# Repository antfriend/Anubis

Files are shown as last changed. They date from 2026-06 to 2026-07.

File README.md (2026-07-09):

# Anubis RC Controller Daughterboard

**A compact open-hardware support board for a DIY ESP32-S3 RC transmitter.**

Anubis is an open hardware and open firmware RC controller project built around accessible DIY parts, modern radio-control features, and a design that builders can understand, repair, modify, and improve.

This repository contains the custom daughterboard for the Anubis controller. It sits under a Hosyond 2.8 inch ESP32-S3 display board and turns the early wiring-heavy prototype into a cleaner, more repeatable hardware platform.

## Mission

The goal is simple: make a capable, repairable, hackable transmitter that is not locked behind a black box.

The first Anubis prototype used off-the-shelf modules wired together by hand: display board, power switches, regulators, analog input boards, GPIO expanders, gimbal connectors, and radio wiring. That is a great way to prove an idea, but it gets messy fast. This daughterboard pulls those support circuits onto a purpose-built PCB while leaving the Hosyond ESP32-S3 board as the main brain, display, touch interface, and firmware target.

Anubis is meant for experimentation as much as use. Builders should be able to change pin mappings, adapt connectors, swap radio hardware, and tune the firmware for their own transmitter layout.

## At A Glance

| Area | Current Direction |
| --- | --- |
| Main controller | Hosyond 2.8 inch ESP32-S3 display/dev board |
| Battery system | 2S LiPo or two 18650 cells as a 2S pack |
| Charging input | USB-C 5 V input, 500 mA to 1.5 A charge target |
| Switched outputs | `+5V_SW` and `+3V3_SW` accessory rails |
| Analog inputs | Two onboard ADS1115 ADCs, up to 8 analog channels |
| GPIO expansion | MCP23017 16-bit I2C GPIO expander |
| Radio paths | ELRS/CRSF over UART and optional ESP-NOW |
| Assembly goal | As much JLCPCB assembly as practical |
| Project status | Prototype hardware, ready for assembled-board validation |

## Core Design Goals

- Use common, hobby-accessible parts where possible.
- Keep the project open enough for community modification.
- Support modern RC workflows such as ELRS and ESP-NOW.
- Reduce hand wiring compared with the early prototype.
- Make the board practical for JLCPCB assembly.
- Keep external accessory power switchable from firmware.
- Leave room for manual wiring where real-world modules and harnesses vary.

## Hardware Overview

The daughterboard adds the support electronics around the Hosyond ESP32-S3 board:

- USB-C 5 V input for charging and power input.
- Standard 2S LiPo balance connector for the battery pack.
- Support for a 2S LiPo pack or two 18650 cells configured as a 2S pack.
- 2S battery gauge/protection circuitry based around `BQ28Z610DRZR-R1`.
- Dual-FET protection/power path using `CSD83325L`.
- Switched 5 V rail for UART/ELRS-side accessories.
- Switched 3.3 V rail for I2C, analog, and low-voltage peripherals.
- Two Pololu mini pushbutton power switch modules for rail control.
- Two onboard ADS1115 ADC circuits for up to eight analog inputs.
- One onboard MCP23017 GPIO expander for buttons and digital expansion.
- JST and pin-header breakouts for UART, I2C, GPIO, gimbals, and accessories.
- ESD protection for external signal connections.
- Ground plane and wider routing rules for higher-current power paths.

## Power Rails

| Rail | Intended Use | Approximate Max Current |
| --- | --- | --- |
| USB-C input | 5 V charge/input source | 500 mA to 1.5 A charge target |
| `+5V_SW` | ELRS/UART-side accessory power | about 1 A |
| `+3V3_SW` | I2C, ADCs, MCP23017, gimbals, sensors | about 500 mA |

The switched rails are controlled through the two Pololu #2808 mini pushbutton power switch modules. The ESP32-S3 can shut down attached devices without relying on the attached devices to behave nicely.

## Firmware Map

The main Anubis firmware runs on the Hosyond ESP32-S3 board. Current daughterboard-aware firmware support includes:

- Touchscreen UI for transmitter settings.
- Model storage and configuration.
- Stick calibration.
- Expo, rates, trims, endpoints, failsafe, and mixing.
- ELRS/CRSF support over UART.
- ESP-NOW transmitter support.
- Dual ADS1115 support for onboard analog inputs at `0x48` and `0x49`.
- MCP23017 GPIO expander support at `0x20`.
- Battery monitoring and deep-sleep behavior.

### Pin Assignments

| Function | ESP32-S3 Pin |
| --- | --- |
| I2C SDA | GPIO16 |
| I2C SCL | GPIO15 |
| ELRS/UART TX | GPIO44 |
| ELRS/UART RX | GPIO43 |
| Battery ADC | GPIO9 |
| 5 V rail switch control | GPIO2 |
| 3.3 V rail switch control | GPIO3 |
| Deep-sleep/wake button sense | GPIO14 |
| Deep-sleep/wake button reference | GPIO21 |

GPIO2 and GPIO3 control the two Pololu rail-switch modules. GPIO14 and GPIO21 route to the two-pin deep-sleep/wake pushbutton header. UART-to-ELRS wiring can still be crossed manually if a specific module harness expects the opposite order.

### I2C Devices

| Device | Address | Role |
| --- | --- | --- |
| ADS1115 primary | `0x48` | Four gimbal/stick analog axes |
| ADS1115 auxiliary | `0x49` | Spare analog inputs |
| MCP23017 | `0x20` | GPIO expansion and active-low button/switch inputs |
| BQ25887 charger | `0x6B` | 2S charger status and pack voltage reporting |

## Control Hardware

The controller is designed around parts that are easy for hobby builders to source or substitute:

- Hosyond 2.8 inch ESP32-S3 display board as the main controller.
- RadioMaster Pocket/Zorro X5-style gimbals.
- ELRS module support through UART/CRSF.
- Optional ESP-NOW receiver support for WiFi-equipped ESP32 receivers.
- D-pad/button input through the MCP23017 GPIO expander.
- Auxiliary analog inputs through the ADS1115 circuits.

The mechanical layout fits around the Hosyond board and controller shell constraints. The Hosyond board sits above the daughterboard on standoffs, with the daughterboard occupying the surrounding and lower internal space.

## Repository Contents

| Path | Purpose |
| --- | --- |
| `Daughterboard.kicad_pro` | KiCad project file |
| `Daughterboard.kicad_sch` | Main schematic |
| `Daughterboard.kicad_pcb` | PCB layout |
| `Daughterboard.kicad_sym` | Project symbols |
| `Daughterboard.pretty/` | Custom KiCad footprints |
| `Daughterboard.net` | Exported netlist |
| `Daughterboard_pcb_bom.csv` | Human-readable PCB BOM |
| `Daughterboard_current_jlc_part_audit.csv` | JLC part audit/reference |
| `fabrication/` | Fabrication and assembly outputs |
| `daughterboard2.dxf` | Board outline reference |
| `Daughterboardv2.step` | Mechanical board reference |
| `PROJECT_CONTEXT.md` | Detailed working context for future development |

Current fabrication package:

```text
fabrication/jlcpcb_2026-07-06_r12.zip
```

Assembly files are included under:

```text
fabrication/jlcpcb_2026-07-06_r12/assembly/
```

## Manufacturing Notes

The board is being prepared for JLCPCB assembly with as many populated parts as practical. The Pololu mini pushbutton power switch modules are treated as separately installed modules. Some through-hole headers may also be hand-installed unless through-hole assembly is explicitly ordered.

Before ordering boards, always check:

- KiCad ERC and DRC reports.
- Copper clearance and board-edge clearance.
- Unrouted nets.
- Connector orientation.
- IC pin 1 orientation.
- JLCPCB part availability.
- BOM and CPL alignment in the JLCPCB preview.

Known current status from the latest R12 fabrication pass:

- ERC reports no errors or warnings.
- DRC contains known/accepted clearance and silkscreen warnings.
- The known clearance items are around the battery-management IC package and are small differences from the configured rule.
- Silkscreen warnings should not normally prevent fabrication.
- Copper, drill, outline, missing-net, and footprint-orientation issues should be treated as critical.

## Battery And Power Safety

This board works with lithium battery packs and charging/protection circuitry. Mistakes can damage hardware or create a safety hazard.

Do not assume a PCB revision is safe just because the schematic opens or the Gerbers generate. Review the battery path, charger configuration, protection FETs, current limits, connector polarity, and pack wiring before connecting real cells.

Use protected cells or a known-good 2S pack during testing. Current-limit the first power-up and verify rails with a meter before plugging in the Hosyond board or radio hardware.

## Project Status

This hardware is still a prototype until assembled boards are tested.

Open work includes:

- Validate the physical PCB after manufacturing.
- Confirm all connector orientations in the assembled board.
- Test the updated firmware GPIO assignments against the first assembled daughterboard.
- Verify 2S battery reporting and charger/fuel-gauge behavior on hardware.
- Confirm the auxiliary ADS1115 inputs and MCP23017 pads behave as expected with real devices attached.
- Test ELRS and ESP-NOW behavior in the finished controller.
- Document assembly steps after the first successful build.

## Contributing

Anubis is meant to be community driven. Contributions are welcome in the form of firmware changes, PCB review, mechanical improvements, documentation, testing notes, alternate part suggestions, and build reports.

If you change the hardware, include enough context for another builder to understand why the change was made. If you change the firmware, document the pin assumptions and hardware revision you tested against.

## Companion Project

The firmware and receiver-side code for the broader Anubis controller project are hosted with the main project:

```text
https://github.com/BoomBoxRobotics/Anubis
```

This daughterboard is one hardware path toward that larger goal: a capable open source RC controller that builders can actually understand, repair, and make their own.

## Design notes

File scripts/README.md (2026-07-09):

# Anubis firmware build & flash scripts

PowerShell helpers for building and uploading the **Hosyond transmitter**
firmware ([../Hosyond_apr24b/](../Hosyond_apr24b/)) to a Hosyond 2.8" ESP32-S3
(N16R8) board with `arduino-cli` + `esptool`, plus PCB fabrication checks for
the **Daughterboard** KiCad project (see [PCB scripts](#pcb-fabrication-scripts)).

## One-time setup (per machine)

```powershell
scripts\setup-libraries.ps1
```

Installs the ESP32 core and the three required libraries, then copies the repo's
[../User_Setup.h](../User_Setup.h) into the TFT_eSPI library.

| Dependency | Source | Provides |
|---|---|---|
| `esp32:esp32` core | Boards Manager | ESP32-S3 toolchain |
| `TFT_eSPI` | registry | ILI9341 display driver (configured via `User_Setup.h`) |
| `RAK14014-FT6336U` | registry | FT6336U capacitive touch |
| `audio-driver` | Git ([pschatzmann](https://github.com/pschatzmann/arduino-audio-driver)) | `AudioBoard.h`, `AudioDriverES8311` |

> TFT_eSPI is configured by a header **inside the library**, not per-sketch.
> `setup-libraries.ps1` overwrites `libraries/TFT_eSPI/User_Setup.h` with the
> repo copy (backing up the original to `User_Setup.h.orig`). Re-run it if you
> ever update the library or change pin config.

## Everyday use

| Task | Command |
|---|---|
| Compile only | `scripts\build.ps1` |
| Flash prebuilt image (no recompile) | `scripts\flash.ps1` |
| Compile **and** upload (normal dev loop) | `scripts\build-and-flash.ps1` |

All flash/upload scripts auto-detect the ESP32 COM port. Override with
`-Port COM7` if detection picks the wrong device.

## Board / build settings (in `_common.ps1`)

- **FQBN:** `esp32:esp32:esp32s3:FlashSize=16M,PartitionScheme=app3M_fat9M_16MB`
- **Sketch:** `Hosyond_apr24b/`
- **Flash mode:** dio @ 80 MHz, 16 MB
- Merged image written at `0x0`; serial monitor baud `115200`.

## Download mode

If the board isn't detected: hold **BOOT**, tap **RESET**, release BOOT to force
ROM download mode, then retry. After flashing, the USB-CDC port may re-enumerate
(possibly to a new COM number) a few seconds after reset.

## PCB fabrication scripts

For the [../Daughterboard/](../Daughterboard/) KiCad project. Both need
`kicad-cli` (KiCad 10): `winget install KiCad.KiCad`. The helper in
`_common.ps1` finds it on PATH, in `%LOCALAPPDATA%\Programs\KiCad`, or in
`Program Files\KiCad`.

| Task | Command |
|---|---|
| Gate the newest `fabrication\jlcpcb_*` package | `scripts\pcb-check.ps1` |
| Gate a specific package | `scripts\pcb-check.ps1 -PackageDir <path>` |
| Static gates only (no KiCad needed) | `scripts\pcb-check.ps1 -StaticOnly` |
| Build + gate a new fab package | `scripts\pcb-release.ps1 -Rev r13` |

`pcb-check.ps1` gates: ERC, DRC + schematic parity, Gerber/drill freshness
(re-export and diff against the package, ignoring timestamp/version headers),
package integrity (all layers present, upload zip matches loose files), fab
metadata (revision and copper finish set in the board file), and BOM/CPL
consistency (every placed part has an LCSC number). Exits nonzero if any gate
fails — **run it before uploading anything to JLCPCB.**

`pcb-release.ps1 -Rev rNN` builds `Daughterboard\fabrication\jlcpcb_<date>_rNN\`
(gerbers, drill + map, ERC/DRC reports, position file, JLC CPLs, JLC BOM carried
forward from the previous package with a designator reconcile report), zips the
JLC upload archive and the whole package, then runs `pcb-check.ps1` on the
result. It refuses to bless a package that fails any gate.

Notes:

- Packages from r13 on use KiCad's native `.gbr` layer extensions (older
  packages used Protel `.gtl`/`.gbl`); JLCPCB accepts both.
- The JLC BOM is carried forward, not regenerated — new parts appear in
  `assembly\Daughterboard_bom_reconcile_report.txt` and need LCSC numbers added
  by hand. Hand-soldered parts (18650 holders, Pololu switch modules, headers)
  are expected in the "not in BOM" list.
- JLC's part rotations sometimes differ from KiCad's; always eyeball the
  component preview during JLCPCB order review.

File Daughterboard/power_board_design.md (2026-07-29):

# USB-C 2S LiPo / 2x18650 Power Board Design

## Goal

Small KiCad board that accepts 5 V from USB-C, charges a 2S Li-ion/LiPo pack, and generates switched 5 V and 3.3 V rails for external devices controlled by the Hosyond ESP32-S3 display board.

The battery source is now selectable by population/use:

- External 2S LiPo pack through `J7`, a 3-pin JST-XH style balance connector: `B-`, `CELL_MID`, `B+`.
- Two installed 18650 cells in series through `BT1` and `BT2`.

Use either the external 2S pack on `J7` or installed 18650 cells, not both at the same time.

## Architecture

```mermaid
flowchart LR
    USBC["USB-C receptacle\n5 V sink"] --> INPROT["VBUS fuse, TVS,\nCC1/CC2 Rd"]
    INPROT --> CHG["BQ25887RGE\n2S boost charger"]
    CHG <--> PROT["BQ28Z610 + 2x CSD18502Q5B\nhigh-side 2S protection"]
    PROT <--> PACK["Raw 2S pack nets\nBATT_RAW_N / CELL_MID / BATT_RAW_P"]
    CELLS["2x 18650 in series"] <--> PACK
    BAL["J7 2S balance lead"] <--> PACK
    PROT --> SYS["+BAT_SYS protected\nsystem/charger positive"]
    SYS --> BUCK5["AP63200WU\n5 V buck"]
    SYS --> BUCK3["AP63200WU\n3.3 V buck"]
    BUCK5 --> SW5["Pololu #2808\n5 V switch"]
    BUCK3 --> SW3["Pololu #2808\n3.3 V switch"]
    ESP["Hosyond ESP32-S3\nGPIO2/GPIO3"] --> SW5
    ESP --> SW3
    SW5 --> R5["+5V_SW"]
    SW3 --> R3["+3V3_SW"]
    R3 --> GPIOX["MCP23017\n16 GPIO solder pads"]
```

## Main Components

| Function | Rev-A part | Notes |
|---|---|---|
| USB-C 5 V sink | USB-C receptacle plus 5.1 kOhm CC pulldowns | Power-only Type-C input, no USB-PD. |
| 2S charger | TI `BQ25887RGE` | 5 V boost-mode charger for 2-cell Li-ion/LiPo packs with midpoint/balance connection. |
| 2S gauge/protection | TI `BQ28Z610DRZR-R1` + 2x TI `CSD18502Q5B` | 1S/2S Impedance Track gauge/protection controller with high-side N-FET charge/discharge control and current sense. Requires BQStudio/data-flash setup. |
| 5 V regulator | Diodes Inc. `AP63200WU` | 2S-to-5 V buck, target load 1 A max. |
| 3.3 V regulator | Diodes Inc. `AP63200WU` | 2S-to-3.3 V buck, target load 500 mA max. |
| Rail switches | Pololu #2808 modules | Switches are after the regulators; ESP32 GPIO2 controls 5 V, GPIO3 controls 3.3 V. |
| Analog inputs | 2x TI `ADS1115IDGS` | Powered from `+3V3_SW`, so ADCs and connected 3.3 V sensors shut down with the switched rail. |
| GPIO expander | Microchip `MCP23017-E/SO` | 16-bit I2C GPIO expander powered from `+3V3_SW`; default address `0x20`. |

## Battery Nets

- `BATT_RAW_N`: raw 2S pack negative / lower cell negative before the current-sense resistor.
- `GND`: protected board/load/charger negative after the current-sense resistor.
- `CELL_MID`: lower cell positive and upper cell negative.
- `BATT_RAW_P`: raw upper-cell positive / raw 2S pack positive.
- `FET_MID_COMMON`: common **drain** node between the high-side charge/discharge FETs (r17; replaces the r16 `FET_SRC_COMMON` common-source node).
- `FET_BATT_P`: raw-cell-side node after `F4`; the **source** of the high-side charge FET.
- `BAT_SYS`: protected 2S system/charger positive bus feeding the charger BAT/SNS pins and both buck regulators.

The two 18650 holders are now series-connected:

- `BT1`: lower cell, negative to `BATT_RAW_N`, positive through `F2` to `CELL_MID`.
- `BT2`: upper cell, negative to `CELL_MID`, positive through `F3` to `BATT_RAW_P`.
- `J7`: external 2S balance input, pin 1 `BATT_RAW_N`, pin 2 `CELL_MID`, pin 3 `BATT_RAW_P`.

## 2S Protection

The old single-cell `BQ297xy` protection IC is not valid for a 2S pack, and the ABLIC `S-8252AAH-M6T1U` was replaced because the available purchasing terms were not practical for prototypes. The active schematic now uses TI `BQ28Z610DRZR-R1`, which combines 1S/2S fuel gauging, programmable protection, I2C communication, current sensing, and external charge/discharge FET control.

R14 BQ28Z610 support parts:

- `R14`, `R15`: 470 ohm cell-sense input resistors for `VC2` and `VC1`.
- `C25`, `C26`: 100 nF cell-sense filter capacitors.
- `R16`: 100 ohm `PACK` input series resistor from `BAT_SYS` to `BQ_PACK`.
- `C30`: 2.2 uF `PBI` hold-up capacitor to `BATT_RAW_N`.
- `R46`: 2 milliohm current-sense resistor in series between `BATT_RAW_N` and protected `GND`; Kelvin route both ends.
- `R47`, `R48`, `C31`: 100 ohm / 100 nF `SRN`/`SRP` differential input filter. `SRP` now Kelvin-senses the raw-cell-negative side of `R46`; `SRN` senses the protected/system-ground side.
- `R21`, `R22`: 100 ohm gate-drive series resistors from `BQ_DSG` and `BQ_CHG`.
- `Q1`: `CSD18502Q5B` high-side charge FET, source pins 1-3 on `FET_BATT_P`, gate pin 4 on `CO_GATE`, and drain pins 5-8 plus the main drain island on `FET_MID_COMMON`.
- `Q2`: `CSD18502Q5B` high-side discharge FET, source pins 1-3 on `BAT_SYS`, gate pin 4 on `DO_GATE`, and drain pins 5-8 plus the main drain island on `FET_MID_COMMON`.
- `R49`, `R50`: 10 Mohm gate-source bleed resistors, each returning to its own FET's source: `R50` `CO_GATE` to `FET_BATT_P`, `R49` `DO_GATE` to `BAT_SYS`.
- `C32`, `C33`: 100 nF capacitors across the high-side FETs for ESD/transient handling per TI layout guidance.
- `F4`: high-side battery path fuse between `FET_BATT_P` and `BATT_RAW_P`.

R14 release note: the previous low-side dual-FET topology was removed because it was incompatible with the BQ28Z610 high-side gate driver. R14 keeps the corrected high-side topology and swaps Q1/Q2 to JLC-available `CSD18502Q5B` FETs using the project-local TI DNK/VSON-CLIP footprint. The charger `BAT/SNS` pins and the buck-regulator input bus are on `BAT_SYS`, so charge and discharge current pass through the high-side protection FETs and through `R46`.

R17 release note (corrects a fault found on the fabricated r16 board): r14 through r16 wired Q1/Q2 **common-source**, with the shared node floating between the two FETs. That is wrong for the BQ28Z610. The device's two gate outputs are referenced to two *different* nodes -- SLUSAS3D 8.3.13: when drive is disabled "an internal circuit discharges `CHG` to `VC2` and `DSG` to `PACK`" -- so the two FETs must have two different sources, which forces a **common-drain** pair with each source facing its own outer terminal. With the r16 common-source wiring the shared node was undriven (both body diodes point outward from it), so off-state Vgs was undefined and the protection FETs were never properly commanded. r17 re-orients the pair:

```
FET_BATT_P --[Q1 S..D]-- FET_MID_COMMON --[Q2 D..S]-- BAT_SYS
(raw cells, post-F4)     (common drain)              (protected system = U2 PACK sense)
```

Each gate bleed now returns to its own FET's source, so both FETs have a defined off state. Two further r16 field faults are corrected in the same spin: `D2`/`D3` had the anode on pad 1, but KiCad's `LED_0603_1608Metric` pad 1 is the **cathode**, so both status LEDs were reverse-biased; and `J7` moves from the front edge to the rear edge (rotated 180 deg), which reverses its pin order along X and corrects the reversed battery polarity. `J7`'s netlist pin assignment is deliberately unchanged -- swapping the pin 1 / pin 3 nets as well would reintroduce the fault.

The protector does not set the normal charge current. The BQ25887 charger should be configured so USB-C charging is firmware-limited from 500 mA minimum up to 1.5 A maximum, with the hardware input-current limit also held at or below 1.5 A.

## Regulator Population

The 1S boost/buck-boost regulators were replaced because a 2S pack ranges roughly from discharged to 8.4 V full charge.

- `U3`: `AP63200WU` configured for 5 V with `R8 = 523 kOhm` and `R9 = 100 kOhm`.
- `U4`: `AP63200WU` configured for 3.3 V with `R11 = 316 kOhm` and `R12 = 100 kOhm`.
- `L1` and `L2`: 4.7 uH shielded inductors.
- Input capacitors on `BAT_SYS` are rated 16 V.
- Output capacitors are rated at least 10 V.

## Switched Outputs And Signals

- `SW1` Pololu #2808: `+5V` in, `+5V_SW` out, control through `CTRL_5V_SW` from ESP32 `GPIO2`.
- `SW2` Pololu #2808: `+3V3` in, `+3V3_SW` out, control through `CTRL_3V3_SW` from ESP32 `GPIO3`.
- `J4`: 5-pin 1.25 mm JST UART header with `+5V_SW`, GND, TX, RX, GND.
- `J5`: 4-pin 2.54 mm I2C header with `+3V3_SW`, GND, SDA, SCL.
- `J6`: 2-pin deep-sleep pushbutton header between `GPIO14` and `GPIO21`.
- `J3x`: individual solder pads for the Hosyond board wires.

## MCP23017 GPIO Expander

The daughterboard now includes `U7`, a Microchip `MCP23017-E/SO` 16-bit I2C GPIO expander in SOIC-28W.

- `VDD`: `+3V3_SW`, so the expander shuts down with the switched 3.3 V rail.
- `VSS`: protected `GND`.
- `SDA` / `SCL`: shared `I2C_SDA` / `I2C_SCL` bus with the ADS1115s.
- Address pins `A0`, `A1`, and `A2`: default 0 ohm straps to GND, giving address `0x20`.
- `RESET`: 10 kOhm pullup to `+3V3_SW` and 100 nF reset capacitor to GND.
- `INTA` / `INTB`: 10 kOhm pullups to `+3V3_SW` and individual solder pads.
- GPIO outputs: `GPA0..GPA7` and `GPB0..GPB7` each pass through a 100 ohm series resistor to an individual solder pad.
- ESD placeholders: four 4-channel 3.3 V TVS/ESD arrays protect the external pad side of the 16 GPIO lines.
- `GPA7` and `GPB7`: treat as output-only unless the exact MCP23017 variant/revision is verified for input use.

Because the MCP23017 is powered from `+3V3_SW`, firmware should enable the 3.3 V switched rail before using the I2C bus for the expander. The ADS1115 pullups are also on `+3V3_SW`, so the switched 3.3 V rail is the intended I2C pullup source for the daughterboard devices.

## Generated Files

- `Daughterboard.kicad_sch`: generated pin-level schematic.
- `Daughterboard.kicad_sym`: project-local symbols.
- `Daughterboard_pinlevel_bom.csv`: generated BOM with purchase-link column.
- `Daughterboard_pcb_bom.csv`, `pcb_component_schedule.csv`, `starter_bom_and_nets.csv`, and `starter_bom_and_nets_with_links.csv`: synced BOM copies.
- `Daughterboard_pinlevel.pdf` and `Daughterboard_pinlevel_preview.png`: exported schematic preview.
- `Daughterboard_pinlevel_erc.rpt`: KiCad ERC report.

## Footprint Policy

The design is space-constrained, so rev-A uses SMD footprints for nearly all normal components:

- Fuses/PTCs: 1206 SMD fuse footprints.
- NTC: 0603 SMD thermistor footprint.
- Buck/charger inductors: compact shielded SMD inductor footprints.
- Resistors/capacitors: 0603/0805 SMD as listed in the BOM.
- Hosyond and MCP23017 wire breakouts: flat 1.5 mm SMD test pads.
- ICs, ESD arrays, FETs, charger, regulators, ADCs, and MCP23017: SMD packages.

The intentional exceptions are mechanical/interface parts: USB-C, 18650 holders, Pololu switch modules, JST connectors, and 2.54 mm pin headers. Those connector styles were left unchanged.

## Sources

- TI BQ25887 product/datasheet: https://www.ti.com/product/BQ25887
- TI BQ28Z610 product/datasheet: https://www.ti.com/product/BQ28Z610
- TI CSD18502Q5B product/datasheet: https://www.ti.com/product/CSD18502Q5B
- Diodes Inc. AP63200/AP63201/AP63203/AP63205 datasheet: https://www.diodes.com/assets/Datasheets/AP63200-AP63201-AP63203-AP63205.pdf
- Microchip MCP23017 datasheet: https://ww1.microchip.com/downloads/aemDocuments/documents/APID/ProductDocuments/DataSheets/MCP23017-Data-Sheet-DS20001952.pdf
- Pololu #2808 Mini Pushbutton Power Switch LV: https://www.pololu.com/product/2808

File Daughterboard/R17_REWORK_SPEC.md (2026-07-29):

# r17 Rework Spec — three faults found on the fabricated r16 board

Written 2026-07-29. Supersedes the r16 release for `Daughterboard/`.

Schematic, netlist, BOM CSVs, design doc and topology verifier are **already updated** in this
commit. What remains is PCB placement and routing, which is done by hand in the KiCad GUI.

Verify at any point with:

```
%LOCALAPPDATA%\Programs\KiCad\10.0\bin\python.exe verify_r17_power_topology.py
```

It currently reports `FAIL` with 28 items — that list *is* the rework checklist. When it prints
`PASS`, the board matches the corrected schematic.

---

## Fault 1 — J7 battery connector polarity (placement fix)

**Symptom:** pack plugs in reverse-polarity.

**Cause:** `J7` (`JST_XH_S3B-XH-A_1x03_P2.50mm_Horizontal`) sits on the **front** edge at
`(70.6, 16.5) rot 180`, which puts pin 1 (`BATT_RAW_N`) at X=70.6 and pin 3 (`BATT_RAW_P`) at
X=65.6 — the opposite of the pack lead's handedness.

**Fix — move it to the rear edge and rotate 180°.** Moving the connector reverses the pin order
along X, which is what corrects the polarity. Pin 2 (`CELL_MID`) is centred and unaffected.

| | r16 | r17 |
|---|---|---|
| origin | `(70.6, 16.5)` rot 180 | **`(65.6, 84.11)` rot 0** |
| pin 1 `BATT_RAW_N` | X = 70.60 | **X = 65.60** |
| pin 2 `CELL_MID` | X = 68.10 | X = 68.10 |
| pin 3 `BATT_RAW_P` | X = 65.60 | **X = 70.60** |

`(65.6, 84.11)` mirrors the r16 geometry exactly: same three pad X coordinates, and the same
3.19 mm body overhang past the board edge (courtyard Y 81.29–93.80 against the rear edge at
Y = 90.61, matching the front-edge case of 6.80–19.31 against Y = 10.00). The whole rear strip
above Y = 76 is empty, so there is nothing to displace.

> **Do not also swap the pin 1 / pin 3 nets.** The netlist assignment
> (`1 = BATT_RAW_N`, `2 = CELL_MID`, `3 = BATT_RAW_P`) is deliberately unchanged. The physical
> flip *is* the fix; doing both cancels out and reintroduces the fault.

**Routing:** `BATT_RAW_P` (J7.3 → F4.2) and `BATT_RAW_N` (J7.1 → R46/R48/U2 VSS) now run from the
rear edge instead of the front. Keep the r16 rule: **1.0 mm trace throughout with 1.0/0.5 mm power
vias** on `BATT_RAW_P`; narrow branches are allowed only for voltage-sense and test points.
`CELL_MID` (J7.2 → BT2.2 / U1.9 / R15) is a sense-level net.

---

## Fault 2 — D2 / D3 status LEDs reversed (net fix, already in the schematic)

**Symptom:** neither status LED lights.

**Cause:** the schematic drives both LEDs from a generic `Daughterboard:TWO_PIN` symbol and put
the anode net on **pad 1** — but KiCad's `LED_SMD:LED_0603_1608Metric` footprint has **pad 1 as the
CATHODE** (confirmed in the footprint: the F.SilkS polarity bar and the F.Fab cathode bar are both
on the pad-1 side, at local X = −0.7875). Both LEDs were therefore reverse-biased and could never
conduct.

**Fix (already applied to `generate_pinlevel_schematic.py` and `daughterboard.kicad_sch`):**

| ref | r16 pad 1 | r16 pad 2 | **r17 pad 1 (K)** | **r17 pad 2 (A)** |
|---|---|---|---|---|
| D2 (green, CHG) | `LED_CHG_A` | `CHG_STAT` | **`CHG_STAT`** | **`LED_CHG_A`** |
| D3 (blue, PGOOD) | `LED_PGOOD_A` | `PG_STAT` | **`PG_STAT`** | **`LED_PGOOD_A`** |

Current path is now correct: `REGN` → R6/R7 → anode (pad 2) → cathode (pad 1) → U1 `STAT` / `PG`
open-drain pin, which pulls low to light the LED.

**Routing:** D2 `(19.81, 75.30)` and D3 `(24.11, 75.40)` do not move — only the two short local
traces at each part swap ends. Signal-level, no width requirement.

---

## Fault 3 — Q1 / Q2 driven incorrectly by U2 (the blocker)

**Symptom:** the BQ28Z610 cannot command the protection FETs.

**Cause: r14–r16 wired the pair common-SOURCE. The BQ28Z610 requires common-DRAIN.**

The device's two gate drivers are referenced to two *different* nodes. TI SLUSAS3D §8.3.13: when
drive is disabled, "an internal circuit discharges **CHG to VC2** and **DSG to PACK**". Two
different off-state gate references means the two FETs must have two different sources — which
forces a common-drain pair with each source facing its own outer terminal. §7.25 then specifies
on-state `V(FETON)` as 8.75–10.25 V **above VC2**, which only yields a sane Vgs if each source sits
at ≈VC2.

On the r16 board both sources were tied together at `FET_SRC_COMMON`, and that node is **undriven** —
both body diodes point outward from it, so nothing defines its potential. Consequences:

- **Off never happens.** "Off" parks `CHG` at VC2 (≈8.4 V) while the source floats near 0 V, so
  Vgs stays far above threshold.
- **On is not reliable either.** The only DC paths to the shared node are the two 10 MΩ bleeds,
  which drag it toward whatever the gates are doing, so Vgs collapses toward 0.

Either way the protection is non-functional. This is the same class of error flagged as F1 in
`q1_power_path_review.md`; the r14 FET swap fixed the *part* but re-introduced the orientation
error, and `R16_REVIEW_NOTES.txt` then codified "common-source high-side topology" as if intended.

### Corrected topology

```
FET_BATT_P ──[ Q1  S..D ]── FET_MID_COMMON ──[ Q2  D..S ]── BAT_SYS
(raw cells, post-F4)         (common drain)                 (protected system,
                                                             = U2 PACK sense via R16)

Q1 = CHG FET   source FET_BATT_P (≈VC2)   gate CO_GATE ← R22 ← U2.9 CHG
Q2 = DSG FET   source BAT_SYS   (≈PACK)   gate DO_GATE ← R21 ← U2.7 DSG
```

Body-diode check: Q1's diode conducts `FET_BATT_P → MID`, Q2's conducts `BAT_SYS → MID`. Both point
inward, so discharge (battery → system) requires Q2 on and charge (system → battery) requires Q1 on —
each FET gates exactly the direction its name implies.

### Pad-level net changes

| ref | pads | r16 net | **r17 net** |
|---|---|---|---|
| Q1 | 1, 2, 3 (S) | `FET_SRC_COMMON` | **`FET_BATT_P`** |
| Q1 | 5, 6, 7, 8 (D) | `BAT_SYS` | **`FET_MID_COMMON`** |
| Q1 | 4 (G) | `CO_GATE` | `CO_GATE` (unchanged) |
| Q2 | 1, 2, 3 (S) | `FET_SRC_COMMON` | **`BAT_SYS`** |
| Q2 | 5, 6, 7, 8 (D) | `FET_BATT_P` | **`FET_MID_COMMON`** |
| Q2 | 4 (G) | `DO_GATE` | `DO_GATE` (unchanged) |
| R50 | 2 | `FET_SRC_COMMON` | **`FET_BATT_P`** (Q1's own source) |
| R49 | 2 | `FET_SRC_COMMON` | **`BAT_SYS`** (Q2's own source) |
| C32 | 1 / 2 | `BAT_SYS` / `FET_SRC_COMMON` | **`FET_BATT_P` / `FET_MID_COMMON`** |
| C33 | 1 / 2 | `FET_BATT_P` / `FET_SRC_COMMON` | **`BAT_SYS` / `FET_MID_COMMON`** |

The 10 MΩ bleeds splitting to two different nodes is not cosmetic — it is what gives each FET a
defined off state, and it is the load condition under which TI specifies the §7.25 drive levels.

`R16` (`BAT_SYS` → `BQ_PACK`) is unchanged and is now correct by construction: U2's `PACK` pin
senses `BAT_SYS`, which is exactly the DSG FET's source, so the DSG-off gate discharge references
the right potential.

### Placement — nothing needs to move

This is the convenient part. The existing placement already suits the corrected topology, because
each part stays adjacent to the FET it belongs to:

| ref | position | role after fix |
|---|---|---|
| F4 | `(20.80, 47.80)` | feeds `FET_BATT_P` |
| Q1 | `(32.70, 48.51)` rot 0 | ~12 mm from F4 — battery-side source ✔ |
| R50 | `(28.10, 48.62)` rot 90 | beside Q1, gate bleed to `FET_BATT_P` ✔ |
| C32 | `(38.50, 48.58)` rot 90 | across Q1 ✔ |
| Q2 | `(17.30, 29.50)` rot 180 | beside U1 `(30, 34)` — system-side source ✔ |
| R49 | `(12.40, 29.43)` rot 90 | beside Q2, gate bleed to `BAT_SYS` ✔ |
| C33 | `(22.80, 29.88)` rot 90 | across Q2 ✔ |

Power flow is actually cleaner than r16: battery → F4 → Q1 → mid → Q2 → `BAT_SYS` → U1/U3/U4,
instead of r16's 18 mm out-and-back on `FET_BATT_P`.

### Routing

Rip up and re-route `FET_BATT_P`, `BAT_SYS`, and the new `FET_MID_COMMON` around Q1/Q2. All three
are full pack-current nets — apply the r16 standard: **1.0 mm throughout, 1.0/0.5 mm power vias**.

`FET_MID_COMMON` is new and carries full current across roughly 24 mm between the two drain
islands `(32.70, 48.51)` → `(17.30, 29.50)`; give it the same treatment as `FET_BATT_P`, and use the
drain clip islands as copper pours rather than a single trace where you can.

---

## Verification before releasing r17

1. `verify_r17_power_topology.py` prints **PASS**.
2. Schematic ERC clean. (Headless `kicad-cli` reports ~157 `footprint_link_issues` warnings because
   the global footprint library table isn't visible to it — those are environment noise, not design
   violations. Run ERC in the GUI for a clean read.)
3. PCB DRC: 0 errors, 0 unconnected. Note the long-standing 6 U1/BQ25887 clearance items
   (~0.20–0.225 mm against the 0.25 mm project rule, within JLC capability) — still non-blocking.
4. `scripts\pcb-release.ps1 -Rev r17`, then confirm all 6 gates pass.
5. Bench-validate the protection trips via BQStudio data-flash configuration before trusting a
   live pack — this gate was never closed on r14/r15/r16 and would have caught Fault 3.

---

## Can the existing r16 boards be salvaged?

- **J7 polarity — yes, no board change.** Re-pin the pack lead (swap the crimps in positions 1 and
  3) or make a reversing pigtail. Label it clearly; it will not be interchangeable with r17 boards.
- **D2 / D3 — yes, trivial.** Install the 0603 LEDs rotated 180° from the silkscreen.
- **Q1 / Q2 — not practically.** The fix needs the shared source node cut and both FETs re-oriented
  under VSON-CLIP packages. For bench bringup of the *rest* of the board you can bypass the
  protection stage entirely by strapping `FET_BATT_P` to `BAT_SYS` (jumper F4.1 to the Q1 drain
  island) and leaving Q1/Q2 unpopulated.

> Bypassing the FETs removes all pack overcurrent, overvoltage and undervoltage protection. Do that
> only on the bench, and only with a current-limited supply or a pack that has its own protection
> board. Do not leave a bypassed board connected to a bare lithium pack unattended.

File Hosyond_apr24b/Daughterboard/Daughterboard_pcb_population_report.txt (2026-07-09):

Daughterboard PCB population report
====================================
DXF outline vertices: 10
DXF edge-cut holes: 2
Placed footprints: 148
Missing/unplaced footprints: 3

Missing/unplaced footprints
---------------------------
BT1: 18650 Cell 1 lower -> no loadable footprint (blank)
BT2: 18650 Cell 2 upper -> no loadable footprint (blank)
J2: Switched power outputs -> no loadable footprint (blank)

Placed footprints
-----------------
J8: Connector_PinHeader_2.54mm:PinHeader_1x10_P2.54mm_Vertical @ 137.80,15.40 mm (Analog inputs) [fixed interface placement]
U5: Package_SO:TSSOP-10_3x3mm_P0.5mm @ 124.50,49.00 mm (Analog inputs) [fixed interface placement]
U6: Package_SO:TSSOP-10_3x3mm_P0.5mm @ 132.00,49.00 mm (Analog inputs) [fixed interface placement]
J31: TestPoint:TestPoint_Pad_1.5x1.5mm @ 58.50,20.00 mm (Control) [fixed interface placement]
J32: TestPoint:TestPoint_Pad_1.5x1.5mm @ 58.50,25.00 mm (Control) [fixed interface placement]
J33: TestPoint:TestPoint_Pad_1.5x1.5mm @ 117.00,18.00 mm (Control) [fixed interface placement]
J34: TestPoint:TestPoint_Pad_1.5x1.5mm @ 117.00,23.00 mm (Control) [fixed interface placement]
J35: TestPoint:TestPoint_Pad_1.5x1.5mm @ 117.00,28.00 mm (Control) [fixed interface placement]
J36: TestPoint:TestPoint_Pad_1.5x1.5mm @ 117.00,33.00 mm (Control) [fixed interface placement]
J37: TestPoint:TestPoint_Pad_1.5x1.5mm @ 117.00,38.00 mm (Control) [fixed interface placement]
J38: TestPoint:TestPoint_Pad_1.5x1.5mm @ 117.00,43.00 mm (Control) [fixed interface placement]
J39: TestPoint:TestPoint_Pad_1.5x1.5mm @ 58.50,30.00 mm (Control) [fixed interface placement]
U7: Package_SO:SOIC-28W_7.5x17.9mm_P1.27mm @ 156.00,66.00 mm (GPIO expander) [fixed interface placement]
SW1: Daughterboard:Pololu_2808_Raised_Header @ 46.00,20.00 mm (Output switching) [fixed interface placement]
SW2: Daughterboard:Pololu_2808_Raised_Header @ 88.00,40.00 mm (Output switching) [fixed interface placement]
J4: Connector_JST:JST_GH_SM05B-GHS-TB_1x05-1MP_P1.25mm_Horizontal @ 99.00,52.00 mm (Signals) [fixed interface placement]
J5: Connector_PinHeader_2.54mm:PinHeader_1x04_P2.54mm_Vertical @ 129.00,23.00 mm (Signals) [fixed interface placement]
J6: Connector_PinHeader_2.54mm:PinHeader_1x02_P2.54mm_Vertical @ 129.00,40.00 mm (Signals) [fixed interface placement]
TP1: TestPoint:TestPoint_Pad_D1.0mm @ 15.00,75.00 mm (Test pads) [fixed interface placement]
TP2: TestPoint:TestPoint_Pad_D1.0mm @ 20.00,75.00 mm (Test pads) [fixed interface placement]
TP3: TestPoint:TestPoint_Pad_D1.0mm @ 25.00,75.00 mm (Test pads) [fixed interface placement]
TP4: TestPoint:TestPoint_Pad_D1.0mm @ 15.00,80.00 mm (Test pads) [fixed interface placement]
TP5: TestPoint:TestPoint_Pad_D1.0mm @ 20.00,80.00 mm (Test pads) [fixed interface placement]
TP6: TestPoint:TestPoint_Pad_D1.0mm @ 15.00,85.00 mm (Test pads) [fixed interface placement]
TP7: TestPoint:TestPoint_Pad_D1.0mm @ 75.00,17.00 mm (Test pads) [fixed interface placement]
TP8: TestPoint:TestPoint_Pad_D1.0mm @ 35.00,66.00 mm (Test pads) [fixed interface placement]
TP9: TestPoint:TestPoint_Pad_D1.0mm @ 75.00,29.00 mm (Test pads) [fixed interface placement]
TP10: TestPoint:TestPoint_Pad_D1.0mm @ 60.00,34.00 mm (Test pads) [fixed interface placement]
TP11: TestPoint:TestPoint_Pad_D1.0mm @ 60.00,39.00 mm (Test pads) [fixed interface placement]
TP12: TestPoint:TestPoint_Pad_D1.0mm @ 60.00,44.00 mm (Test pads) [fixed interface placement]
TP13: TestPoint:TestPoint_Pad_D1.0mm @ 60.00,49.00 mm (Test pads) [fixed interface placement]
TP14: TestPoint:TestPoint_Pad_D1.0mm @ 35.00,70.00 mm (Test pads) [fixed interface placement]
J1: Connector_USB:USB_C_Receptacle_GCT_USB4125-xx-x_6P_TopMnt_Horizontal @ 73.00,52.00 mm (USB-C input) [fixed interface placement]
U1: Package_DFN_QFN:Texas_RGE0024H_VQFN-24-1EP_4x4mm_P0.5mm_EP2.7x2.7mm @ 30.00,34.00 mm (2S charger) [manual preferred placement]
L3: Inductor_SMD:L_APV_ANR5040 @ 18.00,34.00 mm (2S charger) [manual preferred placement]
C3: Capacitor_SMD:C_0805_2012Metric @ 37.00,30.00 mm (2S charger) [manual preferred placement]
C5: Capacitor_SMD:C_0805_2012Metric @ 37.00,35.00 mm (2S charger) [manual preferred placement]
C4: Capacitor_SMD:C_0603_1608Metric @ 43.00,30.00 mm (2S charger) [manual preferred placement]
C6: Capacitor_SMD:C_0603_1608Metric @ 43.00,35.00 mm (2S charger) [manual preferred placement]
C7: Capacitor_SMD:C_0603_1608Metric @ 24.00,42.00 mm (2S charger) [manual preferred placement]
C8: Capacitor_SMD:C_0603_1608Metric @ 30.00,42.00 mm (2S charger) [manual preferred placement]
C9: Capacitor_SMD:C_0603_1608Metric @ 37.00,42.00 mm (2S charger) [manual preferred placement]
C10: Capacitor_SMD:C_0603_1608Metric @ 43.00,42.00 mm (2S charger) [manual preferred placement]
D2: LED_SMD:LED_0603_1608Metric @ 54.00,31.00 mm (2S charger) [manual preferred placement]
D3: LED_SMD:LED_0603_1608Metric @ 54.00,37.00 mm (2S charger) [manual preferred placement]
R3: Resistor_SMD:R_0603_1608Metric @ 18.00,25.00 mm (2S charger) [manual preferred placement]
R4: Resistor_SMD:R_0603_1608Metric @ 24.00,25.00 mm (2S charger) [manual preferred placement]
R5: Resistor_SMD:R_0603_1608Metric @ 30.00,25.00 mm (2S charger) [manual preferred placement]
R6: Resistor_SMD:R_0603_1608Metric @ 48.00,31.00 mm (2S charger) [manual preferred placement]
R7: Resistor_SMD:R_0603_1608Metric @ 48.00,37.00 mm (2S charger) [manual preferred placement]
TH1: Resistor_SMD:R_0603_1608Metric @ 54.00,43.00 mm (2S charger) [manual preferred placement]
U2: Package_TO_SOT_SMD:SOT-23-6 @ 50.00,28.00 mm (2S protection) [manual preferred placement]
C25: Capacitor_SMD:C_0603_1608Metric @ 80.00,15.00 mm (2S protection) [manual preferred placement]
C26: Capacitor_SMD:C_0603_1608Metric @ 85.00,15.00 mm (2S protection) [manual preferred placement]
R14: Resistor_SMD:R_0603_1608Metric @ 90.00,15.00 mm (2S protection) [manual preferred placement]
R15: Resistor_SMD:R_0603_1608Metric @ 55.00,35.00 mm (2S protection) [manual preferred placement]
R16: Resistor_SMD:R_0603_1608Metric @ 45.00,40.00 mm (2S protection) [manual preferred placement]
R21: Resistor_SMD:R_0603_1608Metric @ 50.00,40.00 mm (2S protection) [manual preferred placement]
R22: Resistor_SMD:R_0603_1608Metric @ 55.00,40.00 mm (2S protection) [manual preferred placement]
Q1: Daughterboard:CSD83325L_YJE0006A @ 50.00,35.00 mm (2S protection) [manual preferred placement]
L2: Inductor_SMD:L_APV_ANR4020 @ 101.00,22.00 mm (3V3 buck) [manual preferred placement]
U4: Package_TO_SOT_SMD:TSOT-23-6 @ 86.00,22.00 mm (3V3 buck) [manual preferred placement]
C16: Capacitor_SMD:C_0805_2012Metric @ 80.00,17.00 mm (3V3 buck) [manual preferred placement]
C22: Capacitor_SMD:C_0805_2012Metric @ 90.00,17.00 mm (3V3 buck) [manual preferred placement]
C23: Capacitor_SMD:C_0805_2012Metric @ 95.00,17.00 mm (3V3 buck) [manual preferred placement]
C21: Capacitor_SMD:C_0603_1608Metric @ 85.00,17.00 mm (3V3 buck) [manual preferred placement]
C24: Capacitor_SMD:C_0603_1608Metric @ 100.00,17.00 mm (3V3 buck) [manual preferred placement]
R11: Resistor_SMD:R_0603_1608Metric @ 80.00,29.00 mm (3V3 buck) [manual preferred placement]
R12: Resistor_SMD:R_0603_1608Metric @ 85.00,29.00 mm (3V3 buck) [manual preferred placement]
R13: Resistor_SMD:R_0603_1608Metric @ 90.00,29.00 mm (3V3 buck) [manual preferred placement]
L1: Inductor_SMD:L_APV_ANR4020 @ 16.00,58.00 mm (5V buck) [manual preferred placement]
U3: Package_TO_SOT_SMD:TSOT-23-6 @ 25.00,58.00 mm (5V buck) [manual preferred placement]
C11: Capacitor_SMD:C_0805_2012Metric @ 16.00,64.00 mm (5V buck) [manual preferred placement]
C13: Capacitor_SMD:C_0805_2012Metric @ 28.00,64.00 mm (5V buck) [manual preferred placement]
C14: Capacitor_SMD:C_0805_2012Metric @ 34.00,64.00 mm (5V buck) [manual preferred placement]
C12: Capacitor_SMD:C_0603_1608Metric @ 22.00,64.00 mm (5V buck) [manual preferred placement]
C15: Capacitor_SMD:C_0603_1608Metric @ 36.00,62.00 mm (5V buck) [manual preferred placement]
R8: Resistor_SMD:R_0603_1608Metric @ 16.00,70.00 mm (5V buck) [manual preferred placement]
R9: Resistor_SMD:R_0603_1608Metric @ 22.00,70.00 mm (5V buck) [manual preferred placement]
R10: Resistor_SMD:R_0603_1608Metric @ 28.00,70.00 mm (5V buck) [manual preferred placement]
C17: Capacitor_SMD:C_0603_1608Metric @ 139.50,49.00 mm (Analog inputs) [manual preferred placement]
C18: Capacitor_SMD:C_0603_1608Metric @ 144.50,49.00 mm (Analog inputs) [manual preferred placement]
C19: Capacitor_SMD:C_0603_1608Metric @ 149.50,49.00 mm (Analog inputs) [manual preferred placement]
C20: Capacitor_SMD:C_0603_1608Metric @ 154.50,49.00 mm (Analog inputs) [manual preferred placement]
R19: Resistor_SMD:R_0603_1608Metric @ 150.00,54.00 mm (Analog inputs) [manual preferred placement]
R20: Resistor_SMD:R_0603_1608Metric @ 155.00,54.00 mm (Analog inputs) [manual preferred placement]
J7: Connector_JST:JST_XH_B3B-XH-A_1x03_P2.50mm_Vertical @ 39.00,51.00 mm (Battery) [manual preferred placement]
F2: Fuse:Fuse_1206_3216Metric @ 15.00,45.00 mm (Battery) [manual preferred placement]
F3: Fuse:Fuse_1206_3216Metric @ 22.00,45.00 mm (Battery) [manual preferred placement]
F4: Fuse:Fuse_1206_3216Metric @ 29.00,45.00 mm (Battery) [manual preferred placement]
D4: Package_TO_SOT_SMD:SOT-23-6 @ 129.47,54.61 mm (GPIO expander) [manual preferred placement]
D5: Package_TO_SOT_SMD:SOT-23-6 @ 125.00,35.00 mm (GPIO expander) [manual preferred placement]
D6: Package_TO_SOT_SMD:SOT-23-6 @ 130.00,35.00 mm (GPIO expander) [manual preferred placement]
D7: Package_TO_SOT_SMD:SOT-23-6 @ 134.47,54.61 mm (GPIO expander) [manual preferred placement]
C27: Capacitor_SMD:C_0603_1608Metric @ 106.97,54.61 mm (GPIO expander) [manual preferred placement]
C28: Capacitor_SMD:C_0603_1608Metric @ 143.00,54.00 mm (GPIO expander) [manual preferred placement]
C29: Capacitor_SMD:C_0603_1608Metric @ 138.00,59.00 mm (GPIO expander) [manual preferred placement]
R23: Resistor_SMD:R_0603_1608Metric @ 135.00,30.00 mm (GPIO expander) [manual preferred placement]
R24: Resistor_SMD:R_0603_1608Metric @ 140.00,30.00 mm (GPIO expander) [manual preferred placement]
R25: Resistor_SMD:R_0603_1608Metric @ 145.00,30.00 mm (GPIO expander) [manual preferred placement]
R26: Resistor_SMD:R_0603_1608Metric @ 150.00,30.00 mm (GPIO expander) [manual preferred placement]
R27: Resistor_SMD:R_0603_1608Metric @ 155.00,30.00 mm (GPIO expander) [manual preferred placement]
R28: Resistor_SMD:R_0603_1608Metric @ 135.00,35.00 mm (GPIO expander) [manual preferred placement]
R29: Resistor_SMD:R_0603_1608Metric @ 140.00,35.00 mm (GPIO expander) [manual preferred placement]
R30: Resistor_SMD:R_0603_1608Metric @ 145.00,35.00 mm (GPIO expander) [manual preferred placement]
R31: Resistor_SMD:R_0603_1608Metric @ 150.00,35.00 mm (GPIO expander) [manual preferred placement]
R32: Resistor_SMD:R_0603_1608Metric @ 155.00,35.00 mm (GPIO expander) [manual preferred placement]
R33: Resistor_SMD:R_0603_1608Metric @ 135.00,40.00 mm (GPIO expander) [manual preferred placement]
R34: Resistor_SMD:R_0603_1608Metric @ 140.00,40.00 mm (GPIO expander) [manual preferred placement]
R35: Resistor_SMD:R_0603_1608Metric @ 145.00,40.00 mm (GPIO expander) [manual preferred placement]
R36: Resistor_SMD:R_0603_1608Metric @ 150.00,40.00 mm (GPIO expander) [manual preferred placement]
R37: Resistor_SMD:R_0603_1608Metric @ 155.00,40.00 mm (GPIO expander) [manual preferred placement]
R38: Resistor_SMD:R_0603_1608Metric @ 160.00,40.00 mm (GPIO expander) [manual preferred placement]
R39: Resistor_SMD:R_0603_1608Metric @ 143.00,59.00 mm (GPIO expander) [manual preferred placement]
R40: Resistor_SMD:R_0603_1608Metric @ 138.00,64.00 mm (GPIO expander) [manual preferred placement]
R41: Resistor_SMD:R_0603_1608Metric @ 143.00,64.00 mm (GPIO expander) [manual preferred placement]
R42: Resistor_SMD:R_0603_1608Metric @ 143.00,69.00 mm (GPIO expander) [manual preferred placement]
R43: Resistor_SMD:R_0603_1608Metric @ 111.97,54.61 mm (GPIO expander) [manual preferred placement]
R44: Resistor_SMD:R_0603_1608Metric @ 116.97,54.61 mm (GPIO expander) [manual preferred placement]
J91: TestPoint:TestPoint_Pad_1.5x1.5mm @ 120.00,45.00 mm (GPIO expander) [manual preferred placement]
J92: TestPoint:TestPoint_Pad_1.5x1.5mm @ 125.00,45.00 mm (GPIO expander) [manual preferred placement]
J93: TestPoint:TestPoint_Pad_1.5x1.5mm @ 122.50,42.50 mm (GPIO expander) [manual preferred placement]
J94: TestPoint:TestPoint_Pad_1.5x1.5mm @ 135.00,45.00 mm (GPIO expander) [manual preferred placement]
J95: TestPoint:TestPoint_Pad_1.5x1.5mm @ 140.00,45.00 mm (GPIO expander) [manual preferred placement]
J96: TestPoint:TestPoint_Pad_1.5x1.5mm @ 145.00,45.00 mm (GPIO expander) [manual preferred placement]
J97: TestPoint:TestPoint_Pad_1.5x1.5mm @ 150.00,45.00 mm (GPIO expander) [manual preferred placement]
J98: TestPoint:TestPoint_Pad_1.5x1.5mm @ 155.00,45.00 mm (GPIO expander) [manual preferred placement]
J99: TestPoint:TestPoint_Pad_1.5x1.5mm @ 120.00,50.00 mm (GPIO expander) [manual preferred placement]
J910: TestPoint:TestPoint_Pad_1.5x1.5mm @ 121.97,54.61 mm (GPIO expander) [manual preferred placement]
J911: TestPoint:TestPoint_Pad_1.5x1.5mm @ 124.47,54.61 mm (GPIO expander) [manual preferred placement]
J912: TestPoint:TestPoint_Pad_1.5x1.5mm @ 139.47,54.61 mm (GPIO expander) [manual preferred placement]
J913: TestPoint:TestPoint_Pad_1.5x1.5mm @ 146.97,54.61 mm (GPIO expander) [manual preferred placement]
J914: TestPoint:TestPoint_Pad_1.5x1.5mm @ 145.72,57.11 mm (GPIO expander) [manual preferred placement]
J915: TestPoint:TestPoint_Pad_1.5x1.5mm @ 148.22,57.11 mm (GPIO expander) [manual preferred placement]
J916: TestPoint:TestPoint_Pad_1.5x1.5mm @ 131.97,59.61 mm (GPIO expander) [manual preferred placement]
J925: TestPoint:TestPoint_Pad_1.5x1.5mm @ 134.47,59.61 mm (GPIO expander) [manual preferred placement]
J926: TestPoint:TestPoint_Pad_1.5x1.5mm @ 146.97,59.61 mm (GPIO expander) [manual preferred placement]
J927: TestPoint:TestPoint_Pad_1.5x1.5mm @ 145.72,62.11 mm (GPIO expander) [manual preferred placement]
J928: TestPoint:TestPoint_Pad_1.5x1.5mm @ 148.22,62.11 mm (GPIO expander) [manual preferred placement]
J929: TestPoint:TestPoint_Pad_1.5x1.5mm @ 146.97,64.61 mm (GPIO expander) [manual preferred placement]
R17: Resistor_SMD:R_0603_1608Metric @ 50.00,52.00 mm (Output switching) [manual preferred placement]
R18: Resistor_SMD:R_0603_1608Metric @ 55.00,52.00 mm (Output switching) [manual preferred placement]
F1: Fuse:Fuse_1206_3216Metric @ 26.00,18.00 mm (USB-C input) [manual preferred placement]
C1: Capacitor_SMD:C_0805_2012Metric @ 37.00,18.00 mm (USB-C input) [manual preferred placement]
D1: Diode_SMD:D_SOD-323 @ 31.00,18.00 mm (USB-C input) [manual preferred placement]
C2: Capacitor_SMD:C_0603_1608Metric @ 42.00,18.00 mm (USB-C input) [manual preferred placement]
R1: Resistor_SMD:R_0603_1608Metric @ 26.00,13.00 mm (USB-C input) [manual preferred placement]
R2: Resistor_SMD:R_0603_1608Metric @ 31.00,13.00 mm (USB-C input) [manual preferred placement]

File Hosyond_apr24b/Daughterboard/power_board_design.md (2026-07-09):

# USB-C 2S LiPo / 2x18650 Power Board Design

## Goal

Small KiCad board that accepts 5 V from USB-C, charges a 2S Li-ion/LiPo pack, and generates switched 5 V and 3.3 V rails for external devices controlled by the Hosyond ESP32-S3 display board.

The battery source is now selectable by population/use:

- External 2S LiPo pack through `J7`, a 3-pin JST-XH style balance connector: `B-`, `CELL_MID`, `B+`.
- Two installed 18650 cells in series through `BT1` and `BT2`.

Use either the external 2S pack on `J7` or installed 18650 cells, not both at the same time.

## Architecture

```mermaid
flowchart LR
    USBC["USB-C receptacle\n5 V sink"] --> INPROT["VBUS fuse, TVS,\nCC1/CC2 Rd"]
    INPROT --> CHG["BQ25887RGE\n2S boost charger"]
    CHG <--> PROT["S-8252AAH + CSD83325L\n2S protection"]
    PROT <--> PACK["2S pack nets\nBATT_RAW_N / CELL_MID / PACK_P"]
    CELLS["2x 18650 in series"] <--> PACK
    BAL["J7 2S balance lead"] <--> PACK
    PROT --> FUSE["F4 system fuse\nBAT_SYS"]
    FUSE --> BUCK5["AP63200WU\n5 V buck"]
    FUSE --> BUCK3["AP63200WU\n3.3 V buck"]
    BUCK5 --> SW5["Pololu #2808\n5 V switch"]
    BUCK3 --> SW3["Pololu #2808\n3.3 V switch"]
    ESP["Hosyond ESP32-S3\nGPIO2/GPIO3"] --> SW5
    ESP --> SW3
    SW5 --> R5["+5V_SW"]
    SW3 --> R3["+3V3_SW"]
    R3 --> GPIOX["MCP23017\n16 GPIO solder pads"]
```

## Main Components

| Function | Rev-A part | Notes |
|---|---|---|
| USB-C 5 V sink | USB-C receptacle plus 5.1 kOhm CC pulldowns | Power-only Type-C input, no USB-PD. |
| 2S charger | TI `BQ25887RGE` | 5 V boost-mode charger for 2-cell Li-ion/LiPo packs with midpoint/balance connection. |
| 2S protection | ABLIC `S-8252AAH-M6T1U` + TI `CSD83325L` | Standalone 2S OV/UV/overcurrent/short protection using back-to-back low-side FETs. |
| 5 V regulator | Diodes Inc. `AP63200WU` | 2S-to-5 V buck, target load 1 A max. |
| 3.3 V regulator | Diodes Inc. `AP63200WU` | 2S-to-3.3 V buck, target load 500 mA max. |
| Rail switches | Pololu #2808 modules | Switches are after the regulators; ESP32 GPIO2 controls 5 V, GPIO3 controls 3.3 V. |
| Analog inputs | 2x TI `ADS1115IDGS` | Powered from `+3V3_SW`, so ADCs and connected 3.3 V sensors shut down with the switched rail. |
| GPIO expander | Microchip `MCP23017-E/SO` | 16-bit I2C GPIO expander powered from `+3V3_SW`; default address `0x20`. |

## Battery Nets

- `BATT_RAW_N`: raw 2S pack negative / lower cell negative.
- `GND`: protected board/load/charger negative after the low-side protection FETs.
- `CELL_MID`: lower cell positive and upper cell negative.
- `PACK_P`: upper cell positive / 2S pack positive.
- `BAT_SYS`: fused 2S system bus feeding both buck regulators.

The two 18650 holders are now series-connected:

- `BT1`: lower cell, negative to `BATT_RAW_N`, positive through `F2` to `CELL_MID`.
- `BT2`: upper cell, negative to `CELL_MID`, positive through `F3` to `PACK_P`.
- `J7`: external 2S balance input, pin 1 `BATT_RAW_N`, pin 2 `CELL_MID`, pin 3 `PACK_P`.

## 2S Protection

The old single-cell `BQ297xy` protection IC is not valid for a 2S pack. The active schematic now uses an ABLIC `S-8252AAH-M6T1U` 2S protection IC and the existing TI `CSD83325L` dual common-drain N-FET as the low-side back-to-back protection switch.

The selected `S-8252AAH-M6T1U` variant has these rev-A thresholds from the ABLIC datasheet selection table:

- Overcharge detection: 4.250 V per cell.
- Overcharge release: 4.100 V per cell.
- Overdischarge detection/release: 3.000 V per cell.
- Discharge overcurrent detection: 0.200 V at `VM`.
- Load short-circuit detection: 0.500 V at `VM`.
- Charge overcurrent detection: -0.200 V at `VM`.
- 0 V battery charge: enabled.

Rev-A support parts follow the datasheet connection example:

- `R14`, `R15`: 470 ohm sense/filter resistors on `VDD` and `VC`.
- `C25`, `C26`: 100 nF cell sense capacitors.
- `R16`: 2.0 kOhm from `VM_SENSE` to protected `GND`.
- `Q1`: CSD83325L back-to-back low-side FET pair between `BATT_RAW_N` and protected `GND`.

The CSD83325L is retained from the previous design, but its 12 V rating should be reviewed during PCB release because a full 2S pack is 8.4 V and real products see transients. A 20 V or 30 V FET pair would give more margin if board area allows.

The protector does not set the normal charge current. The BQ25887 charger should be configured so USB-C charging is firmware-limited from 500 mA minimum up to 1.5 A maximum, with the hardware input-current limit also held at or below 1.5 A.

## Regulator Population

The 1S boost/buck-boost regulators were replaced because a 2S pack ranges roughly from discharged to 8.4 V full charge.

- `U3`: `AP63200WU` configured for 5 V with `R8 = 523 kOhm` and `R9 = 100 kOhm`.
- `U4`: `AP63200WU` configured for 3.3 V with `R11 = 316 kOhm` and `R12 = 100 kOhm`.
- `L1` and `L2`: 4.7 uH shielded inductors.
- Input capacitors on `BAT_SYS` are rated 16 V.
- Output capacitors are rated at least 10 V.

## Switched Outputs And Signals

- `SW1` Pololu #2808: `+5V` in, `+5V_SW` out, control through `CTRL_5V_SW` from ESP32 `GPIO2`.
- `SW2` Pololu #2808: `+3V3` in, `+3V3_SW` out, control through `CTRL_3V3_SW` from ESP32 `GPIO3`.
- `J4`: 5-pin 1.25 mm JST UART header with `+5V_SW`, GND, TX, RX, GND.
- `J5`: 4-pin 2.54 mm I2C header with `+3V3_SW`, GND, SDA, SCL.
- `J6`: 2-pin deep-sleep pushbutton header between `GPIO14` and `GPIO21`.
- `J3x`: individual solder pads for the Hosyond board wires.

## MCP23017 GPIO Expander

The daughterboard now includes `U7`, a Microchip `MCP23017-E/SO` 16-bit I2C GPIO expander in SOIC-28W.

- `VDD`: `+3V3_SW`, so the expander shuts down with the switched 3.3 V rail.
- `VSS`: protected `GND`.
- `SDA` / `SCL`: shared `I2C_SDA` / `I2C_SCL` bus with the ADS1115s.
- Address pins `A0`, `A1`, and `A2`: default 0 ohm straps to GND, giving address `0x20`.
- `RESET`: 10 kOhm pullup to `+3V3_SW` and 100 nF reset capacitor to GND.
- `INTA` / `INTB`: 10 kOhm pullups to `+3V3_SW` and individual solder pads.
- GPIO outputs: `GPA0..GPA7` and `GPB0..GPB7` each pass through a 100 ohm series resistor to an individual solder pad.
- ESD placeholders: four 4-channel 3.3 V TVS/ESD arrays protect the external pad side of the 16 GPIO lines.
- `GPA7` and `GPB7`: treat as output-only unless the exact MCP23017 variant/revision is verified for input use.

Because the MCP23017 is powered from `+3V3_SW`, firmware should enable the 3.3 V switched rail before using the I2C bus for the expander. The ADS1115 pullups are also on `+3V3_SW`, so the switched 3.3 V rail is the intended I2C pullup source for the daughterboard devices.

## Generated Files

- `Daughterboard.kicad_sch`: generated pin-level schematic.
- `Daughterboard.kicad_sym`: project-local symbols.
- `Daughterboard_pinlevel_bom.csv`: generated BOM with purchase-link column.
- `Daughterboard_pcb_bom.csv`, `pcb_component_schedule.csv`, `starter_bom_and_nets.csv`, and `starter_bom_and_nets_with_links.csv`: synced BOM copies.
- `Daughterboard_pinlevel.pdf` and `Daughterboard_pinlevel_preview.png`: exported schematic preview.
- `Daughterboard_pinlevel_erc.rpt`: KiCad ERC report.

## Footprint Policy

The design is space-constrained, so rev-A uses SMD footprints for nearly all normal components:

- Fuses/PTCs: 1206 SMD fuse footprints.
- NTC: 0603 SMD thermistor footprint.
- Buck/charger inductors: compact shielded SMD inductor footprints.
- Resistors/capacitors: 0603/0805 SMD as listed in the BOM.
- Hosyond and MCP23017 wire breakouts: flat 1.5 mm SMD test pads.
- ICs, ESD arrays, FETs, charger, regulators, ADCs, and MCP23017: SMD packages.

The intentional exceptions are mechanical/interface parts: USB-C, 18650 holders, Pololu switch modules, JST connectors, and 2.54 mm pin headers. Those connector styles were left unchanged.

## Sources

- TI BQ25887 product/datasheet: https://www.ti.com/product/BQ25887
- ABLIC S-8252 Series datasheet: https://www.ablic.com/en/doc/datasheet/battery_protection/S8252_E.pdf
- TI CSD83325L product/datasheet: https://www.ti.com/product/CSD83325L
- Diodes Inc. AP63200/AP63201/AP63203/AP63205 datasheet: https://www.diodes.com/assets/Datasheets/AP63200-AP63201-AP63203-AP63205.pdf
- Microchip MCP23017 datasheet: https://ww1.microchip.com/downloads/aemDocuments/documents/APID/ProductDocuments/DataSheets/MCP23017-Data-Sheet-DS20001952.pdf
- Pololu #2808 Mini Pushbutton Power Switch LV: https://www.pololu.com/product/2808

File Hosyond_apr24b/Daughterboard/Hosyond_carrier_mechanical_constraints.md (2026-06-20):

# Hosyond Carrier Board Mechanical Constraints

## Board Shape

User-provided available space:

- Top left horizontal: `56 mm`
- Center notch/drop: `22 mm` down
- Center horizontal: `51 mm`
- Center rise: `22 mm` up
- Top right horizontal: `56 mm`
- Side height: `42 mm`
- Bottom width: `163 mm`

Interpreted as a wide shallow `U` / top-notched board:

```text
Total width:  163 mm
Total height: 42 mm
Top notch:    51 mm wide x 22 mm deep
```

## STEP Reference

Reference file:

```text
C:\Users\Avala\Downloads\daughteroard.step
```

Quick geometry scan from the STEP file:

```text
X min/max: -81.500 mm to 81.500 mm
Width:     163.000 mm

Y min/max: -51.738 mm to 0.000 mm
Height:    51.738 mm

Z min/max: -13.650 mm to 0.000 mm
Depth:     13.650 mm
```

Important: the STEP-derived width matches the hand measurement exactly, but
the STEP-derived height is about `51.74 mm`, not `42 mm`. Before ordering a PCB,
use the STEP model or a printed 1:1 outline to confirm whether the real usable
board height should be `42 mm` or `51.74 mm`.

## DXF Board Outline

Reference file:

```text
C:\Users\Avala\Downloads\daughterboard.dxf
```

The DXF declares `$INSUNITS = 4`, which means millimeters. Its 2D extents are:

```text
Width:  163.000 mm
Height: 42.000 mm
Layer:  0
```

The DXF contains one closed `LWPOLYLINE`, which is the likely KiCad
`Edge.Cuts` board outline. Original DXF coordinates:

```text
(-81.500, 12.738)
(-78.500,  9.738)
(-28.500,  9.738)
(-25.500, 12.738)
(-25.500, 28.738)
(-22.500, 31.738)
( 22.500, 31.738)
( 25.500, 28.738)
( 25.500, 12.738)
( 28.500,  9.738)
( 78.500,  9.738)
( 81.500, 12.738)
( 81.500, 48.738)
( 78.500, 51.738)
(-78.500, 51.738)
(-81.500, 48.738)
closed
```

Normalized to a top-left-ish `(0,0)` coordinate system by adding `81.5` to X
and subtracting `9.73761672784435` from Y:

```text
(  0.000,  3.000)
(  3.000,  0.000)
( 53.000,  0.000)
( 56.000,  3.000)
( 56.000, 19.000)
( 59.000, 22.000)
(104.000, 22.000)
(107.000, 19.000)
(107.000,  3.000)
(110.000,  0.000)
(160.000,  0.000)
(163.000,  3.000)
(163.000, 39.000)
(160.000, 42.000)
(  3.000, 42.000)
(  0.000, 39.000)
closed
```

This outline includes `3 mm` chamfers/reliefs at the outer corners and notch
corners, so it is more accurate than the earlier simplified rectangle/notch.

## Coordinate System

Origin is the top-left outer corner of the PCB.

```text
X increases left -> right
Y increases top -> bottom
```

## Edge.Cuts Polygon

Use this simplified point list only for rough planning:

```text
P1  (0,   0)
P2  (56,  0)
P3  (56,  22)
P4  (107, 22)
P5  (107, 0)
P6  (163, 0)
P7  (163, 42)
P8  (0,   42)
P9  (0,   0)
```

Visual sketch:

```text
(0,0)          (56,0)         (107,0)          (163,0)
  +--------------+               +---------------+
  |              |               |               |
  |              +---------------+               |
  |              (56,22)   (107,22)              |
  |                                              |
  |                                              |
  +----------------------------------------------+
(0,42)                                      (163,42)
```

## Placement Priorities

Fixed / case-facing items should be placed first:

- USB-C breakout aligned with the case opening.
- Power button connector near the physical power button.
- Gimbal connectors near left and right gimbal wire exits.
- Hosyond UART/I2C/GPIO connectors near the Hosyond board.
- ELRS header and 5V switch near the ELRS module bay.
- D-pad connector near the front controls.
- Battery connector near the battery pocket.

## Routing Priorities

- Route power first: `GND`, `5V`, `3V3`, `5V_SW`, `3V3_SW`.
- Keep all grounds common.
- Use wider traces for `5V`, `3V3`, switched rails, and battery-related nets.
- Keep analog gimbal traces away from ELRS/UART if practical.
- Keep `D+` and `D-` close together if USB data is routed on this carrier.
- Add test pads for `5V`, `3V3`, `GND`, `SDA`, `SCL`, `UART_TX`, and `UART_RX`.

## Open Mechanical Questions

- Exact USB-C port location.
- Mounting hole count and positions.
- Which side/components face up.
- Maximum component height.
- Whether modules mount directly to the carrier or connect by short jumpers.

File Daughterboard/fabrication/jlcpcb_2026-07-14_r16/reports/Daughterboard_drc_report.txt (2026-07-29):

** Drc report for Daughterboard.kicad_pcb **
** Created on 2026-07-14T20:39:43 **
** Report includes: Errors, Warnings **

** Found 38 DRC violations **
[text_height]: Text height out of range (board setup constraints silk text height min height 0.8000 mm; actual 0.7000 mm)
    Rule: board setup constraints silk text height; warning
    @(17.3000 mm, 32.9550 mm): Reference field of Q2
[text_height]: Text height out of range (board setup constraints silk text height min height 0.8000 mm; actual 0.7000 mm)
    Rule: board setup constraints silk text height; warning
    @(41.3000 mm, 13.6500 mm): Footprint text of SW1 (VIN)
[text_height]: Text height out of range (board setup constraints silk text height min height 0.8000 mm; actual 0.6500 mm)
    Rule: board setup constraints silk text height; warning
    @(41.6000 mm, 18.7300 mm): Footprint text of SW1 (GND)
[text_height]: Text height out of range (board setup constraints silk text height min height 0.8000 mm; actual 0.6500 mm)
    Rule: board setup constraints silk text height; warning
    @(42.0000 mm, 27.6200 mm): Footprint text of SW1 (CTRL)
[text_height]: Text height out of range (board setup constraints silk text height min height 0.8000 mm; actual 0.6500 mm)
    Rule: board setup constraints silk text height; warning
    @(49.8000 mm, 13.6500 mm): Footprint text of SW1 (VOUT)
[text_height]: Text height out of range (board setup constraints silk text height min height 0.8000 mm; actual 0.6500 mm)
    Rule: board setup constraints silk text height; warning
    @(50.4000 mm, 18.7300 mm): Footprint text of SW1 (GND)
[text_height]: Text height out of range (board setup constraints silk text height min height 0.8000 mm; actual 0.7000 mm)
    Rule: board setup constraints silk text height; warning
    @(84.5500 mm, 33.0700 mm): Footprint text of SW2 (VIN)
[text_height]: Text height out of range (board setup constraints silk text height min height 0.8000 mm; actual 0.6500 mm)
    Rule: board setup constraints silk text height; warning
    @(84.8500 mm, 38.1500 mm): Footprint text of SW2 (GND)
[text_height]: Text height out of range (board setup constraints silk text height min height 0.8000 mm; actual 0.6500 mm)
    Rule: board setup constraints silk text height; warning
    @(85.2500 mm, 47.0400 mm): Footprint text of SW2 (CTRL)
[text_height]: Text height out of range (board setup constraints silk text height min height 0.8000 mm; actual 0.6500 mm)
    Rule: board setup constraints silk text height; warning
    @(93.0500 mm, 33.0700 mm): Footprint text of SW2 (VOUT)
[text_height]: Text height out of range (board setup constraints silk text height min height 0.8000 mm; actual 0.6500 mm)
    Rule: board setup constraints silk text height; warning
    @(93.6500 mm, 38.1500 mm): Footprint text of SW2 (GND)
[text_height]: Text height out of range (board setup constraints silk text height min height 0.8000 mm; actual 0.7000 mm)
    Rule: board setup constraints silk text height; warning
    @(66.7125 mm, 31.1500 mm): Reference field of U2
[text_height]: Text height out of range (board setup constraints silk text height min height 0.8000 mm; actual 0.7000 mm)
    Rule: board setup constraints silk text height; warning
    @(32.7000 mm, 45.0550 mm): Reference field of Q1
[silk_overlap]: Silkscreen clearance
    Rule: board setup constraints silk; warning
    @(132.8000 mm, 12.7520 mm): Reference field of J910
    @(129.4000 mm, 12.7520 mm): Reference field of J911
[silk_overlap]: Silkscreen clearance
    Rule: board setup constraints silk; warning
    @(26.6700 mm, 48.6250 mm): Reference field of R50
    @(26.0250 mm, 50.4700 mm): Reference field of C15
[silk_overlap]: Silkscreen clearance
    Rule: board setup constraints silk; warning
    @(145.6775 mm, 26.1877 mm): Segment of R34 on F.Silkscreen
    @(145.2000 mm, 26.4250 mm): Reference field of R34
[silk_overlap]: Silkscreen clearance
    Rule: board setup constraints silk; warning
    @(142.8000 mm, 26.4250 mm): Reference field of R36
    @(143.2775 mm, 26.1877 mm): Segment of R36 on F.Silkscreen
[silk_overlap]: Silkscreen clearance
    Rule: board setup constraints silk; warning
    @(148.0775 mm, 26.1877 mm): Segment of R33 on F.Silkscreen
    @(147.6000 mm, 26.4250 mm): Reference field of R33
[silk_overlap]: Silkscreen clearance
    Rule: board setup constraints silk; warning
    @(140.6775 mm, 26.1877 mm): Segment of R38 on F.Silkscreen
    @(140.2000 mm, 26.4250 mm): Reference field of R38
[silk_overlap]: Silkscreen clearance
    Rule: board setup constraints silk; warning
    @(135.8775 mm, 26.1877 mm): Segment of R35 on F.Silkscreen
    @(135.4000 mm, 26.4250 mm): Reference field of R35
[silk_overlap]: Silkscreen clearance
    Rule: board setup constraints silk; warning
    @(138.2775 mm, 26.1377 mm): Segment of R37 on F.Silkscreen
    @(137.8000 mm, 26.3750 mm): Reference field of R37
[silk_over_copper]: Silkscreen clipped by solder mask
    Local override; warning
    @(84.5500 mm, 33.0700 mm): Footprint text of SW2 (VIN)
    @(82.9000 mm, 31.8000 mm): PTH pad 1 [+3V3] of SW2
[silk_over_copper]: Silkscreen clipped by solder mask
    Local override; warning
    @(41.3000 mm, 13.6500 mm): Footprint text of SW1 (VIN)
    @(39.6500 mm, 12.3800 mm): PTH pad 1 [+5V] of SW1
[silk_over_copper]: Silkscreen clipped by solder mask
    Local override; warning
    @(145.2000 mm, 26.4250 mm): Reference field of R34
    @(146.2000 mm, 27.2500 mm): Pad 2 [EXP_GPB3] of R34 on F.Cu
[silk_over_copper]: Silkscreen clipped by solder mask
    Local override; warning
    @(142.8000 mm, 26.4250 mm): Reference field of R36
    @(143.8000 mm, 25.6000 mm): Pad 1 [MCP_GPB5] of R36 on F.Cu
[silk_over_copper]: Silkscreen clipped by solder mask
    Local override; warning
    @(142.8000 mm, 26.4250 mm): Reference field of R36
    @(143.8000 mm, 27.2500 mm): Pad 2 [EXP_GPB5] of R36 on F.Cu
[silk_over_copper]: Silkscreen clipped by solder mask
    Local override; warning
    @(147.6000 mm, 26.4250 mm): Reference field of R33
    @(148.6000 mm, 27.2500 mm): Pad 2 [EXP_GPB2] of R33 on F.Cu
[silk_over_copper]: Silkscreen clipped by solder mask
    Local override; warning
    @(147.6000 mm, 26.4250 mm): Reference field of R33
    @(148.6000 mm, 25.6000 mm): Pad 1 [MCP_GPB2] of R33 on F.Cu
[silk_over_copper]: Silkscreen clipped by solder mask
    Local override; warning
    @(140.2000 mm, 26.4250 mm): Reference field of R38
    @(141.2000 mm, 27.2500 mm): Pad 2 [EXP_GPB7] of R38 on F.Cu
[silk_over_copper]: Silkscreen clipped by solder mask
    Local override; warning
    @(140.2000 mm, 26.4250 mm): Reference field of R38
    @(141.2000 mm, 25.6000 mm): Pad 1 [MCP_GPB7] of R38 on F.Cu
[silk_over_copper]: Silkscreen clipped by solder mask
    Local override; warning
    @(135.4000 mm, 26.4250 mm): Reference field of R35
    @(136.4000 mm, 25.6000 mm): Pad 1 [MCP_GPB4] of R35 on F.Cu
[silk_over_copper]: Silkscreen clipped by solder mask
    Local override; warning
    @(135.4000 mm, 26.4250 mm): Reference field of R35
    @(136.4000 mm, 27.2500 mm): Pad 2 [EXP_GPB4] of R35 on F.Cu
[silk_over_copper]: Silkscreen clipped by solder mask
    Local override; warning
    @(137.8000 mm, 26.3750 mm): Reference field of R37
    @(138.8000 mm, 27.2000 mm): Pad 2 [EXP_GPB6] of R37 on F.Cu
[silk_over_copper]: Silkscreen clipped by solder mask
    Local override; warning
    @(137.8000 mm, 26.3750 mm): Reference field of R37
    @(138.8000 mm, 25.5500 mm): Pad 1 [MCP_GPB6] of R37 on F.Cu
[silk_over_copper]: Silkscreen clipped by solder mask
    Local override; warning
    @(66.0425 mm, 29.0500 mm): Segment of U2 on F.Silkscreen
    @(65.7500 mm, 32.2500 mm): Pad 13 [BATT_RAW_N] of U2 on F.Cu
[silk_over_copper]: Silkscreen clipped by solder mask
    Local override; warning
    @(66.0425 mm, 29.0500 mm): Segment of U2 on F.Silkscreen
    @(65.7500 mm, 30.0500 mm): Pad 13 [BATT_RAW_N] of U2 on F.Cu
[silk_over_copper]: Silkscreen clipped by solder mask
    Local override; warning
    @(63.2825 mm, 33.2500 mm): Segment of U2 on F.Silkscreen
    @(63.5750 mm, 32.2500 mm): Pad 13 [BATT_RAW_N] of U2 on F.Cu
[silk_over_copper]: Silkscreen clipped by solder mask
    Local override; warning
    @(63.2825 mm, 33.2500 mm): Segment of U2 on F.Silkscreen
    @(63.5750 mm, 30.0500 mm): Pad 13 [BATT_RAW_N] of U2 on F.Cu

** Found 0 unconnected pads **

** Found 0 Footprint errors **

** Ignored checks **
    - Footprint has no courtyard defined
    - Track endpoint not centered on via
    - Tuning profile track geometries
    - Footprint doesn't match symbol's footprint filters
    - Footprint component type doesn't match footprint pads

** End of Report **

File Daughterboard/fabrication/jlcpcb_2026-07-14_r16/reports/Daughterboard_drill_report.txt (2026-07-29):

Drill report for Daughterboard.kicad_pcb
Created on 2026-07-14T20:39:37

Copper Layer Stackup:
    =============================================================
    L1 :  F.Cu                      front
    L2 :  In1.Cu                    in1
    L3 :  In2.Cu                    in2
    L4 :  B.Cu                      back

Drill file 'Daughterboard-PTH.drl' contains
    plated through holes:
    =============================================================
    T1  0.300mm  0.0118"  (174 holes))
    T2  0.350mm  0.0138"  (3 holes))
    T3  0.400mm  0.0157"  (6 holes))
    T4  0.500mm  0.0197"  (17 holes))
    T5  0.600mm  0.0236"  (4 holes)  (with 4 slots)
    T6  0.950mm  0.0374"  (3 holes))
    T7  1.000mm  0.0394"  (6 holes))
    T8  1.020mm  0.0402"  (18 holes))

    Total plated holes count 231

Drill file 'Daughterboard-NPTH.drl' contains
    unplated through holes:
    =============================================================

    Total unplated holes count 0

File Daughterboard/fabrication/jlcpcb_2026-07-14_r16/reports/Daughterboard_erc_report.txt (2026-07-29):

ERC report (2026-07-14T20:39:49, Encoding UTF8)
Report includes: Errors, Warnings

***** Sheet /

 ** ERC messages: 0  Errors 0  Warnings 0

 ** Ignored checks:
    - Global label only appears once in the schematic
    - Four connection points are joined together
    - SPICE model issue
    - Assigned footprint doesn't match footprint filters

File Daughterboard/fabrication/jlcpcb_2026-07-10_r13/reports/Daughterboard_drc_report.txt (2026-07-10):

** Drc report for Daughterboard.kicad_pcb **
** Created on 2026-07-09T23:27:31 **
** Report includes: Errors, Warnings **

** Found 38 DRC violations **
[clearance]: Clearance violation ( clearance 0.2500 mm; actual 0.2000 mm)
    Local override; error
    @(31.9625 mm, 35.2500 mm): Pad 13 [BAT_SYS] of U1 on F.Cu
    @(30.0000 mm, 34.0000 mm): Pad 25 [GND] of U1 on F.Cu
[clearance]: Clearance violation ( clearance 0.2500 mm; actual 0.2000 mm)
    Local override; error
    @(31.9625 mm, 34.7500 mm): Pad 14 [BAT_SYS] of U1 on F.Cu
    @(30.0000 mm, 34.0000 mm): Pad 25 [GND] of U1 on F.Cu
[clearance]: Clearance violation ( clearance 0.2500 mm; actual 0.2000 mm)
    Local override; error
    @(31.9625 mm, 34.2500 mm): Pad 15 [BAT_SYS] of U1 on F.Cu
    @(30.0000 mm, 34.0000 mm): Pad 25 [GND] of U1 on F.Cu
[clearance]: Clearance violation ( clearance 0.2500 mm; actual 0.2000 mm)
    Local override; error
    @(31.9625 mm, 33.7500 mm): Pad 16 [BAT_SYS] of U1 on F.Cu
    @(30.0000 mm, 34.0000 mm): Pad 25 [GND] of U1 on F.Cu
[clearance]: Clearance violation ( clearance 0.2500 mm; actual 0.2000 mm)
    Local override; error
    @(29.2500 mm, 32.0375 mm): Pad 23 [CHG_IN] of U1 on F.Cu
    @(30.0000 mm, 34.0000 mm): Pad 25 [GND] of U1 on F.Cu
[clearance]: Clearance violation ( clearance 0.2500 mm; actual 0.2250 mm)
    Local override; error
    @(29.7500 mm, 32.0375 mm): Pad 22 [PMID] of U1 on F.Cu
    @(29.3000 mm, 31.7000 mm): Segment [CHG_IN] on F.Cu
[text_height]: Text height out of range (board setup constraints silk text height min height 0.8000 mm; actual 0.7000 mm)
    Rule: board setup constraints silk text height; warning
    @(41.3000 mm, 13.6500 mm): Footprint text of SW1 (VIN)
[text_height]: Text height out of range (board setup constraints silk text height min height 0.8000 mm; actual 0.6500 mm)
    Rule: board setup constraints silk text height; warning
    @(41.6000 mm, 18.7300 mm): Footprint text of SW1 (GND)
[text_height]: Text height out of range (board setup constraints silk text height min height 0.8000 mm; actual 0.6500 mm)
    Rule: board setup constraints silk text height; warning
    @(42.0000 mm, 27.6200 mm): Footprint text of SW1 (CTRL)
[text_height]: Text height out of range (board setup constraints silk text height min height 0.8000 mm; actual 0.6500 mm)
    Rule: board setup constraints silk text height; warning
    @(49.8000 mm, 13.6500 mm): Footprint text of SW1 (VOUT)
[text_height]: Text height out of range (board setup constraints silk text height min height 0.8000 mm; actual 0.6500 mm)
    Rule: board setup constraints silk text height; warning
    @(50.4000 mm, 18.7300 mm): Footprint text of SW1 (GND)
[text_height]: Text height out of range (board setup constraints silk text height min height 0.8000 mm; actual 0.7000 mm)
    Rule: board setup constraints silk text height; warning
    @(84.5500 mm, 33.0700 mm): Footprint text of SW2 (VIN)
[text_height]: Text height out of range (board setup constraints silk text height min height 0.8000 mm; actual 0.6500 mm)
    Rule: board setup constraints silk text height; warning
    @(84.8500 mm, 38.1500 mm): Footprint text of SW2 (GND)
[text_height]: Text height out of range (board setup constraints silk text height min height 0.8000 mm; actual 0.6500 mm)
    Rule: board setup constraints silk text height; warning
    @(85.2500 mm, 47.0400 mm): Footprint text of SW2 (CTRL)
[text_height]: Text height out of range (board setup constraints silk text height min height 0.8000 mm; actual 0.6500 mm)
    Rule: board setup constraints silk text height; warning
    @(93.0500 mm, 33.0700 mm): Footprint text of SW2 (VOUT)
[text_height]: Text height out of range (board setup constraints silk text height min height 0.8000 mm; actual 0.6500 mm)
    Rule: board setup constraints silk text height; warning
    @(93.6500 mm, 38.1500 mm): Footprint text of SW2 (GND)
[text_height]: Text height out of range (board setup constraints silk text height min height 0.8000 mm; actual 0.7000 mm)
    Rule: board setup constraints silk text height; warning
    @(64.6625 mm, 34.0500 mm): Reference field of U2
[silk_overlap]: Silkscreen clearance
    Rule: board setup constraints silk; warning
    @(132.8000 mm, 12.7520 mm): Reference field of J910
    @(129.4000 mm, 12.7520 mm): Reference field of J911
[silk_overlap]: Silkscreen clearance
    Rule: board setup constraints silk; warning
    @(26.6700 mm, 48.6250 mm): Reference field of R50
    @(26.0250 mm, 50.4700 mm): Reference field of C15
[silk_overlap]: Silkscreen clearance
    Rule: board setup constraints silk; warning
    @(145.6775 mm, 26.1877 mm): Segment of R34 on F.Silkscreen
    @(145.2000 mm, 26.4250 mm): Reference field of R34
[silk_overlap]: Silkscreen clearance
    Rule: board setup constraints silk; warning
    @(142.8000 mm, 26.4250 mm): Reference field of R36
    @(143.2775 mm, 26.1877 mm): Segment of R36 on F.Silkscreen
[silk_overlap]: Silkscreen clearance
    Rule: board setup constraints silk; warning
    @(148.0775 mm, 26.1877 mm): Segment of R33 on F.Silkscreen
    @(147.6000 mm, 26.4250 mm): Reference field of R33
[silk_overlap]: Silkscreen clearance
    Rule: board setup constraints silk; warning
    @(140.6775 mm, 26.1877 mm): Segment of R38 on F.Silkscreen
    @(140.2000 mm, 26.4250 mm): Reference field of R38
[silk_overlap]: Silkscreen clearance
    Rule: board setup constraints silk; warning
    @(135.8775 mm, 26.1877 mm): Segment of R35 on F.Silkscreen
    @(135.4000 mm, 26.4250 mm): Reference field of R35
[silk_overlap]: Silkscreen clearance
    Rule: board setup constraints silk; warning
    @(138.2775 mm, 26.1377 mm): Segment of R37 on F.Silkscreen
    @(137.8000 mm, 26.3750 mm): Reference field of R37
[silk_over_copper]: Silkscreen clipped by solder mask
    Local override; warning
    @(84.5500 mm, 33.0700 mm): Footprint text of SW2 (VIN)
    @(82.9000 mm, 31.8000 mm): PTH pad 1 [+3V3] of SW2
[silk_over_copper]: Silkscreen clipped by solder mask
    Local override; warning
    @(41.3000 mm, 13.6500 mm): Footprint text of SW1 (VIN)
    @(39.6500 mm, 12.3800 mm): PTH pad 1 [+5V] of SW1
[silk_over_copper]: Silkscreen clipped by solder mask
    Local override; warning
    @(145.2000 mm, 26.4250 mm): Reference field of R34
    @(146.2000 mm, 27.2500 mm): Pad 2 [EXP_GPB3] of R34 on F.Cu
[silk_over_copper]: Silkscreen clipped by solder mask
    Local override; warning
    @(142.8000 mm, 26.4250 mm): Reference field of R36
    @(143.8000 mm, 25.6000 mm): Pad 1 [MCP_GPB5] of R36 on F.Cu
[silk_over_copper]: Silkscreen clipped by solder mask
    Local override; warning
    @(142.8000 mm, 26.4250 mm): Reference field of R36
    @(143.8000 mm, 27.2500 mm): Pad 2 [EXP_GPB5] of R36 on F.Cu
[silk_over_copper]: Silkscreen clipped by solder mask
    Local override; warning
    @(147.6000 mm, 26.4250 mm): Reference field of R33
    @(148.6000 mm, 27.2500 mm): Pad 2 [EXP_GPB2] of R33 on F.Cu
[silk_over_copper]: Silkscreen clipped by solder mask
    Local override; warning
    @(147.6000 mm, 26.4250 mm): Reference field of R33
    @(148.6000 mm, 25.6000 mm): Pad 1 [MCP_GPB2] of R33 on F.Cu
[silk_over_copper]: Silkscreen clipped by solder mask
    Local override; warning
    @(140.2000 mm, 26.4250 mm): Reference field of R38
    @(141.2000 mm, 27.2500 mm): Pad 2 [EXP_GPB7] of R38 on F.Cu
[silk_over_copper]: Silkscreen clipped by solder mask
    Local override; warning
    @(140.2000 mm, 26.4250 mm): Reference field of R38
    @(141.2000 mm, 25.6000 mm): Pad 1 [MCP_GPB7] of R38 on F.Cu
[silk_over_copper]: Silkscreen clipped by solder mask
    Local override; warning
    @(135.4000 mm, 26.4250 mm): Reference field of R35
    @(136.4000 mm, 25.6000 mm): Pad 1 [MCP_GPB4] of R35 on F.Cu
[silk_over_copper]: Silkscreen clipped by solder mask
    Local override; warning
    @(135.4000 mm, 26.4250 mm): Reference field of R35
    @(136.4000 mm, 27.2500 mm): Pad 2 [EXP_GPB4] of R35 on F.Cu
[silk_over_copper]: Silkscreen clipped by solder mask
    Local override; warning
    @(137.8000 mm, 26.3750 mm): Reference field of R37
    @(138.8000 mm, 27.2000 mm): Pad 2 [EXP_GPB6] of R37 on F.Cu
[silk_over_copper]: Silkscreen clipped by solder mask
    Local override; warning
    @(137.8000 mm, 26.3750 mm): Reference field of R37
    @(138.8000 mm, 25.5500 mm): Pad 1 [MCP_GPB6] of R37 on F.Cu

** Found 0 unconnected pads **

** Found 0 Footprint errors **

** Ignored checks **
    - Footprint has no courtyard defined
    - Track endpoint not centered on via
    - Tuning profile track geometries
    - Footprint doesn't match symbol's footprint filters
    - Footprint component type doesn't match footprint pads

** End of Report **

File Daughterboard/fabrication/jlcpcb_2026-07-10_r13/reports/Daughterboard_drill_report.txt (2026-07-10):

Drill report for Daughterboard.kicad_pcb
Created on 2026-07-09T23:27:49

Copper Layer Stackup:
    =============================================================
    L1 :  F.Cu                      front
    L2 :  In1.Cu                    in1
    L3 :  In2.Cu                    in2
    L4 :  B.Cu                      back

Drill file 'Daughterboard.drl' contains
    plated through holes:
    =============================================================
    T1  0.300mm  0.0118"  (183 holes))
    T2  0.350mm  0.0138"  (3 holes))
    T3  0.400mm  0.0157"  (7 holes))
    T4  0.500mm  0.0197"  (5 holes))
    T5  0.600mm  0.0236"  (4 holes)  (with 4 slots)
    T6  0.950mm  0.0374"  (3 holes))
    T7  1.000mm  0.0394"  (6 holes))
    T8  1.020mm  0.0402"  (18 holes))

    Total plated holes count 229

Not plated through holes are merged with plated holes
    unplated through holes:
    =============================================================

    Total unplated holes count 0

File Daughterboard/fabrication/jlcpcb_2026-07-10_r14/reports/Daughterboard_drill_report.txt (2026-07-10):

Drill report for Daughterboard.kicad_pcb
Created on 2026-07-10T00:45:05

Copper Layer Stackup:
    =============================================================
    L1 :  F.Cu                      front
    L2 :  In1.Cu                    in1
    L3 :  In2.Cu                    in2
    L4 :  B.Cu                      back

Drill file 'Daughterboard.drl' contains
    plated through holes:
    =============================================================
    T1  0.300mm  0.0118"  (179 holes))
    T2  0.350mm  0.0138"  (2 holes))
    T3  0.400mm  0.0157"  (8 holes))
    T4  0.500mm  0.0197"  (6 holes))
    T5  0.600mm  0.0236"  (4 holes)  (with 4 slots)
    T6  0.950mm  0.0374"  (3 holes))
    T7  1.000mm  0.0394"  (6 holes))
    T8  1.020mm  0.0402"  (18 holes))

    Total plated holes count 226

Not plated through holes are merged with plated holes
    unplated through holes:
    =============================================================

    Total unplated holes count 0

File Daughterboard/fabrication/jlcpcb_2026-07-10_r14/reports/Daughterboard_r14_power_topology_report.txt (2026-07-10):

R14 topology audit
Board: Daughterboard.kicad_pcb
PASS
- USB-C A12/B12/shield are GND.
- Charger BAT/SNS pins are protected BAT_SYS.
- Q1/Q2 use CSD18502Q5B 1-8 pad numbering with common-source high-side topology.
- R46 is in series between BATT_RAW_N and GND.
- SRP/SRN filter polarity matches charge-positive/discharge-negative current convention.
- Legacy PACK_P/Q1_DRAIN_COMMON nets are absent.

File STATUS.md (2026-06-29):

# Anubis RC Controller — Implementation Status

_Status snapshot generated 2026-06-27 from a read of the firmware source. "Verified"
here means **implemented and wired end-to-end in the code** (init → input → processing →
output), not that every item has been re-confirmed on the bench. The **Bench-tested?**
column tracks physical hardware confirmation — flip ☐ → ✅ as you validate each item on
real hardware (— = not applicable). Update this file as features land or are tested._

Primary sources reviewed:
- Transmitter: [Hosyond_apr24b/Hosyond_apr24b.ino](Hosyond_apr24b/Hosyond_apr24b.ino) (~18k lines)
- Receiver: [ESPNow_S3_Receiver/ESPNow_S3_Receiver.ino](ESPNow_S3_Receiver/ESPNow_S3_Receiver.ino)
- Hardware/pinout: [README.txt](README.txt), [User_Setup.h](User_Setup.h)
- Changelog: [Hosyond_apr24b/ChangeLog.txt](Hosyond_apr24b/ChangeLog.txt)

---

## ✅ Fully implemented & wired end-to-end

These have a complete path in code and are exercised by the main loop.

| Feature | Notes / location | Bench-tested? |
|---|---|---|
| **Display (ILI9341 240×320 SPI)** | TFT_eSPI, configured via repo [User_Setup.h](User_Setup.h); init in `setup()` ([Hosyond_apr24b.ino:7354](Hosyond_apr24b/Hosyond_apr24b.ino#L7354)). Backlight PWM dimming wired on IO45. | ☐ |
| **Capacitive touch (FT6336)** | `touchPanel.begin()` + polled each loop; full touch UI navigation. | ☐ |
| **Gimbal sticks via ADS1115 (external I²C ADC)** | `initAds1115()`; 4 axes read and normalized in `updateStickInputs()`. | ☐ |
| **ESP-NOW transmit link** | Binding, control packets, ping/latency, telemetry, unbind — `sendEspNowControlPacket()` ([Hosyond_apr24b.ino:5433](Hosyond_apr24b/Hosyond_apr24b.ino#L5433)). Paired with the receiver sketch below. | ☐ |
| **ELRS / CRSF transmit** | UART CRSF channel frames, TX power, device ping, half/full-duplex + auto module-profile detection. `sendElrsChannelFrame()` ([Hosyond_apr24b.ino:5911](Hosyond_apr24b/Hosyond_apr24b.ino#L5911)). | ☐ |
| **Channel processing pipeline** | `updateChannelOutputs()` ([Hosyond_apr24b.ino:10252](Hosyond_apr24b/Hosyond_apr24b.ino#L10252)) applies trim → expo → endpoints → **mixes** → reverse. (NOTE: mixer now *does* drive output math — the changelog's "UI only" note is stale.) | ☐ |
| **Drive types** | Tank (1-stick & 2-stick), Car, X-drone — output shaping in `buildProtocolOutputChannels()` ([Hosyond_apr24b.ino:10291](Hosyond_apr24b/Hosyond_apr24b.ino#L10291)). Saved per model. | ☐ |
| **Per-model storage (EEPROM)** | Name, reverse, trim, failsafe flags, mixes, drive type, tank mode, protocol, rates, expo, endpoints, ESC channel map, ESP-NOW output mode. Versioned schemas w/ first-boot migration in `setup()`. | ☐ |
| **Mixer editor UI** | 4 user mix slots, source/dest cycle, rate/offset (+/- and numpad), per-mix reverse-link. | ☐ |
| **Reverse / Trim / Failsafe / Endpoints / Rates / Expo screens** | All present with touch + D-pad paths. | ☐ |
| **Battery monitor** | Real ADC on IO9 w/ 200k/200k divider, `analogReadMilliVolts()` ([Hosyond_apr24b.ino:10369](Hosyond_apr24b/Hosyond_apr24b.ino#L10361)); "No Batt" / X-icon when absent. | ☐ |
| **Audio (ES8311 codec, I²S)** | `initAudio()` detects codec; UI click sounds + volume popup/mute. Falls back gracefully if codec not detected. | ☐ |
| **D-pad input** | 5-way nav via **PCF8575** I²C expander (`readPcf8575()`), wired into all major screens. *(See discrepancy note re: MCP23017.)* | ☐ |
| **OTA update service** | SoftAP + STA HTTP upload server, `updateOtaService()` ([Hosyond_apr24b.ino:4398](Hosyond_apr24b/Hosyond_apr24b.ino#L4398)). | ☐ |
| **Power button / soft power / deep sleep** | Boot hold, auto deep-sleep on inactivity, display wake on stick/touch. | ☐ |
| **Status RGB LED** | IO42 single-wire LED encodes fault/status codes (no-ADS, no-codec, etc.). | ☐ |
| **Startup throttle safety** | Blocks until throttle is safe, with tap-bypass. | ☐ |
| **Misc UI** | Model name keyboard (shift), main-screen swipe-to-timer, "Space Game" easter egg. | ☐ |

### Receiver ([ESPNow_S3_Receiver](ESPNow_S3_Receiver/ESPNow_S3_Receiver.ino))
| Feature | Notes | Bench-tested? |
|---|---|---|
| **ESP-NOW receive + bind** | Matches TX packet protocol; peer add, telemetry reply. | ☐ |
| **PWM servo output** | Up to `RC_OUTPUT_COUNT` channels, 50 Hz, 1000–2000 µs. | ☐ |
| **iBus serial output** | 14-channel iBus frames on D5, selectable via `ESPNOW_FLAG_OUTPUT_IBUS`. | ☐ |
| **Drive-type/tank-mode awareness** | Receives and labels drive/tank mode from packet. | ☐ |

---

## 🟡 Partly wired / needs confirmation

| Feature | Status | Bench-tested? |
|---|---|---|
| **Charging detection** | Voltage reading is real; "charging" is **inferred from rising voltage**, not a charger status pin (board doesn't route one). Best-effort only — see [ChangeLog.txt:163](Hosyond_apr24b/ChangeLog.txt#L163). | ☐ |
| **ELRS RX configuration screen** | `SCREEN_ELRS_RX_CONFIG` + parameter read/write code exists (model ID, failsafe, PWM ch, TX power). Depends on live module param protocol — **bench-verify against real ELRS RX**. | ☐ |
| **ELRS bind** | `sendElrsBindCommand()` implemented; relies on module field index that varies by profile (auto-detect fallback constants present). Confirm on hardware. | ☐ |
| **ELRS module auto-profile detect** | `ELRS_MODULE_PROFILE_AUTO` default; switches half/full duplex & pins at runtime. Logic present, hardware-dependent. | ☐ |

---

## ⛔ Stubbed / disabled / dead code

| Item | Status |
|---|---|
| **Stick calibration screen** | Screen `SCREEN_STICK_CALIBRATION` and capture/sweep logic exist but are **disabled**: `STICK_CAL_SCREEN_ENABLED = false` ([Hosyond_apr24b.ino:210](Hosyond_apr24b/Hosyond_apr24b.ino#L210)). |
| **Stick calibration values** | Uses **hardcoded** min/center/max — `STICK_CAL_USE_HARDCODED_DEFAULTS = true` ([Hosyond_apr24b.ino:801](Hosyond_apr24b/Hosyond_apr24b.ino#L801)), values at [Hosyond_apr24b.ino:940](Hosyond_apr24b/Hosyond_apr24b.ino#L940). Live calibration not in use. |
| **MCP23017 driver** | `initMcp23017()` fully written but **never called** ([Hosyond_apr24b.ino:9823](Hosyond_apr24b/Hosyond_apr24b.ino#L9823)) — D-pad actually runs on PCF8575. Legacy/unused. |
| **`drawControllerPlaceholderScreen()`** | Placeholder controller-settings screen helper ([Hosyond_apr24b.ino:11916](Hosyond_apr24b/Hosyond_apr24b.ino#L11916)); some controller settings noted as hardcoded pending a user-facing menu ([Hosyond_apr24b.ino:209](Hosyond_apr24b/Hosyond_apr24b.ino#L209)). |
| **ELRS passive sniff mode** | `ELRS_PASSIVE_SNIFF_MODE = false` ([Hosyond_apr24b.ino:302](Hosyond_apr24b/Hosyond_apr24b.ino#L302)); diagnostic-only path, off by default (disables ESP-NOW when on). |

---

## ⚠️ Discrepancies worth resolving

1. **D-pad expander: README vs firmware.** Hardware list in [README.txt:23](README.txt#L23) specifies an **MCP23017**, but the active firmware reads a **PCF8575** (same 0x20–0x27 address range). The MCP23017 init exists but is never called. Confirm which chip is actually on the board and either re-enable the MCP path or correct the BOM.
2. **Stale changelog.** [ChangeLog.txt:16](Hosyond_apr24b/ChangeLog.txt#L16) says the mixer "does not yet drive any actual output math." It now does (see `updateChannelOutputs()`).

---

## Build & flash

- Toolchain/process documented in [scripts/README.md](scripts/README.md).
- FQBN: `esp32:esp32:esp32s3:FlashSize=16M,PartitionScheme=app3M_fat9M_16MB`.
- `scripts\setup-libraries.ps1` (one-time) → `scripts\build-and-flash.ps1` (dev loop).
- TFT_eSPI is configured by copying repo [User_Setup.h](User_Setup.h) **into the library**.

## Hardware peripherals — wiring status

| Peripheral | Bus / pin | Firmware status | Bench-tested? |
|---|---|---|---|
| ILI9341 display | SPI 10/11/12/13/46, BL 45 | ✅ active | ☐ |
| FT6336 touch | I²C 15/16 (rst 18, int 17) | ✅ active | ☐ |
| ADS1115 (gimbals) | I²C | ✅ active | ☐ |
| PCF8575 (D-pad) | I²C 0x20–0x27 | ✅ active | ☐ |
| MCP23017 (D-pad, per BOM) | I²C | ⛔ code present, unused | — |
| ES8311 codec + I²S audio | I²S 4/5/6/7/8, EN IO1 | ✅ active (graceful fallback) | ☐ |
| Battery ADC | IO9 (200k/200k divider) | ✅ active | ☐ |
| RGB status LED | IO42 | ✅ active | ☐ |
| ELRS module UART | Serial1 (pins 43/44, profile-dependent) | ✅ TX; RX-config 🟡 | ☐ |
| SD card | SDIO 38/39/40/41/47/48 | ⛔ not used — no SD/FS code in firmware | — |
</content>
</invoke>

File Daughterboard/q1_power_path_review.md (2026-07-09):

# Q1 / BQ28Z610 Power-Path Review — First Pass

Reviewed: 2026-07-09 · Sources: TI BQ28Z610 datasheet SLUSAS3D (rev. June 2021), CSD83325L datasheet (in repo), board netlist (`daughterboard.net`), `power_board_design.md`

**Verdict: the power-path release gate was justified — as wired, the battery protection is non-functional and the protection FETs would be gate-overstressed. Do not build or connect a pack until the rework below is done.** The BQ28Z610 is a *high-side* FET-drive device (confirmed in the datasheet block diagram, §8.3.13, and §7.25), but the board implements Q1 as a *low-side* switch pair with the sense resistor wired in parallel with it.

## What checks out

- **U2 (BQ28Z610, SON-12 DRZ) pin mapping is correct** — all 12 pins plus the PWPD pad (→ VSS) match datasheet Table 6-1 exactly.
- **SRP/SRN input filter** (R47/R48 100 Ω + C31 0.1 µF) matches the datasheet recommendation.
- **PBI capacitor** C30 = 2.2 µF to VSS matches the CPBI spec.
- **Cell-sense series resistors** R14/R15 = 470 Ω are within the recommended 100 Ω–1 kΩ balancing range; VC2←PACK_P (top cell), VC1←CELL_MID, VSS←BATT_RAW_N are correct.
- **A common-drain dual NFET is the right device structure** for the back-to-back pair (both the original CSD83325L and the PT8810 substitute are common-drain).

## Findings

**F1 — FETs are on the wrong side of the pack (blocker).**
The BQ28Z610 drives *high-side* N-channel FETs: §7.25 specifies the on-state gate voltage V(FETON) as **8.75–10.25 V above VC2** (the top of the battery stack), and §8.3.13 says that when drive is disabled, "an internal circuit discharges CHG to VC2 and DSG to PACK" — i.e., gate pulled to the *source of a high-side FET*. The board instead places Q1 low-side: S1 → BATT_RAW_N, S2 → GND, gates from DSG/CHG via R21/R22. Consequences with this wiring:
- **Off never happens:** "off" leaves the gates at VC2/PACK potential (≈6–8.4 V for 2S), which is far above the FETs' ~1 V threshold when their sources sit at pack-negative. The protection FETs can never be turned off.
- **On destroys the gates:** "on" drives the gates to VC2 + ~9.5 V ≈ up to ~18 V relative to a low-side source — beyond any 8205-class or CSD83325L (±10 V) gate rating.

**F2 — Sense resistor is in parallel with the FETs, not in series (blocker).**
R46 (2 mΩ) connects BATT_RAW_N ↔ GND, and Q1 (S1…S2) *also* connects BATT_RAW_N ↔ GND. In the TI topology the sense resistor is in series in the PACK− line. As wired: even if the FETs could open, current continues through R46 (protection cannot interrupt anything), and when the FETs conduct they shunt the sense resistor, corrupting coulomb counting.

**F3 — Charger bypasses the protection FETs (blocker).**
BQ25887 BAT1/BAT2/SNS1/SNS2 (U1 pins 13–16) tie directly to PACK_P (cell positive). In the TI application, the charger sits on the *system side* of the FET pair so the CHG FET can interrupt charging on a fault (SOV, overcurrent-in-charge). As wired, charge current never passes through Q1 regardless of which side Q1 is on.

**F4 — USB-C ground pin A12 is tied to the FET midpoint (blocker, likely a net-label slip).**
J1.A12 (a GND pin of the GCT USB4125) is on net Q1_DRAIN_COMMON; J1.B12 and the shield are on GND. All ground pins are commoned inside any attached plug/cable, so plugging in USB-C shorts the FET common-drain node to GND. A12 must be on GND.

**F5 — C10 references the FET midpoint.**
The lower-cell filter cap C10 (100 nF) connects CELL_MID ↔ Q1_DRAIN_COMMON; it should reference BATT_RAW_N.

**F6 — SRP/SRN orientation is probably swapped (verify).**
Datasheet pin table: "SRP is the top of the sense resistor" (battery side in Figure 9-1). The board has SRN←BATT_RAW_N and SRP←GND. A swap inverts the charge/discharge sign convention and misdirects the directional protections (SCC vs. SCD1/SCD2). Check against Figure 9-1 during rework.

**F7 — Reference gate network is missing.**
Figure 9-1 includes 10 MΩ gate-bleed resistors (PACK↔DSG and VC2↔CHG — also the load condition under which the §7.25 drive specs are defined) and zener clamps. The board has only the 100 Ω series resistors R21/R22.

**F8 — FET part selection needs closing (open item).**
- **PT8810** (PUOLOP, LCSC C3019811): confirmed 20 V dual N-channel *common-drain*, 22 mΩ @ 4.5 V — electrically the right class, but the **pinout could not be retrieved online** in this pass. The schematic symbol assumes 1=S1, 2=G1, 3=S2, 4=G2, 5/6=D1, 7/8=D2, while the common 8205A TSSOP-8 convention is 1=G1, 2=S1 — a gate/source swap risk. Pull the PDF from the LCSC product page (C3019811) and verify before fab.
- **Gate rating margin:** V(FETON) can reach 10.25 V. The original CSD83325L is only ±10 V VGS absolute max — marginal even before the substitution. Whichever part is used should have **VGS(max) ≥ 12 V** (and VDS ≥ 12 V is ample for 2S). Verify PT8810's actual VGS rating; if it is ±8–10 V like most 8205-class parts, choose a different FET.

## Proposed rework (net level)

1. **Move Q1 high-side:** PACK_P → [CHG FET: source at PACK_P, gate ← R22 ← CHG] → common drain → [DSG FET: gate ← R21 ← DSG, source at new SYS+ net] → SYS+ → F4 → BAT_SYS. (CHG FET source faces the battery because CHG-off discharges to VC2; DSG FET source faces the system because DSG-off discharges to PACK.)
2. **Move the charger to the system side:** U1 BAT1/BAT2/SNS1/SNS2 → SYS+.
3. **PACK pin sense:** R16 (100 Ω to U2.8) taps SYS+ directly (pre-fuse), so PACK sensing reflects the system node and the DSG-off gate discharge references the right potential.
4. **Negative path:** BATT_RAW_N —R46— GND becomes the *only* negative link (falls out of step 1). C10 → CELL_MID↔BATT_RAW_N. J1.A12 → GND.
5. **SRP/SRN:** orient per Figure 9-1 (SRP to the battery side, pending figure check).
6. **Gate network:** add 10 MΩ bleeds (SYS+↔DSG gate, PACK_P↔CHG gate) and consider the Figure 9-1 zener clamps.
7. **Close F8:** verify PT8810 pinout + VGS(max) from the LCSC datasheet, or select a ≥±12 V VGS common-drain dual.
8. **After rework:** update `power_board_design.md`, re-run `scripts\pcb-check.ps1`, and bench-validate protection trips (BQStudio data-flash configuration, which the design doc already notes is required) before trusting a live pack.

A side benefit of the correct high-side topology: BATT_RAW_N and GND stay within millivolts of each other (joined by the 2 mΩ sense resistor), so the gauge's I2C — referenced to its VSS — remains valid to the MCU even during a protection fault, which is exactly why TI uses high-side drive here.

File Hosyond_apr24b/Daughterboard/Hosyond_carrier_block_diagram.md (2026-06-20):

# Hosyond Carrier Board Block Diagram

This carrier board is intended to replace loose wiring with a clean plug-in harness.
It should mostly route signals between prebuilt modules instead of recreating tiny
IC circuits on the PCB.

## System Diagram

```mermaid
flowchart TD
  H["Hosyond ESP32-S3 Display"]

  B["Protected 1S LiPo Battery"]
  USB["External USB-C Breakout"]
  SW5["5V Power Switch"]
  SW3["3.3V Power Switch"]

  ELRS["ELRS Module"]
  ADSA["ADS1115 A\nPrimary sticks"]
  ADSB["ADS1115 B\nFuture analog aux"]
  AUXA["J13 Aux Analog\nA0/A1"]
  AUXB["J23 Aux Analog\nA2/A3"]
  PCF["PCF8575\nDigital expansion"]
  PCFI2C["J22 PCF8575\nI2C + power"]
  PCFA["U3 PCF8575\nSide A"]
  PCFB["U4 PCF8575\nSide B"]

  LG["Left Gimbal"]
  RG["Right Gimbal"]
  DPAD["5-way D-pad"]
  LED["Power LED Ring"]
  EXPA["J19 PCF Expansion A\nP06-P09"]
  EXPB["J20 PCF Expansion B\nP10-P13"]
  EXPC["J21 PCF Expansion C\nP14-P17"]
  PWR["Power Button"]

  B -->|"BAT+ / BAT-"| H
  USB -->|"VBUS, GND, D+, D-"| H

  H -->|"5V rail"| SW5
  H -->|"GPIO14 / ELRS_POWER_CTRL"| SW5
  SW5 -->|"switched 5V"| ELRS
  H <-->|"UART TX/RX"| ELRS

  H -->|"3.3V rail"| SW3
  H -->|"GPIO21 / I2C_POWER_CTRL"| SW3
  SW3 -->|"switched 3.3V"| ADSA
  SW3 -->|"switched 3.3V"| ADSB
  SW3 -->|"switched 3.3V"| PCFI2C

  H <-->|"I2C SDA/SCL"| ADSA
  H <-->|"I2C SDA/SCL"| ADSB
  H <-->|"I2C SDA/SCL"| PCFI2C
  PCFI2C -->|"3.3V, GND"| PCFA
  PCFI2C -->|"3.3V, GND"| PCFB
  PCFA -.->|"same PCF8575 module"| PCF
  PCFB -.->|"same PCF8575 module"| PCF

  LG -->|"X/Y analog"| ADSA
  RG -->|"X/Y analog"| ADSA
  AUXA -->|"A0/A1 analog"| ADSB
  AUXB -->|"A2/A3 analog"| ADSB

  DPAD -->|"P00-P04"| PCFA
  PCFA -->|"P05 / POWER_LED_CTRL"| LED
  PCFA -->|"P06-P08"| EXPA
  PCFB -->|"P09"| EXPA
  PCFB -->|"P10-P13"| EXPB
  PCFB -->|"P14-P17"| EXPC

  PWR -->|"GPIO2 / GPIO3"| H
```

## Main Design Rules

- Keep the power button on direct Hosyond GPIO pins `GPIO2` and `GPIO3` so it can wake the ESP32 from deep sleep.
- Use `GPIO14` to control the switched `5V` rail for the ELRS module.
- Use `GPIO21` to control the switched `3.3V` rail for I2C modules and the D-pad.
- Keep all grounds common.
- Switch the positive power rails, not ground.
- Do not connect USB `VBUS` directly to the LiPo battery.
- Do not connect the LiPo battery directly to the `5V` rail.
- Add test pads for `5V`, `3.3V`, `GND`, `SDA`, `SCL`, `UART_TX`, and `UART_RX`.

## I2C Power Caution

If the `3.3V` rail to the I2C modules is switched off while `SDA` and `SCL` remain
connected, some modules can be partially powered through the I2C lines. The best
fix is to use an I2C power switch/bus-isolation board or add proper bus isolation
in the final PCB design.

## Files

- Detailed net table: `Hosyond_carrier_net_table.csv`

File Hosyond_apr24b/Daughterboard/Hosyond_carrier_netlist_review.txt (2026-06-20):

Netlist: C:\Users\Avala\OneDrive\Desktop\sketch_may7a\Hosyond_apr24b\Daughterboard\daughterboard\daughterboard.net
Components: 36
J1, J10, J11, J12, J13, J14, J15, J16, J17, J18, J19, J2, J20, J21, J22, J23, J24, J25, J3, J4, J5, J6, J7, J8, J9, TP1, TP2, TP3, TP4, TP5, TP6, TP7, U1, U2, U3, U4
Nets: 51

Checklist comparison:
  Missing pins from netlist/check symbols: 0
  Label mismatches: 11
    U3.3: expected DPAD_SELECT, actual P00 (PCF8575 P00)
    U3.4: expected DPAD_LEFT, actual P01 (PCF8575 P01)
    U3.5: expected DPAD_UP, actual P02 (PCF8575 P02)
    U3.6: expected DPAD_DOWN, actual P03 (PCF8575 P03)
    U3.7: expected DPAD_RIGHT, actual P04 (PCF8575 P04)
    U3.8: expected POWER_LED_CTRL, actual P05 (PCF8575 P05)
    J14.1: expected DPAD_SELECT, actual P00 (D-pad select)
    J14.2: expected DPAD_LEFT, actual P01 (D-pad left)
    J14.3: expected DPAD_UP, actual P02 (D-pad up)
    J14.4: expected DPAD_DOWN, actual P03 (D-pad down)
    J14.5: expected DPAD_RIGHT, actual P04 (D-pad right)

Critical nets:
  GND: 30 nodes -> J1.2, J10.3, J10.4, J12.2, J13.1, J13.4, J14.7, J15.2, J18.2, J2.2, J22.2, J23.1, J23.4, J24.3, J24.4, J25.3, J25.4, J4.1, J4.4, J5.1, J5.4, J6.2, J7.2, J9.3, J9.4, TP3.1, U1.2, U2.2, U3.1, U4.1
  5v: 4 nodes -> J1.1, J25.1, J25.2, TP1.1
  5V: 4 nodes -> J1.1, J25.1, J25.2, TP1.1
  3v3: 4 nodes -> J2.1, J24.1, J24.2, TP2.1
  3V3: 4 nodes -> J2.1, J24.1, J24.2, TP2.1
  3v3_SW: 15 nodes -> J13.3, J13.6, J22.1, J23.3, J23.6, J4.3, J4.6, J5.3, J5.6, J9.1, J9.2, U1.1, U2.1, U3.2, U4.2
  3V3_SW: 15 nodes -> J13.3, J13.6, J22.1, J23.3, J23.6, J4.3, J4.6, J5.3, J5.6, J9.1, J9.2, U1.1, U2.1, U3.2, U4.2
  5v_SW: 4 nodes -> J10.1, J10.2, J14.6, J6.1
  5V_SW: 4 nodes -> J10.1, J10.2, J14.6, J6.1
  I2C_SCL: 5 nodes -> J2.3, J22.3, TP5.1, U1.3, U2.3
  I2C_SDA: 5 nodes -> J2.4, J22.4, TP4.1, U1.4, U2.4
  UART_TX: 3 nodes -> J1.3, J6.4, TP6.1
  UART_RX: 3 nodes -> J1.4, J6.3, TP7.1
  A0_A: 2 nodes -> J4.2, U1.7
  A1_A: 2 nodes -> J4.5, U1.8
  A2_A: 2 nodes -> J5.2, U1.9
  A3_A: 2 nodes -> J5.5, U1.10
  A0_B: 2 nodes -> J13.2, U2.7
  A1_B: 2 nodes -> J13.5, U2.8
  A2_B: 2 nodes -> J23.2, U2.9
  A3_B: 2 nodes -> J23.5, U2.10
  P00: 2 nodes -> J14.1, U3.3
  P01: 2 nodes -> J14.2, U3.4
  P02: 2 nodes -> J14.3, U3.5
  P03: 2 nodes -> J14.4, U3.6
  P04: 2 nodes -> J14.5, U3.7
  P05: 3 nodes -> J12.1, J18.1, U3.8
  P06: 2 nodes -> J19.1, U3.9
  P07: 2 nodes -> J19.2, U3.10
  P08: 2 nodes -> J19.3, U3.11
  P09: 2 nodes -> J19.4, U4.11
  P10: 2 nodes -> J20.1, U4.10
  P11: 2 nodes -> J20.2, U4.9
  P12: 2 nodes -> J20.3, U4.8
  P13: 2 nodes -> J20.4, U4.7
  P14: 2 nodes -> J21.1, U4.6
  P15: 2 nodes -> J21.2, U4.5
  P16: 2 nodes -> J21.3, U4.4
  P17: 2 nodes -> J21.4, U4.3
  GPIO14: 2 nodes -> J25.7, J3.3
  GPIO21: 2 nodes -> J24.7, J3.4
  ON: 2 nodes -> J24.5, J25.5
  OFF: 2 nodes -> J24.6, J25.6
  NC: 9 nodes -> J10.5, J10.6, J10.7, J17.1, J17.2, J22.5, J9.5, J9.6, J9.7

One-node nets:
  CC1: J7.3
  CC2: J7.6

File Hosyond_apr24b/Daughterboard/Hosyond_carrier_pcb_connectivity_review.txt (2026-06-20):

PCB: C:\Users\Avala\OneDrive\Desktop\sketch_may7a\Hosyond_apr24b\Daughterboard\daughterboard\daughterboard.kicad_pcb
Nets seen: 51  Footprints: 36  Tracks: 400  Vias: 31  Zones: 1

Zones:
  GND@B.Cu

Special nets expected to be intentionally unrouted/disconnected:
  NC: OK nodes=9 tracks=0 vias=0
    nodes: J10.5, J10.6, J10.7, J17.1, J17.2, J22.5, J9.5, J9.6, J9.7
  CC1: OK nodes=1 tracks=0 vias=0
    nodes: J7.3
  CC2: OK nodes=1 tracks=0 vias=0
    nodes: J7.6
  ADDR: OK nodes=2 tracks=0 vias=0
    nodes: U1.5, U2.5
  ALRT: OK nodes=2 tracks=0 vias=0
    nodes: U1.6, U2.6
  ON: OK nodes=2 tracks=0 vias=0
    nodes: J24.5, J25.5
  OFF: OK nodes=2 tracks=0 vias=0
    nodes: J24.6, J25.6

Key routed nets:
  GND: nodes=30 tracks=3 vias=3
    GND vias: 109 116, 229.2643 128.1549, 112 116
  3v3: nodes=4 tracks=13 vias=2
  3v3_SW: nodes=15 tracks=66 vias=2
  5v: nodes=4 tracks=15 vias=1
  5v_SW: nodes=4 tracks=15 vias=2
  I2C_SCL: nodes=5 tracks=29 vias=1
  I2C_SDA: nodes=5 tracks=22 vias=3
  UART_TX: nodes=3 tracks=20 vias=2
  UART_RX: nodes=3 tracks=17 vias=1

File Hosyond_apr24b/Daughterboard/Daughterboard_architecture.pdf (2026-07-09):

1 | 2 | 3 | 4 | 5 | 6 | 7 | 8
1 | 2 | 3 | 4 | 5 | 6 | 7 | 8

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
Size: A3 | Rev: A-first-pass | F Date: 2026-06-30
KiCad E.D.A. 10.0.3 | Id: 1/1

## Title: USB-C 1S2P 18650 Power Board

### File: Daughterboard.kicad_sch

### Sheet: /

## Daughterboard

Architecture schematic: USB-C, 1S2P charge, 5V/1A, 3V3/500mA.

First pass; finalize passives and footprints before PCB.

switched load power +3V3_SW @ 500mA +5V_SW @ 1A OUTPUTS

# J2Power outputs

GPIO pulse on CTRL pushbutton power switch POLOLU | #2808
SW1 Pololu #2808 | 5V switch

1 A max output 5 V boost TPS61023 U3

TPS61023 5V | >=3 A continuous margin OV/UV/OCP/short BQ2970 + back-to-back FETs PACK PROTECTION
A2BQ2970 + dual NFET | matched cells only per-cell fuse/PTC 1S2P pack

2x 18650

BT1

2x 18650 1S2P

### CC1/CC2: 5.1k Rd 5 V sink only USB-C RECEPTACLE

J1USB-C 5V Sink

1.5A adapter mode Fuse + TVS + CIN

### INPUT PROTECTION

A1

Fuse + VBUS TVS + CIN

TS: 10k NTC

I_CHG <= 1.5 A 1S charger + power path

BQ24074

# U1BQ24074RGT

500 mA max output 3.3 V buck-boost TPS63031 U4

TPS63031 3V3

GPIO pulse on CTRL pushbutton power switch POLOLU | #2808
SW2 Pololu #2808 | 3V3 switch

GPIO3 -> CTRL_3V3_SW

GPIO2 -> CTRL_5V_SW

### ESP32-S3 GPIO

J3Hosyond ESP32-S3 GPIO

USB_VBUS | +5V CTRL_5V_SW
CTRL_3V3_SW | +3V3 BAT_SYS Design limits: - Charge current: 1.5 A max - 5 V rail: 1 A max - 3.3 V rail: 500 mA max - Full-load battery current estimate at 3.3 V pack: about 2.24 A plus transients - Use matched, voltage-balanced 18650 cells only USB-C note: plain 5.1k CC pulldowns make this a 5 V sink. For fixed 1.5 A input current, use a capable USB-C adapter, add a 500 mA / 1.5 A selector, or add Type-C current-detect/PD circuitry before drawing adapter-level current. Output power switching: Pololu #2808 modules sit after the regulators. ESP32 GPIOs pulse CTRL high to turn on, pulse CTRL low to turn off, then return to input/high-Z. Suggested pins: GPIO2 for 5 V, GPIO3 for 3.3 V.
PACK_P / PACK_N | BATT_RAW_P / BATT_RAW_N | +5V_SW
CHG_IN | +3V3_SW

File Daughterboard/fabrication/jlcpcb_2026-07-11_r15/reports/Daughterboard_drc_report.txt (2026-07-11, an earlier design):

** Drc report for daughterboard.kicad_pcb **
** Created on 2026-07-11T15:29:57 **
** Report includes: Errors, Warnings **

** Found 34 DRC violations **
[text_height]: Text height out of range (board setup constraints silk text height min height 0.8000 mm; actual 0.7000 mm)
    Rule: board setup constraints silk text height; warning
    @(17.3000 mm, 32.9550 mm): Reference field of Q2
[text_height]: Text height out of range (board setup constraints silk text height min height 0.8000 mm; actual 0.7000 mm)
    Rule: board setup constraints silk text height; warning
    @(41.3000 mm, 13.6500 mm): Footprint text of SW1 (VIN)
[text_height]: Text height out of range (board setup constraints silk text height min height 0.8000 mm; actual 0.6500 mm)
    Rule: board setup constraints silk text height; warning
    @(41.6000 mm, 18.7300 mm): Footprint text of SW1 (GND)
[text_height]: Text height out of range (board setup constraints silk text height min height 0.8000 mm; actual 0.6500 mm)
    Rule: board setup constraints silk text height; warning
    @(42.0000 mm, 27.6200 mm): Footprint text of SW1 (CTRL)
[text_height]: Text height out of range (board setup constraints silk text height min height 0.8000 mm; actual 0.6500 mm)
    Rule: board setup constraints silk text height; warning
    @(49.8000 mm, 13.6500 mm): Footprint text of SW1 (VOUT)
[text_height]: Text height out of range (board setup constraints silk text height min height 0.8000 mm; actual 0.6500 mm)
    Rule: board setup constraints silk text height; warning
    @(50.4000 mm, 18.7300 mm): Footprint text of SW1 (GND)
[text_height]: Text height out of range (board setup constraints silk text height min height 0.8000 mm; actual 0.7000 mm)
    Rule: board setup constraints silk text height; warning
    @(84.5500 mm, 33.0700 mm): Footprint text of SW2 (VIN)
[text_height]: Text height out of range (board setup constraints silk text height min height 0.8000 mm; actual 0.6500 mm)
    Rule: board setup constraints silk text height; warning
    @(84.8500 mm, 38.1500 mm): Footprint text of SW2 (GND)
[text_height]: Text height out of range (board setup constraints silk text height min height 0.8000 mm; actual 0.6500 mm)
    Rule: board setup constraints silk text height; warning
    @(85.2500 mm, 47.0400 mm): Footprint text of SW2 (CTRL)
[text_height]: Text height out of range (board setup constraints silk text height min height 0.8000 mm; actual 0.6500 mm)
    Rule: board setup constraints silk text height; warning
    @(93.0500 mm, 33.0700 mm): Footprint text of SW2 (VOUT)
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

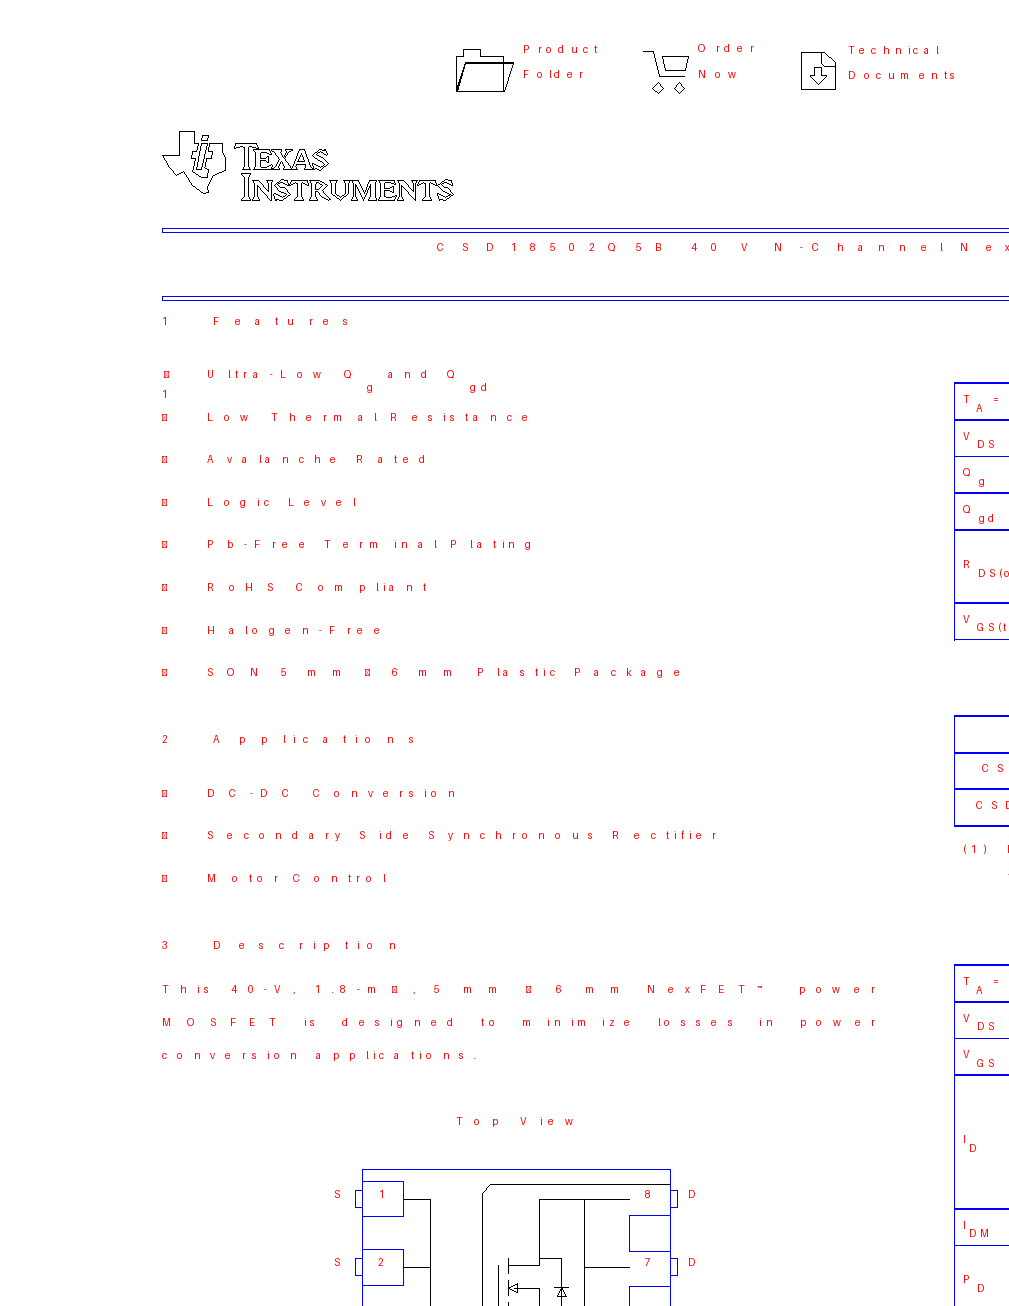
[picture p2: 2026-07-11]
Daughterboard/tmp_csd18502_page1_pinout.png

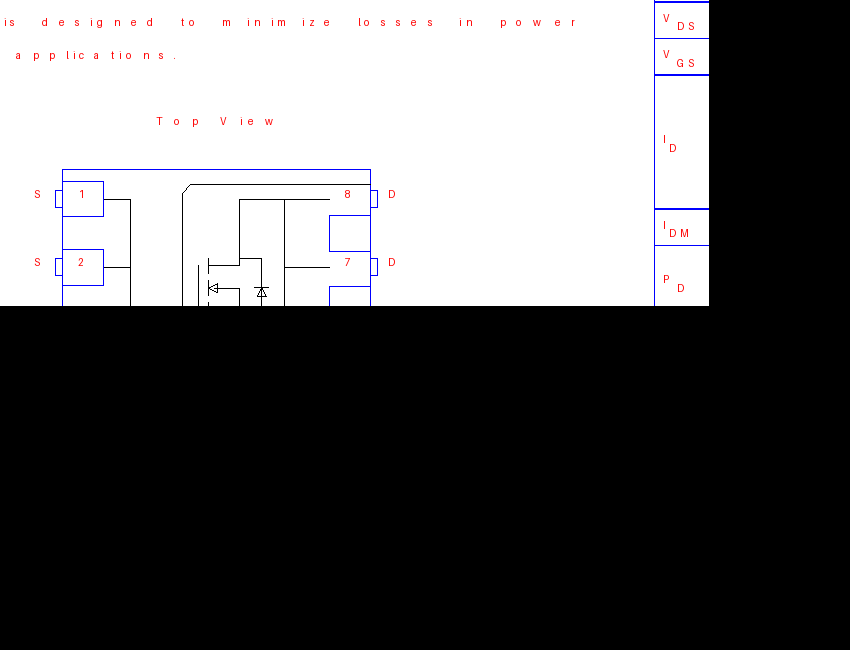
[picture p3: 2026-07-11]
Daughterboard/tmp_csd18502_pinout_crop.png

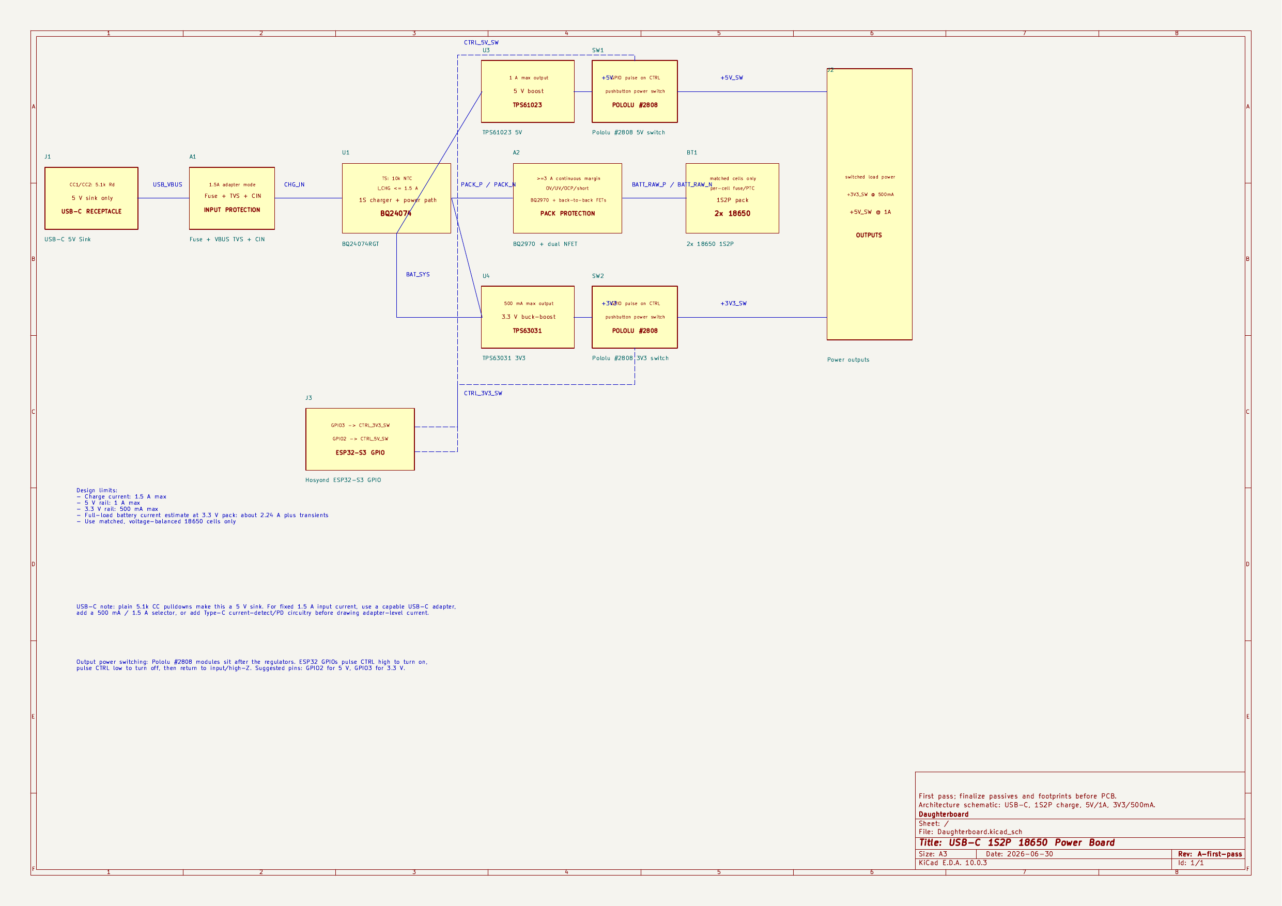
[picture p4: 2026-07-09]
Hosyond_apr24b/Daughterboard/Daughterboard_architecture_preview-1.png

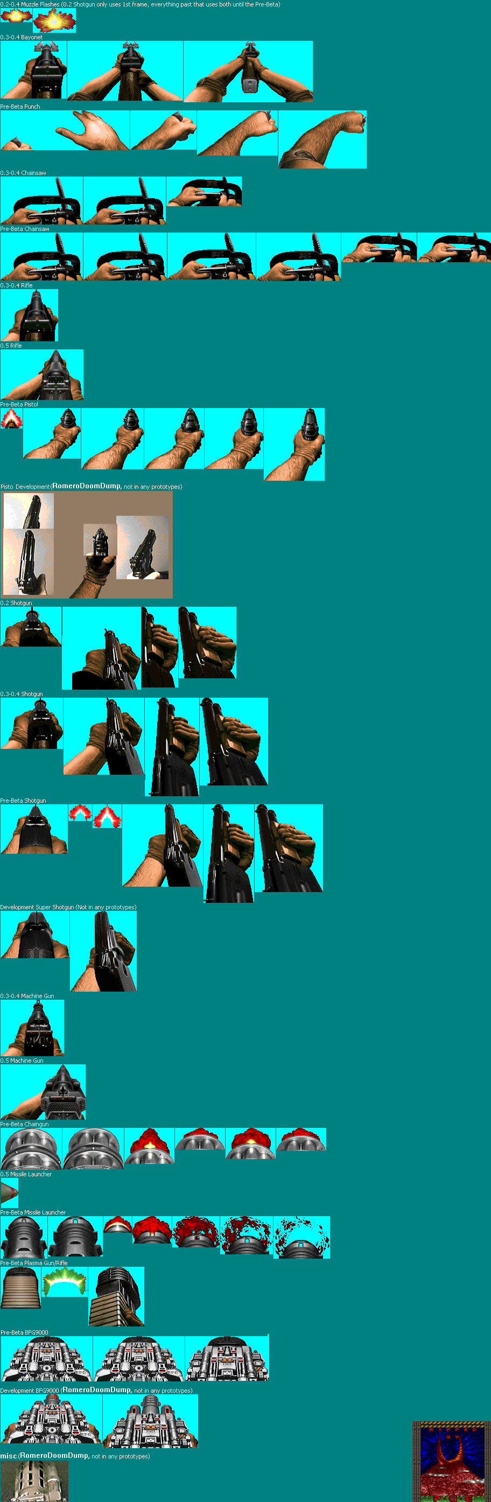
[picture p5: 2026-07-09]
Hosyond_apr24b/Games/Dungeon_Run_Weapons_Held.png

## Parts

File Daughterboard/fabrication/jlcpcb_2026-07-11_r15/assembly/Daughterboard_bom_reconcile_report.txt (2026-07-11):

BOM reconcile report - jlcpcb_2026-07-11_r15 - 2026-07-11T15:29:58

In carried JLC BOM but NOT on the current board (delete from BOM or investigate):
  (none)

On the board but NOT in the JLC BOM (add LCSC mapping, or confirm hand-solder):
  J5
  J6
  SW1
  SW2

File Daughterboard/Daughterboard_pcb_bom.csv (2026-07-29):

Section | Reference | Part / Value | Footprint | Nets | Notes | Purchase Link
USB-C input | J1 | USB-C 5V Sink | Connector_USB:USB_C_Receptacle_GCT_USB4125-xx-x_6P_TopMnt_Horizontal | CC1,CC2,GND,USB_VBUS | Power-only sink; CC1/CC2 each have 5.1k Rd to GND. | https://www.digikey.com/en/products/result?keywords=GCT+USB4125+USB-C+receptacle+6+pin
USB-C input | R1 | 5.1k 1% | Resistor_SMD:R_0603_1608Metric | CC1,GND | USB-C Rd. | https://www.digikey.com/en/products/result
USB-C input | R2 | 5.1k 1% | Resistor_SMD:R_0603_1608Metric | CC2,GND | USB-C Rd. | https://www.digikey.com/en/products/result
USB-C input | F1 | 2A hold polyfuse | Fuse:Fuse_1206_3216Metric | CHG_IN,USB_VBUS | Input fuse/polyfuse; choose exact SMD PTC/fuse current rating before layout. | https://www.digikey.com/en/products/result?keywords=2A+hold+polyfuse+resettable+fuse+PTC+SMD
USB-C input | D1 | 5V VBUS TVS | Diode_SMD:D_SOD-323 | CHG_IN,GND | Place close to USB-C connector. | https://www.digikey.com/en/products/result?keywords=5V+VBUS+TVS+SOD-323+TVS+diode
USB-C input | C1 | 10uF 10V X5R | Capacitor_SMD:C_0805_2012Metric | CHG_IN,GND | Charger input bulk. | https://www.digikey.com/en/products/result
USB-C input | C2 | 100nF 10V X7R | Capacitor_SMD:C_0603_1608Metric | CHG_IN,GND | Charger input bypass. | https://www.digikey.com/en/products/result
2S charger | U1 | BQ25887RGE 2S charger | Package_DFN_QFN:Texas_RGE0024H_VQFN-24-1EP_4x4mm_P0.5mm_EP2.7x2.7mm | BAT_SYS,BTST,CBSET,CELL_MID,CHG_IN,CHG_STAT,CHG_SW,GND,I2C_SCL,I2C_SDA,ILIM,PG_STAT,PMID,REGN,TS | USB 5V boost-mode charger connected on the protected/system side of the BQ28Z610 high-side FETs. | https://www.digikey.com/en/products/result?keywords=BQ25887RGE
2S charger | L3 | 1uH >=4A sat | Inductor_SMD:L_APV_ANR5040 | CHG_SW,PMID | BQ25887 boost-charge SMD inductor; finalize DCR/current from layout and charge limit. | https://www.digikey.com/en/products/result?keywords=1uH+%3E%3D4A+sat+shielded+inductor+SMD
2S charger | R3 | 806R 1% TBD | Resistor_SMD:R_0603_1608Metric | GND,ILIM | Input-current hardware limit target no more than 1.5A; set charge current in BQ25887 firmware/registers between 500mA and 1.5A. | https://www.digikey.com/en/products/result?keywords=0603+resistor+1%25
2S charger | R4 | TBD 1% | Resistor_SMD:R_0603_1608Metric | CBSET,GND | Cell-balance setting resistor; choose from BQ25887 datasheet. | https://www.digikey.com/en/products/result?keywords=0603+resistor+1%25
2S charger | C3 | 22uF 16V X5R | Capacitor_SMD:C_0805_2012Metric | GND,PMID | PMID bulk capacitor. | https://www.digikey.com/en/products/result
2S charger | C4 | 100nF 16V X7R | Capacitor_SMD:C_0603_1608Metric | GND,PMID | PMID HF bypass. | https://www.digikey.com/en/products/result
2S charger | C5 | 22uF 16V X5R | Capacitor_SMD:C_0805_2012Metric | BAT_SYS,GND | 2S charger BAT bulk capacitor on protected/system-side pack positive. | https://www.digikey.com/en/products/result
2S charger | C6 | 4.7uF 6.3V X5R | Capacitor_SMD:C_0603_1608Metric | GND,REGN | REGN regulator capacitor. | https://www.digikey.com/en/products/result
2S charger | C7 | 100nF 16V X7R | Capacitor_SMD:C_0603_1608Metric | BTST,CHG_SW | Bootstrap capacitor. | https://www.digikey.com/en/products/result
2S charger | C8 | 100nF 10V X7R | Capacitor_SMD:C_0603_1608Metric | CBSET,GND | CBSET filter placeholder; verify final requirement. | https://www.digikey.com/en/products/result
2S charger | C9 | 100nF 16V X7R | Capacitor_SMD:C_0603_1608Metric | BATT_RAW_P,CELL_MID | Upper-cell raw-pack sense bypass; place close to charger/protection sense pins. | https://www.digikey.com/en/products/result
2S charger | C10 | 100nF 16V X7R | Capacitor_SMD:C_0603_1608Metric | BATT_RAW_N,CELL_MID | Lower-cell raw-pack sense bypass; place close to charger/protection sense pins. | https://www.digikey.com/en/products/result
2S charger | TH1 | 10k NTC | Resistor_SMD:R_0603_1608Metric | GND,TS | 0603 NTC; place against or near the selected pack/cells. | https://www.digikey.com/en/products/result?keywords=10k+NTC+0603+NTC+thermistor
2S charger | R5 | 10k 1% | Resistor_SMD:R_0603_1608Metric | REGN,TS | TS bias; verify with selected NTC curve and BQ25887 TS thresholds. | https://www.digikey.com/en/products/result
2S charger | R6 | 2.2k | Resistor_SMD:R_0603_1608Metric | LED_CHG_A,REGN | Charge-status LED resistor. | https://www.digikey.com/en/products/result?keywords=2.2k+Resistor_SMD%3AR_0603_1608Metric+resistor
2S charger | D2 | LED green | LED_SMD:LED_0603_1608Metric | CHG_STAT,LED_CHG_A | STAT open-drain LED. KiCad LED_0603_1608Metric pad 1 is the CATHODE, so the anode net must land on pad 2. | https://www.digikey.com/en/products/result?keywords=LED+green+0603+LED
2S charger | R7 | 2.2k | Resistor_SMD:R_0603_1608Metric | LED_PGOOD_A,REGN | Power-good LED resistor. | https://www.digikey.com/en/products/result?keywords=2.2k+Resistor_SMD%3AR_0603_1608Metric+resistor
2S charger | D3 | LED blue | LED_SMD:LED_0603_1608Metric | LED_PGOOD_A,PG_STAT | PG open-drain LED. KiCad LED_0603_1608Metric pad 1 is the CATHODE, so the anode net must land on pad 2. | https://www.digikey.com/en/products/result?keywords=LED+blue+0603+LED
Battery | BT1 | 18650 Cell 1 lower |  | BATT_RAW_N,CELL1_P | Lower series cell holder: negative to raw pack negative, positive through F2 to CELL_MID. | https://www.digikey.com/en/products/result?keywords=18650+battery+holder+single+cell+PCB
Battery | BT2 | 18650 Cell 2 upper |  | CELL2_P,CELL_MID | Upper series cell holder: negative to CELL_MID, positive through F3 to BATT_RAW_P. | https://www.digikey.com/en/products/result?keywords=18650+battery+holder+single+cell+PCB
Battery | F2 | PTC/fuse cell1 | Fuse:Fuse_1206_3216Metric | CELL1_P,CELL_MID | SMD cell fuse/PTC; place close to lower cell positive. | https://www.digikey.com/en/products/result?keywords=PTC%2Ffuse+cell1+resettable+fuse+PTC+SMD
Battery | F3 | PTC/fuse cell2 | Fuse:Fuse_1206_3216Metric | BATT_RAW_P,CELL2_P | SMD cell fuse/PTC; place close to upper cell positive. | https://www.digikey.com/en/products/result?keywords=PTC%2Ffuse+cell2+resettable+fuse+PTC+SMD
Battery | J7 | 2S balance input JST-XH side-entry | Connector_JST:JST_XH_S3B-XH-A_1x03_P2.50mm_Horizontal | BATT_RAW_N,BATT_RAW_P,CELL_MID | REAR-edge side-entry 2S balance connector pinout: B-, cell midpoint, B+. Pin 3 is raw cell-stack positive before high-side protection FETs. r17: moved from the front edge to the rear edge and rotated 180 deg; the physical flip reverses pin order along X and corrects the r16 reversed-polarity fault. Netlist pin assignment is deliberately UNCHANGED - do not also swap pin 1/pin 3 nets or the fault returns. | https://www.digikey.com/en/products/result?keywords=JST+XH+3+pin+horizontal+S3B-XH-A
2S protection | U2 | BQ28Z610DRZR-R1 | Daughterboard:BQ28Z610_DRZ0012A_12SON_2.5x4mm_P0.5mm | BATT_RAW_N,BQ_CHG,BQ_DSG,BQ_PACK,BQ_PBI,BQ_SRN,BQ_SRP,I2C_SCL,I2C_SDA,PROT_VC,PROT_VDD,TS | TI 1S/2S gas gauge and primary protection controller wired for the high-side N-FET topology from the BQ28Z610 reference design. | https://www.digikey.com/en/products/detail/texas-instruments/BQ28Z610DRZR-R1/11625468
2S protection | R14 | 470R 1% | Resistor_SMD:R_0603_1608Metric | BATT_RAW_P,PROT_VDD | BQ28Z610 VC2 input resistor; place near U2 and verify with cell-balance routing. | https://www.digikey.com/en/products/result
2S protection | R15 | 470R 1% | Resistor_SMD:R_0603_1608Metric | CELL_MID,PROT_VC | BQ28Z610 VC1 input resistor; place near U2 and verify with cell-balance routing. | https://www.digikey.com/en/products/result
2S protection | C25 | 100nF 16V X7R | Capacitor_SMD:C_0603_1608Metric | PROT_VC,PROT_VDD | BQ28Z610 upper-cell sense filter capacitor. | https://www.digikey.com/en/products/result
2S protection | C26 | 100nF 16V X7R | Capacitor_SMD:C_0603_1608Metric | BATT_RAW_N,PROT_VC | BQ28Z610 lower-cell sense filter capacitor. | https://www.digikey.com/en/products/result
2S protection | R16 | 100R | Resistor_SMD:R_0603_1608Metric | BAT_SYS,BQ_PACK | BQ28Z610 PACK input series resistor from protected/system-side pack positive. | https://www.digikey.com/en/products/result?keywords=100R+Resistor_SMD%3AR_0603_1608Metric+resistor
2S protection | C30 | 2.2uF 10V X5R | Capacitor_SMD:C_0603_1608Metric | BATT_RAW_N,BQ_PBI | BQ28Z610 PBI hold-up capacitor; place close to U2. | https://www.digikey.com/en/products/result
2S protection | R46 | 2mR 1% 50ppm | Resistor_SMD:R_1206_3216Metric | BATT_RAW_N,GND | BQ28Z610 series current-sense resistor in the pack-negative return path; Kelvin route both ends. | https://www.digikey.com/en/products/result
2S protection | R47 | 100R | Resistor_SMD:R_0603_1608Metric | BQ_SRN,GND | BQ28Z610 SRN input filter resistor; Kelvin route from system/pack-negative side of R46. | https://www.digikey.com/en/products/result?keywords=100R+Resistor_SMD%3AR_0603_1608Metric+resistor
2S protection | R48 | 100R | Resistor_SMD:R_0603_1608Metric | BATT_RAW_N,BQ_SRP | BQ28Z610 SRP input filter resistor; Kelvin route from raw-cell-negative side of R46. | https://www.digikey.com/en/products/result?keywords=100R+Resistor_SMD%3AR_0603_1608Metric+resistor
2S protection | C31 | 100nF 16V X7R | Capacitor_SMD:C_0603_1608Metric | BQ_SRN,BQ_SRP | BQ28Z610 differential SRN/SRP filter capacitor; place close to U2. | https://www.digikey.com/en/products/result
2S protection | R21 | 100R | Resistor_SMD:R_0603_1608Metric | BQ_DSG,DO_GATE | Small series gate resistor for BQ28Z610 discharge FET control. | https://www.digikey.com/en/products/result?keywords=100R+Resistor_SMD%3AR_0603_1608Metric+resistor
2S protection | R22 | 100R | Resistor_SMD:R_0603_1608Metric | BQ_CHG,CO_GATE | Small series gate resistor for BQ28Z610 charge FET control. | https://www.digikey.com/en/products/result?keywords=100R+Resistor_SMD%3AR_0603_1608Metric+resistor
2S protection | Q1 | CSD18502Q5B charge FET | Daughterboard:CSD18502Q5B_DNK0008A_VSON-CLIP_5x6mm | CO_GATE,FET_BATT_P,FET_MID_COMMON | High-side charge-blocking N-FET; source faces the raw cell stack because CHG-off discharges the gate to VC2, drain joins the common mid node. | https://jlcpcb.com/partdetail/TexasInstruments-CSD18502Q5B/C473915
2S protection | Q2 | CSD18502Q5B discharge FET | Daughterboard:CSD18502Q5B_DNK0008A_VSON-CLIP_5x6mm | BAT_SYS,DO_GATE,FET_MID_COMMON | High-side discharge-blocking N-FET; source faces the protected system node because DSG-off discharges the gate to PACK, drain joins the common mid node. | https://jlcpcb.com/partdetail/TexasInstruments-CSD18502Q5B/C473915
2S protection | R50 | 10M | Resistor_SMD:R_0603_1608Metric | CO_GATE,FET_BATT_P | Gate-source bleed for the high-side charge FET; returns to that FET's own source (raw cell stack). | https://www.digikey.com/en/products/result?keywords=10M+Resistor_SMD%3AR_0603_1608Metric+resistor
2S protection | R49 | 10M | Resistor_SMD:R_0603_1608Metric | BAT_SYS,DO_GATE | Gate-source bleed for the high-side discharge FET; returns to that FET's own source (protected system node). | https://www.digikey.com/en/products/result?keywords=10M+Resistor_SMD%3AR_0603_1608Metric+resistor
2S protection | C32 | 100nF 25V X7R | Capacitor_SMD:C_0603_1608Metric | FET_BATT_P,FET_MID_COMMON | ESD/transient capacitor across charge FET per BQ28Z610 layout guidance. | https://www.digikey.com/en/products/result
2S protection | C33 | 100nF 25V X7R | Capacitor_SMD:C_0603_1608Metric | BAT_SYS,FET_MID_COMMON | ESD/transient capacitor across discharge FET per BQ28Z610 layout guidance. | https://www.digikey.com/en/products/result
Battery | F4 | 2A battery path fuse | Fuse:Fuse_1206_3216Metric | BATT_RAW_P,FET_BATT_P | SMD high-side pack fuse between protection FETs and raw cell-stack positive. | https://www.digikey.com/en/products/result?keywords=2A+battery+path+fuse+resettable+fuse+PTC+SMD
5V buck | U3 | AP63200WU 5V Buck | Package_TO_SOT_SMD:TSOT-23-6 | BAT_SYS,BST_5V,EN_5V,FB_5V,GND,SW_5V | 2S-to-5V buck regulator; 5V / 1A target. | https://www.digikey.com/en/products/result?keywords=AP63200WU
5V buck | L1 | 4.7uH >=3A sat | Inductor_SMD:L_APV_ANR4020 | +5V,SW_5V | Low-DCR shielded SMD inductor. | https://www.digikey.com/en/products/result?keywords=4.7uH+%3E%3D3A+sat+shielded+inductor+SMD
5V buck | C11 | 10uF 16V X5R | Capacitor_SMD:C_0805_2012Metric | BAT_SYS,GND | Input bulk. | https://www.digikey.com/en/products/result
5V buck | C12 | 100nF 16V X7R | Capacitor_SMD:C_0603_1608Metric | BAT_SYS,GND | Input bypass. | https://www.digikey.com/en/products/result
5V buck | C13 | 22uF 10V X5R | Capacitor_SMD:C_0805_2012Metric | +5V,GND | Output bulk. | https://www.digikey.com/en/products/result
5V buck | C14 | 22uF 10V X5R | Capacitor_SMD:C_0805_2012Metric | +5V,GND | Output bulk. | https://www.digikey.com/en/products/result
5V buck | C15 | 100nF 16V X7R | Capacitor_SMD:C_0603_1608Metric | BST_5V,SW_5V | Bootstrap capacitor. | https://www.digikey.com/en/products/result
5V buck | R8 | 523k 1% | Resistor_SMD:R_0603_1608Metric | +5V,FB_5V | Feedback top for 5V from 0.8V reference. | https://www.digikey.com/en/products/result
5V buck | R9 | 100k 1% | Resistor_SMD:R_0603_1608Metric | FB_5V,GND | Feedback bottom. | https://www.digikey.com/en/products/result
5V buck | R10 | 100k | Resistor_SMD:R_0603_1608Metric | BAT_SYS,EN_5V | Default 5V buck enabled when pack is present. | https://www.digikey.com/en/products/result?keywords=100k+Resistor_SMD%3AR_0603_1608Metric+resistor
3V3 buck | U4 | AP63200WU 3V3 Buck | Package_TO_SOT_SMD:TSOT-23-6 | BAT_SYS,BST_3V3,EN_3V3,FB_3V3,GND,SW_3V3 | 2S-to-3.3V buck regulator; 3.3V / 500mA target. | https://www.digikey.com/en/products/result?keywords=AP63200WU
3V3 buck | L2 | 4.7uH >=2A sat | Inductor_SMD:L_APV_ANR4020 | +3V3,SW_3V3 | Low-DCR shielded SMD inductor. | https://www.digikey.com/en/products/result?keywords=4.7uH+%3E%3D2A+sat+shielded+inductor+SMD
3V3 buck | C16 | 10uF 16V X5R | Capacitor_SMD:C_0805_2012Metric | BAT_SYS,GND | Input bulk. | https://www.digikey.com/en/products/result
3V3 buck | C21 | 100nF 16V X7R | Capacitor_SMD:C_0603_1608Metric | BAT_SYS,GND | Input bypass. | https://www.digikey.com/en/products/result
3V3 buck | C22 | 22uF 10V X5R | Capacitor_SMD:C_0805_2012Metric | +3V3,GND | Output cap. | https://www.digikey.com/en/products/result
3V3 buck | C23 | 22uF 10V X5R | Capacitor_SMD:C_0805_2012Metric | +3V3,GND | Output cap. | https://www.digikey.com/en/products/result
3V3 buck | C24 | 100nF 16V X7R | Capacitor_SMD:C_0603_1608Metric | BST_3V3,SW_3V3 | Bootstrap capacitor. | https://www.digikey.com/en/products/result
3V3 buck | R11 | 316k 1% | Resistor_SMD:R_0603_1608Metric | +3V3,FB_3V3 | Feedback top for 3.3V from 0.8V reference. | https://www.digikey.com/en/products/result
3V3 buck | R12 | 100k 1% | Resistor_SMD:R_0603_1608Metric | FB_3V3,GND | Feedback bottom. | https://www.digikey.com/en/products/result
3V3 buck | R13 | 100k | Resistor_SMD:R_0603_1608Metric | BAT_SYS,EN_3V3 | Default 3.3V buck enabled when pack is present. | https://www.digikey.com/en/products/result?keywords=100k+Resistor_SMD%3AR_0603_1608Metric+resistor
Output switching | SW1 | Pololu #2808 5V switch | Daughterboard:Pololu_2808_Raised_Header | +5V,+5V_SW,CTRL_5V_SW,GND | VIN=+5V, VOUT=+5V_SW. | https://www.pololu.com/product/2808
Output switching | SW2 | Pololu #2808 3V3 switch | Daughterboard:Pololu_2808_Raised_Header | +3V3,+3V3_SW,CTRL_3V3_SW,GND | VIN=+3V3, VOUT=+3V3_SW. | https://www.pololu.com/product/2808
Output switching | R17 | 330R | Resistor_SMD:R_0603_1608Metric | CTRL_5V_SW,GPIO2 | Series resistor from ESP32 GPIO2. | https://www.digikey.com/en/products/result?keywords=330R+Resistor_SMD%3AR_0603_1608Metric+resistor
Output switching | R18 | 330R | Resistor_SMD:R_0603_1608Metric | CTRL_3V3_SW,GPIO3 | Series resistor from ESP32 GPIO3. | https://www.digikey.com/en/products/result?keywords=330R+Resistor_SMD%3AR_0603_1608Metric+resistor
Control | J30 | J3P Hosyond +5V_SW solder pad | TestPoint:TestPoint_Pad_1.5x1.5mm | +5V_SW | Individual solder-wire pad for wire from Hosyond ESP32-S3 board.
Control | J31 | J3A Hosyond UART_TX solder pad | TestPoint:TestPoint_Pad_1.5x1.5mm | UART_TX | Individual solder-wire pad for wire from Hosyond ESP32-S3 board.
Control | J32 | J3B Hosyond UART_RX solder pad | TestPoint:TestPoint_Pad_1.5x1.5mm | UART_RX | Individual solder-wire pad for wire from Hosyond ESP32-S3 board.
Control | J33 | J3C Hosyond I2C_SDA solder pad | TestPoint:TestPoint_Pad_1.5x1.5mm | I2C_SDA | Individual solder-wire pad for wire from Hosyond ESP32-S3 board.
Control | J34 | J3D Hosyond I2C_SCL solder pad | TestPoint:TestPoint_Pad_1.5x1.5mm | I2C_SCL | Individual solder-wire pad for wire from Hosyond ESP32-S3 board.
Control | J35 | J3E Hosyond GPIO2 solder pad | TestPoint:TestPoint_Pad_1.5x1.5mm | GPIO2 | Individual solder-wire pad for wire from Hosyond ESP32-S3 board.
Control | J36 | J3F Hosyond GPIO3 solder pad | TestPoint:TestPoint_Pad_1.5x1.5mm | GPIO3 | Individual solder-wire pad for wire from Hosyond ESP32-S3 board.
Control | J37 | J3G Hosyond GPIO14 solder pad | TestPoint:TestPoint_Pad_1.5x1.5mm | GPIO14 | Individual solder-wire pad for wire from Hosyond ESP32-S3 board.
Control | J38 | J3H Hosyond GPIO21 solder pad | TestPoint:TestPoint_Pad_1.5x1.5mm | GPIO21 | Individual solder-wire pad for wire from Hosyond ESP32-S3 board.
Control | J39 | J3I Hosyond GND solder pad | TestPoint:TestPoint_Pad_1.5x1.5mm | GND | Individual solder-wire pad for wire from Hosyond ESP32-S3 board.
Outputs | J2 | Switched power outputs |  | +3V3_SW,+5V_SW,GND | External switched-load connector. | https://www.digikey.com/en/products/result?keywords=2.54mm+pin+header+vertical+3+position
Signals | J4 | UART JST-GH 1.25mm | Connector_JST:JST_GH_SM05B-GHS-TB_1x05-1MP_P1.25mm_Horizontal | +5V_SW,GND,UART_RX,UART_TX | 5-pin 1.25mm JST UART header: +5V_SW,GND,TX,RX,GND. | https://www.digikey.com/en/products/result?keywords=SM05B-GHS-TB+JST+GH+5+position
Signals | J5 | I2C male header 2.54mm | Connector_PinHeader_2.54mm:PinHeader_1x04_P2.54mm_Vertical | +3V3_SW,GND,I2C_SCL,I2C_SDA | 4-pin 2.54mm I2C header: +3V3_SW,GND,SDA,SCL. | https://www.digikey.com/en/products/result?keywords=2.54mm+pin+header+vertical+4+position
Signals | J6 | Deep sleep pushbutton header | Connector_PinHeader_2.54mm:PinHeader_1x02_P2.54mm_Vertical | GPIO14,GPIO21 | 2-pin 2.54mm header for pushbutton between GPIO14 and GPIO21. | https://www.digikey.com/en/products/result?keywords=2.54mm+pin+header+vertical+2+position
Analog inputs | U5 | ADS1115IDGS 0x48 | Package_SO:TSSOP-10_3x3mm_P0.5mm | +3V3_SW_LOGIC,AIN0,AIN1,AIN2,AIN3,GND,I2C_SCL,I2C_SDA | First 4-channel ADS1115; ADDR=GND for I2C address 0x48. | https://www.digikey.com/en/products/result?keywords=ADS1115IDGS
Analog inputs | U6 | ADS1115IDGS 0x49 | Package_SO:TSSOP-10_3x3mm_P0.5mm | +3V3_SW_LOGIC,AIN4,AIN5,AIN6,AIN7,GND,I2C_SCL,I2C_SDA | Second 4-channel ADS1115; ADDR=VDD for I2C address 0x49. | https://www.digikey.com/en/products/result?keywords=ADS1115IDGS
Analog inputs | R19 | 4.7k | Resistor_SMD:R_0603_1608Metric | +3V3_SW_LOGIC,I2C_SDA | Local I2C SDA pullup for switched onboard ADCs. | https://www.digikey.com/en/products/result?keywords=4.7k+Resistor_SMD%3AR_0603_1608Metric+resistor
Analog inputs | R20 | 4.7k | Resistor_SMD:R_0603_1608Metric | +3V3_SW_LOGIC,I2C_SCL | Local I2C SCL pullup for switched onboard ADCs. | https://www.digikey.com/en/products/result?keywords=4.7k+Resistor_SMD%3AR_0603_1608Metric+resistor
Analog inputs | C17 | 100nF 10V X7R | Capacitor_SMD:C_0603_1608Metric | +3V3_SW_LOGIC,GND | U5 local VDD bypass. | https://www.digikey.com/en/products/result
Analog inputs | C18 | 1uF 10V X5R | Capacitor_SMD:C_0603_1608Metric | +3V3_SW_LOGIC,GND | U5 local supply bulk. | https://www.digikey.com/en/products/result
Analog inputs | C19 | 100nF 10V X7R | Capacitor_SMD:C_0603_1608Metric | +3V3_SW_LOGIC,GND | U6 local VDD bypass. | https://www.digikey.com/en/products/result
Analog inputs | C20 | 1uF 10V X5R | Capacitor_SMD:C_0603_1608Metric | +3V3_SW_LOGIC,GND | U6 local supply bulk. | https://www.digikey.com/en/products/result
Analog inputs | J8 | Left gimbal A JST-GH 1.25mm | Connector_JST:JST_GH_BM03B-GHS-TBT_1x03-1MP_P1.25mm_Vertical | +3V3_SW,AIN0,GND | 3-pin gimbal potentiometer input: GND,AIN0,+3V3_SW. | https://www.digikey.com/en/products/result?keywords=2.54mm+pin+header+vertical+10+position
Analog inputs | J40 | Left gimbal B JST-GH 1.25mm | Connector_JST:JST_GH_BM03B-GHS-TBT_1x03-1MP_P1.25mm_Vertical | +3V3_SW,AIN1,GND | 3-pin gimbal potentiometer input: GND,AIN1,+3V3_SW. | https://www.digikey.com/en/products/result
Analog inputs | J41 | Right gimbal A JST-GH 1.25mm | Connector_JST:JST_GH_BM03B-GHS-TBT_1x03-1MP_P1.25mm_Vertical | +3V3_SW,AIN2,GND | 3-pin gimbal potentiometer input: GND,AIN2,+3V3_SW. | https://www.digikey.com/en/products/result
Analog inputs | J42 | Right gimbal B JST-GH 1.25mm | Connector_JST:JST_GH_BM03B-GHS-TBT_1x03-1MP_P1.25mm_Vertical | +3V3_SW,AIN3,GND | 3-pin gimbal potentiometer input: GND,AIN3,+3V3_SW. | https://www.digikey.com/en/products/result
Analog inputs | R45 | 0R | Resistor_SMD:R_0603_1608Metric | +3V3_SW,+3V3_SW_LOGIC | Net-tie jumper: heavy switched 3.3V rail to light local ADC/MCP logic branch. | https://www.digikey.com/en/products/result?keywords=0R+Resistor_SMD%3AR_0603_1608Metric+resistor
GPIO expander | U7 | MCP23017-E/SO | Daughterboard:SOIC-28W_7.5x17.9mm_P1.27mm_NoPads11_14 | +3V3_SW_LOGIC,GND,I2C_SCL,I2C_SDA,MCP_A0,MCP_A1,MCP_A2,MCP_GPA0,MCP_GPA1,MCP_GPA2,MCP_GPA3,MCP_GPA4,MCP_GPA5,MCP_GPA6,MCP_GPA7,MCP_GPB0,MCP_GPB1,MCP_GPB2,MCP_GPB3,MCP_GPB4,MCP_GPB5,MCP_GPB6,MCP_GPB7,MCP_INTA,MCP_INTB,MCP_RESET | 16-bit I2C GPIO expander at address 0x20; powered from the light +3V3_SW_LOGIC branch. Treat GPA7/GPB7 as output-only unless the selected MCP23017 variant is verified. | https://www.digikey.com/en/products/result?keywords=MCP23017-E%2FSO
GPIO expander | C27 | 100nF 10V X7R | Capacitor_SMD:C_0603_1608Metric | +3V3_SW_LOGIC,GND | MCP23017 local VDD bypass, place close to U7. | https://www.digikey.com/en/products/result
GPIO expander | C28 | 1uF 10V X5R | Capacitor_SMD:C_0603_1608Metric | +3V3_SW_LOGIC,GND | MCP23017 local supply bulk. | https://www.digikey.com/en/products/result
GPIO expander | R39 | 0R | Resistor_SMD:R_0603_1608Metric | GND,MCP_A0 | Default address strap low; A2:A0=000 gives I2C address 0x20. | https://www.digikey.com/en/products/result?keywords=0R+Resistor_SMD%3AR_0603_1608Metric+resistor
GPIO expander | R40 | 0R | Resistor_SMD:R_0603_1608Metric | GND,MCP_A1 | Default address strap low. | https://www.digikey.com/en/products/result?keywords=0R+Resistor_SMD%3AR_0603_1608Metric+resistor
GPIO expander | R41 | 0R | Resistor_SMD:R_0603_1608Metric | GND,MCP_A2 | Default address strap low. | https://www.digikey.com/en/products/result?keywords=0R+Resistor_SMD%3AR_0603_1608Metric+resistor
GPIO expander | R42 | 10k | Resistor_SMD:R_0603_1608Metric | +3V3_SW_LOGIC,MCP_RESET | Reset pullup to switched 3.3V logic branch. | https://www.digikey.com/en/products/result?keywords=10k+Resistor_SMD%3AR_0603_1608Metric+resistor
GPIO expander | C29 | 100nF 10V X7R | Capacitor_SMD:C_0603_1608Metric | GND,MCP_RESET | Optional reset delay/noise filter; omit if firmware needs immediate reset release. | https://www.digikey.com/en/products/result
GPIO expander | R43 | 10k | Resistor_SMD:R_0603_1608Metric | +3V3_SW_LOGIC,MCP_INTA | INTA pullup; also available on a solder pad. | https://www.digikey.com/en/products/result?keywords=10k+Resistor_SMD%3AR_0603_1608Metric+resistor
GPIO expander | R44 | 10k | Resistor_SMD:R_0603_1608Metric | +3V3_SW_LOGIC,MCP_INTB | INTB pullup; also available on a solder pad. | https://www.digikey.com/en/products/result?keywords=10k+Resistor_SMD%3AR_0603_1608Metric+resistor
GPIO expander | R23 | 100R | Resistor_SMD:R_0603_1608Metric | EXP_GPA0,MCP_GPA0 | Series resistor between MCP23017 GPIO and external solder pad. | https://www.digikey.com/en/products/result?keywords=100R+Resistor_SMD%3AR_0603_1608Metric+resistor
GPIO expander | R24 | 100R | Resistor_SMD:R_0603_1608Metric | EXP_GPA1,MCP_GPA1 | Series resistor between MCP23017 GPIO and external solder pad. | https://www.digikey.com/en/products/result?keywords=100R+Resistor_SMD%3AR_0603_1608Metric+resistor
GPIO expander | R25 | 100R | Resistor_SMD:R_0603_1608Metric | EXP_GPA2,MCP_GPA2 | Series resistor between MCP23017 GPIO and external solder pad. | https://www.digikey.com/en/products/result?keywords=100R+Resistor_SMD%3AR_0603_1608Metric+resistor
GPIO expander | R26 | 100R | Resistor_SMD:R_0603_1608Metric | EXP_GPA3,MCP_GPA3 | Series resistor between MCP23017 GPIO and external solder pad. | https://www.digikey.com/en/products/result?keywords=100R+Resistor_SMD%3AR_0603_1608Metric+resistor
GPIO expander | R27 | 100R | Resistor_SMD:R_0603_1608Metric | EXP_GPA4,MCP_GPA4 | Series resistor between MCP23017 GPIO and external solder pad. | https://www.digikey.com/en/products/result?keywords=100R+Resistor_SMD%3AR_0603_1608Metric+resistor
GPIO expander | R28 | 100R | Resistor_SMD:R_0603_1608Metric | EXP_GPA5,MCP_GPA5 | Series resistor between MCP23017 GPIO and external solder pad. | https://www.digikey.com/en/products/result?keywords=100R+Resistor_SMD%3AR_0603_1608Metric+resistor
GPIO expander | R29 | 100R | Resistor_SMD:R_0603_1608Metric | EXP_GPA6,MCP_GPA6 | Series resistor between MCP23017 GPIO and external solder pad. | https://www.digikey.com/en/products/result?keywords=100R+Resistor_SMD%3AR_0603_1608Metric+resistor
GPIO expander | R30 | 100R | Resistor_SMD:R_0603_1608Metric | EXP_GPA7,MCP_GPA7 | Series resistor between MCP23017 GPIO and external solder pad. | https://www.digikey.com/en/products/result?keywords=100R+Resistor_SMD%3AR_0603_1608Metric+resistor
GPIO expander | R31 | 100R | Resistor_SMD:R_0603_1608Metric | EXP_GPB0,MCP_GPB0 | Series resistor between MCP23017 GPIO and external solder pad. | https://www.digikey.com/en/products/result?keywords=100R+Resistor_SMD%3AR_0603_1608Metric+resistor
GPIO expander | R32 | 100R | Resistor_SMD:R_0603_1608Metric | EXP_GPB1,MCP_GPB1 | Series resistor between MCP23017 GPIO and external solder pad. | https://www.digikey.com/en/products/result?keywords=100R+Resistor_SMD%3AR_0603_1608Metric+resistor
GPIO expander | R33 | 100R | Resistor_SMD:R_0603_1608Metric | EXP_GPB2,MCP_GPB2 | Series resistor between MCP23017 GPIO and external solder pad. | https://www.digikey.com/en/products/result?keywords=100R+Resistor_SMD%3AR_0603_1608Metric+resistor
GPIO expander | R34 | 100R | Resistor_SMD:R_0603_1608Metric | EXP_GPB3,MCP_GPB3 | Series resistor between MCP23017 GPIO and external solder pad. | https://www.digikey.com/en/products/result?keywords=100R+Resistor_SMD%3AR_0603_1608Metric+resistor
GPIO expander | R35 | 100R | Resistor_SMD:R_0603_1608Metric | EXP_GPB4,MCP_GPB4 | Series resistor between MCP23017 GPIO and external solder pad. | https://www.digikey.com/en/products/result?keywords=100R+Resistor_SMD%3AR_0603_1608Metric+resistor
GPIO expander | R36 | 100R | Resistor_SMD:R_0603_1608Metric | EXP_GPB5,MCP_GPB5 | Series resistor between MCP23017 GPIO and external solder pad. | https://www.digikey.com/en/products/result?keywords=100R+Resistor_SMD%3AR_0603_1608Metric+resistor
GPIO expander | R37 | 100R | Resistor_SMD:R_0603_1608Metric | EXP_GPB6,MCP_GPB6 | Series resistor between MCP23017 GPIO and external solder pad. | https://www.digikey.com/en/products/result?keywords=100R+Resistor_SMD%3AR_0603_1608Metric+resistor
GPIO expander | R38 | 100R | Resistor_SMD:R_0603_1608Metric | EXP_GPB7,MCP_GPB7 | Series resistor between MCP23017 GPIO and external solder pad. | https://www.digikey.com/en/products/result?keywords=100R+Resistor_SMD%3AR_0603_1608Metric+resistor
GPIO expander | D4 | 4ch 3.3V GPIO TVS array TBD | Daughterboard:SOT-23-6_NoPad6 | EXP_GPA0,EXP_GPA1,EXP_GPA2,EXP_GPA3,GND | ESD protection placeholder for four exposed MCP23017 solder-pad lines; choose exact low-cap 3.3V array before layout. | https://www.digikey.com/en/products/result?keywords=4+channel+3.3V+ESD+TVS+array+SOT-23-6
GPIO expander | D5 | 4ch 3.3V GPIO TVS array TBD | Daughterboard:SOT-23-6_NoPad6 | EXP_GPA4,EXP_GPA5,EXP_GPA6,EXP_GPA7,GND | ESD protection placeholder for four exposed MCP23017 solder-pad lines; choose exact low-cap 3.3V array before layout. | https://www.digikey.com/en/products/result?keywords=4+channel+3.3V+ESD+TVS+array+SOT-23-6
GPIO expander | D6 | 4ch 3.3V GPIO TVS array TBD | Daughterboard:SOT-23-6_NoPad6 | EXP_GPB0,EXP_GPB1,EXP_GPB2,EXP_GPB3,GND | ESD protection placeholder for four exposed MCP23017 solder-pad lines; choose exact low-cap 3.3V array before layout. | https://www.digikey.com/en/products/result?keywords=4+channel+3.3V+ESD+TVS+array+SOT-23-6
GPIO expander | D7 | 4ch 3.3V GPIO TVS array TBD | Daughterboard:SOT-23-6_NoPad6 | EXP_GPB4,EXP_GPB5,EXP_GPB6,EXP_GPB7,GND | ESD protection placeholder for four exposed MCP23017 solder-pad lines; choose exact low-cap 3.3V array before layout. | https://www.digikey.com/en/products/result?keywords=4+channel+3.3V+ESD+TVS+array+SOT-23-6
GPIO expander | J91 | MCP23017 GPA0 solder pad | TestPoint:TestPoint_Pad_1.5x1.5mm | EXP_GPA0 | Individual solder-wire pad for MCP23017 GPIO/utility breakout.
GPIO expander | J92 | MCP23017 GPA1 solder pad | TestPoint:TestPoint_Pad_1.5x1.5mm | EXP_GPA1 | Individual solder-wire pad for MCP23017 GPIO/utility breakout.
GPIO expander | J93 | MCP23017 GPA2 solder pad | TestPoint:TestPoint_Pad_1.5x1.5mm | EXP_GPA2 | Individual solder-wire pad for MCP23017 GPIO/utility breakout.
GPIO expander | J94 | MCP23017 GPA3 solder pad | TestPoint:TestPoint_Pad_1.5x1.5mm | EXP_GPA3 | Individual solder-wire pad for MCP23017 GPIO/utility breakout.
GPIO expander | J95 | MCP23017 GPA4 solder pad | TestPoint:TestPoint_Pad_1.5x1.5mm | EXP_GPA4 | Individual solder-wire pad for MCP23017 GPIO/utility breakout.
GPIO expander | J96 | MCP23017 GPA5 solder pad | TestPoint:TestPoint_Pad_1.5x1.5mm | EXP_GPA5 | Individual solder-wire pad for MCP23017 GPIO/utility breakout.
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

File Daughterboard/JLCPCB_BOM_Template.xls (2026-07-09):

Comment | Designator | Footprint | JLCPCB Part#(optional)
100uF | C1 | CASE-B_3528 | C16133
100nF | C2, C9, C10 | 0603 | C14663
300KΩ | R4, R7 | 0603 | C23024
15KΩ | R5, R6 | 0603_R | C22809
100KΩ | R1, R3 | 0603_R | C25803
10uF | C3-5 | 1206_C | C13585
100Ω | R2 | 0603_R | C22775
1N4148WS | D1 | SOD-323 | C2128
LM358DR2G | U1 | SOIC-8_150mil | C7950
HT7550-1 | VR1 | SOT-89(SOT-89-3) | C16106

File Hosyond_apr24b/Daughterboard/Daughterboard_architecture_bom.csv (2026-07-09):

Refs | Value | Footprint | Qty | DNP
A1 | Fuse + VBUS TVS + CIN |  | 1
A2 | BQ2970 + dual NFET |  | 1
BT1 | 2x 18650 1S2P |  | 1
J1 | USB-C 5V Sink |  | 1
J2 | Power outputs |  | 1
J3 | Hosyond ESP32-S3 GPIO |  | 1
SW1 | Pololu #2808 5V switch |  | 1
SW2 | Pololu #2808 3V3 switch |  | 1
U1 | BQ24074RGT |  | 1
U3 | TPS61023 5V |  | 1
U4 | TPS63031 3V3 |  | 1

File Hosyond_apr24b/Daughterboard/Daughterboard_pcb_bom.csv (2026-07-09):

Refs | Value | Footprint | Qty | Description | Datasheet | Purchase Link | DNP
BT1 | 18650 Cell 1 lower |  | 1 |  |  | https://www.digikey.com/en/products/result?keywords=18650+battery+holder+single+cell+PCB
BT2 | 18650 Cell 2 upper |  | 1 |  |  | https://www.digikey.com/en/products/result?keywords=18650+battery+holder+single+cell+PCB
C1 | 10uF 10V X5R | Capacitor_SMD:C_0805_2012Metric | 1 |  |  | https://www.digikey.com/en/products/result
C2,C19,C27,C29 | 100nF 10V X7R | Capacitor_SMD:C_0603_1608Metric | 4 |  |  | https://www.digikey.com/en/products/result
C3,C5 | 22uF 16V X5R | Capacitor_SMD:C_0805_2012Metric | 2 |  |  | https://www.digikey.com/en/products/result
C4,C7,C9,C10,C12,C15,C21,C24-C26 | 100nF 16V X7R | Capacitor_SMD:C_0603_1608Metric | 10 |  |  | https://www.digikey.com/en/products/result
C6 | 4.7uF 6.3V X5R | Capacitor_SMD:C_0603_1608Metric | 1 |  |  | https://www.digikey.com/en/products/result
C11,C16 | 10uF 16V X5R | Capacitor_SMD:C_0805_2012Metric | 2 |  |  | https://www.digikey.com/en/products/result
C13,C14,C22,C23 | 22uF 10V X5R | Capacitor_SMD:C_0805_2012Metric | 4 |  |  | https://www.digikey.com/en/products/result
C17 | 100nF 10V X7R DNP | Capacitor_SMD:C_0603_1608Metric | 1 |  |  | https://www.digikey.com/en/products/result
C18,C20,C28 | 1uF 10V X5R | Capacitor_SMD:C_0603_1608Metric | 3 |  |  | https://www.digikey.com/en/products/result
D1 | 5V VBUS TVS | Diode_SMD:D_SOD-323 | 1 |  |  | https://www.digikey.com/en/products/result?keywords=5V+VBUS+TVS+SOD-323+TVS+diode
D2 | LED green | LED_SMD:LED_0603_1608Metric | 1 |  |  | https://www.digikey.com/en/products/result?keywords=LED+green+0603+LED
D3 | LED blue | LED_SMD:LED_0603_1608Metric | 1 |  |  | https://www.digikey.com/en/products/result?keywords=LED+blue+0603+LED
D4-D7 | SP0504BAHTG 4ch GPIO TVS | Daughterboard:SOT-23-6_NoPad6 | 4 |  | https://www.littelfuse.com/products/tvs-diode-arrays/low-capacitance-esd-protection/sp05.aspx | https://www.digikey.com/en/products/result?keywords=SP0504BAHTG
F1 | 2A hold polyfuse | Fuse:Fuse_1206_3216Metric | 1 |  |  | https://www.digikey.com/en/products/result?keywords=2A+hold+polyfuse+resettable+fuse+PTC+SMD
F2 | PTC/fuse cell1 | Fuse:Fuse_1206_3216Metric | 1 |  |  | https://www.digikey.com/en/products/result?keywords=PTC%2Ffuse+cell1+resettable+fuse+PTC+SMD
F3 | PTC/fuse cell2 | Fuse:Fuse_1206_3216Metric | 1 |  |  | https://www.digikey.com/en/products/result?keywords=PTC%2Ffuse+cell2+resettable+fuse+PTC+SMD
F4 | 2A system fuse | Fuse:Fuse_1206_3216Metric | 1 |  |  | https://www.digikey.com/en/products/result?keywords=2A+system+fuse+resettable+fuse+PTC+SMD
J1 | USB-C 5V Sink | Connector_USB:USB_C_Receptacle_GCT_USB4125-xx-x_6P_TopMnt_Horizontal | 1 |  |  | https://www.digikey.com/en/products/result?keywords=GCT+USB4125+USB-C+receptacle+6+pin
J2 | Switched power outputs |  | 1 |  |  | https://www.digikey.com/en/products/result?keywords=2.54mm+pin+header+vertical+3+position
J4 | UART JST-GH 1.25mm | Connector_JST:JST_GH_SM05B-GHS-TB_1x05-1MP_P1.25mm_Horizontal | 1 |  |  | https://www.digikey.com/en/products/result?keywords=SM05B-GHS-TB+JST+GH+5+position
J5 | I2C male header 2.54mm | Connector_PinHeader_2.54mm:PinHeader_1x04_P2.54mm_Vertical | 1 |  |  | https://www.digikey.com/en/products/result?keywords=2.54mm+pin+header+vertical+4+position
J6 | Deep sleep pushbutton header | Connector_PinHeader_2.54mm:PinHeader_1x02_P2.54mm_Vertical | 1 |  |  | https://www.digikey.com/en/products/result?keywords=2.54mm+pin+header+vertical+2+position
J7 | 2S balance input JST-XH | Connector_JST:JST_XH_B3B-XH-A_1x03_P2.50mm_Vertical | 1 |  |  | https://www.digikey.com/en/products/result?keywords=JST+XH+3+pin+vertical+B3B-XH-A
J8 | Analog input header | Connector_PinHeader_2.54mm:PinHeader_1x10_P2.54mm_Vertical | 1 |  |  | https://www.digikey.com/en/products/result?keywords=2.54mm+pin+header+vertical+10+position
J30 | J3P Hosyond +5V_SW solder pad | TestPoint:TestPoint_Pad_1.5x1.5mm | 1
J31 | J3A Hosyond UART_TX solder pad | TestPoint:TestPoint_Pad_1.5x1.5mm | 1
J32 | J3B Hosyond UART_RX solder pad | TestPoint:TestPoint_Pad_1.5x1.5mm | 1
J33 | J3C Hosyond I2C_SDA solder pad | TestPoint:TestPoint_Pad_1.5x1.5mm | 1
J34 | J3D Hosyond I2C_SCL solder pad | TestPoint:TestPoint_Pad_1.5x1.5mm | 1
J35 | J3E Hosyond GPIO2 solder pad | TestPoint:TestPoint_Pad_1.5x1.5mm | 1
J36 | J3F Hosyond GPIO3 solder pad | TestPoint:TestPoint_Pad_1.5x1.5mm | 1
J37 | J3G Hosyond GPIO14 solder pad | TestPoint:TestPoint_Pad_1.5x1.5mm | 1
J38 | J3H Hosyond GPIO21 solder pad | TestPoint:TestPoint_Pad_1.5x1.5mm | 1
J39 | J3I Hosyond GND solder pad | TestPoint:TestPoint_Pad_1.5x1.5mm | 1
J91 | MCP23017 GPA0 solder pad | TestPoint:TestPoint_Pad_1.5x1.5mm | 1
J92 | MCP23017 GPA1 solder pad | TestPoint:TestPoint_Pad_1.5x1.5mm | 1
J93 | MCP23017 GPA2 solder pad | TestPoint:TestPoint_Pad_1.5x1.5mm | 1
J94 | MCP23017 GPA3 solder pad | TestPoint:TestPoint_Pad_1.5x1.5mm | 1
J95 | MCP23017 GPA4 solder pad | TestPoint:TestPoint_Pad_1.5x1.5mm | 1
J96 | MCP23017 GPA5 solder pad | TestPoint:TestPoint_Pad_1.5x1.5mm | 1
J97 | MCP23017 GPA6 solder pad | TestPoint:TestPoint_Pad_1.5x1.5mm | 1
J98 | MCP23017 GPA7 solder pad | TestPoint:TestPoint_Pad_1.5x1.5mm | 1
J99 | MCP23017 GPB0 solder pad | TestPoint:TestPoint_Pad_1.5x1.5mm | 1
J910 | MCP23017 GPB1 solder pad | TestPoint:TestPoint_Pad_1.5x1.5mm | 1
J911 | MCP23017 GPB2 solder pad | TestPoint:TestPoint_Pad_1.5x1.5mm | 1
J912 | MCP23017 GPB3 solder pad | TestPoint:TestPoint_Pad_1.5x1.5mm | 1
J913 | MCP23017 GPB4 solder pad | TestPoint:TestPoint_Pad_1.5x1.5mm | 1
J914 | MCP23017 GPB5 solder pad | TestPoint:TestPoint_Pad_1.5x1.5mm | 1
J915 | MCP23017 GPB6 solder pad | TestPoint:TestPoint_Pad_1.5x1.5mm | 1
J916 | MCP23017 GPB7 solder pad | TestPoint:TestPoint_Pad_1.5x1.5mm | 1
J925 | MCP23017 INTA solder pad | TestPoint:TestPoint_Pad_1.5x1.5mm | 1
J926 | MCP23017 INTB solder pad | TestPoint:TestPoint_Pad_1.5x1.5mm | 1
J927 | MCP23017 RESET solder pad | TestPoint:TestPoint_Pad_1.5x1.5mm | 1
J928 | MCP23017 +3V3_SW solder pad | TestPoint:TestPoint_Pad_1.5x1.5mm | 1
J929 | MCP23017 GND solder pad | TestPoint:TestPoint_Pad_1.5x1.5mm | 1
L1 | 4.7uH >=3A sat | Inductor_SMD:L_APV_ANR4020 | 1 |  |  | https://www.digikey.com/en/products/result?keywords=4.7uH+%3E%3D3A+sat+shielded+inductor+SMD
L2 | 4.7uH >=2A sat | Inductor_SMD:L_APV_ANR4020 | 1 |  |  | https://www.digikey.com/en/products/result?keywords=4.7uH+%3E%3D2A+sat+shielded+inductor+SMD
L3 | 1uH >=4A sat | Inductor_SMD:L_APV_ANR5040 | 1 |  |  | https://www.digikey.com/en/products/result?keywords=1uH+%3E%3D4A+sat+shielded+inductor+SMD
Q1 | CSD83325L | Daughterboard:CSD83325L_YJE0006A | 1 |  |  | https://www.digikey.com/en/products/result?keywords=CSD83325L
R1,R2 | 5.1k 1% | Resistor_SMD:R_0603_1608Metric | 2 |  |  | https://www.digikey.com/en/products/result
R3 | 806R 1% ILIM | Resistor_SMD:R_0603_1608Metric | 1 |  |  | https://www.digikey.com/en/products/result?keywords=806+ohm+1%25+0603+resistor
R4 | 220R 1% CBSET | Resistor_SMD:R_0603_1608Metric | 1 |  |  | https://www.digikey.com/en/products/result?keywords=220+ohm+1%25+0603+resistor
R5 | 10k 1% | Resistor_SMD:R_0603_1608Metric | 1 |  |  | https://www.digikey.com/en/products/result
R6,R7 | 2.2k | Resistor_SMD:R_0603_1608Metric | 2 |  |  | https://www.digikey.com/en/products/result?keywords=2.2k+Resistor_SMD%3AR_0603_1608Metric+resistor
R8 | 523k 1% | Resistor_SMD:R_0603_1608Metric | 1 |  |  | https://www.digikey.com/en/products/result
R9,R12 | 100k 1% | Resistor_SMD:R_0603_1608Metric | 2 |  |  | https://www.digikey.com/en/products/result
R10,R13 | 100k | Resistor_SMD:R_0603_1608Metric | 2 |  |  | https://www.digikey.com/en/products/result?keywords=100k+Resistor_SMD%3AR_0603_1608Metric+resistor
R11 | 316k 1% | Resistor_SMD:R_0603_1608Metric | 1 |  |  | https://www.digikey.com/en/products/result
R14,R15 | 470R 1% | Resistor_SMD:R_0603_1608Metric | 2 |  |  | https://www.digikey.com/en/products/result
R16 | 2.0k 1% | Resistor_SMD:R_0603_1608Metric | 1 |  |  | https://www.digikey.com/en/products/result
R17,R18 | 330R | Resistor_SMD:R_0603_1608Metric | 2 |  |  | https://www.digikey.com/en/products/result?keywords=330R+Resistor_SMD%3AR_0603_1608Metric+resistor
R19,R20 | 4.7k | Resistor_SMD:R_0603_1608Metric | 2 |  |  | https://www.digikey.com/en/products/result?keywords=4.7k+Resistor_SMD%3AR_0603_1608Metric+resistor
R21-R38 | 100R | Resistor_SMD:R_0603_1608Metric | 18 |  |  | https://www.digikey.com/en/products/result?keywords=100R+Resistor_SMD%3AR_0603_1608Metric+resistor
R39-R41,R45 | 0R | Resistor_SMD:R_0603_1608Metric | 4 |  |  | https://www.digikey.com/en/products/result?keywords=0R+Resistor_SMD%3AR_0603_1608Metric+resistor
R42-R44 | 10k | Resistor_SMD:R_0603_1608Metric | 3 |  |  | https://www.digikey.com/en/products/result?keywords=10k+Resistor_SMD%3AR_0603_1608Metric+resistor
SW1 | Pololu #2808 5V switch | Daughterboard:Pololu_2808_Raised_Header | 1 |  |  | https://www.pololu.com/product/2808
SW2 | Pololu #2808 3V3 switch | Daughterboard:Pololu_2808_Raised_Header | 1 |  |  | https://www.pololu.com/product/2808
TH1 | 10k NTC | Resistor_SMD:R_0603_1608Metric | 1 |  |  | https://www.digikey.com/en/products/result?keywords=10k+NTC+0603+NTC+thermistor
TP1 | USB_VBUS test pad | TestPoint:TestPoint_Pad_D1.0mm | 1
TP2 | CHG_IN test pad | TestPoint:TestPoint_Pad_D1.0mm | 1
TP3 | PACK_P test pad | TestPoint:TestPoint_Pad_D1.0mm | 1
TP4 | CELL_MID test pad | TestPoint:TestPoint_Pad_D1.0mm | 1
TP5 | BAT_SYS test pad | TestPoint:TestPoint_Pad_D1.0mm | 1
TP6 | +5V test pad | TestPoint:TestPoint_Pad_D1.0mm | 1
TP7 | +3V3 test pad | TestPoint:TestPoint_Pad_D1.0mm | 1
TP8 | +5V_SW test pad | TestPoint:TestPoint_Pad_D1.0mm | 1
TP9 | +3V3_SW test pad | TestPoint:TestPoint_Pad_D1.0mm | 1
TP10 | CHG_STAT test pad | TestPoint:TestPoint_Pad_D1.0mm | 1
TP11 | PG_STAT test pad | TestPoint:TestPoint_Pad_D1.0mm | 1
TP12 | BATT_RAW_N test pad | TestPoint:TestPoint_Pad_D1.0mm | 1
TP13 | VM_SENSE test pad | TestPoint:TestPoint_Pad_D1.0mm | 1
TP14 | GND test pad | TestPoint:TestPoint_Pad_D1.0mm | 1
U1 | BQ25887RGE 2S charger | Package_DFN_QFN:Texas_RGE0024H_VQFN-24-1EP_4x4mm_P0.5mm_EP2.7x2.7mm | 1 |  |  | https://www.digikey.com/en/products/result?keywords=BQ25887RGE
U2 | S-8252AAH-M6T1U | Package_TO_SOT_SMD:SOT-23-6 | 1 |  |  | https://www.digikey.com/en/products/result?keywords=S-8252AAH-M6T1U
U3 | AP63200WU 5V Buck | Package_TO_SOT_SMD:TSOT-23-6 | 1 |  |  | https://www.digikey.com/en/products/result?keywords=AP63200WU
U4 | AP63200WU 3V3 Buck | Package_TO_SOT_SMD:TSOT-23-6 | 1 |  |  | https://www.digikey.com/en/products/result?keywords=AP63200WU
U5 | ADS1115IDGS 0x48 | Package_SO:TSSOP-10_3x3mm_P0.5mm | 1 |  |  | https://www.digikey.com/en/products/result?keywords=ADS1115IDGS
U6 | ADS1115IDGS 0x49 | Package_SO:TSSOP-10_3x3mm_P0.5mm | 1 |  |  | https://www.digikey.com/en/products/result?keywords=ADS1115IDGS
U7 | MCP23017-E/SO | Daughterboard:SOIC-28W_7.5x17.9mm_P1.27mm_NoPads11_14 | 1 |  |  | https://www.digikey.com/en/products/result?keywords=MCP23017-E%2FSO

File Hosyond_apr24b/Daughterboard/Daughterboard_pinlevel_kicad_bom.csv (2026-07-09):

Refs | Value | Footprint | Qty | DNP | Purchase Link
BT1 | 18650 Cell 1 |  | 1 |  | https://www.digikey.com/en/products/result?keywords=18650+battery+holder+single+cell+PCB
BT2 | 18650 Cell 2 |  | 1 |  | https://www.digikey.com/en/products/result?keywords=18650+battery+holder+single+cell+PCB
C1 | 10uF 10V X5R | Capacitor_SMD:C_0805_2012Metric | 1 |  | https://www.digikey.com/en/products/result
C2 | 100nF 10V X7R | Capacitor_SMD:C_0603_1608Metric | 1 |  | https://www.digikey.com/en/products/result
C3 | 1uF 10V X7R | Capacitor_SMD:C_0603_1608Metric | 1 |  | https://www.digikey.com/en/products/result
C4 | 10uF 10V X5R | Capacitor_SMD:C_0805_2012Metric | 1 |  | https://www.digikey.com/en/products/result
C5 | 100nF 10V X7R | Capacitor_SMD:C_0603_1608Metric | 1 |  | https://www.digikey.com/en/products/result
C6 | 10uF 10V X5R | Capacitor_SMD:C_0805_2012Metric | 1 |  | https://www.digikey.com/en/products/result
C7 | 100nF 10V X7R | Capacitor_SMD:C_0603_1608Metric | 1 |  | https://www.digikey.com/en/products/result
C8 | 22uF 10V X5R | Capacitor_SMD:C_0805_2012Metric | 1 |  | https://www.digikey.com/en/products/result
C9 | 100nF 10V X7R | Capacitor_SMD:C_0603_1608Metric | 1 |  | https://www.digikey.com/en/products/result
C10 | 22uF 10V X5R | Capacitor_SMD:C_0805_2012Metric | 1 |  | https://www.digikey.com/en/products/result
C11 | 22uF 10V X5R | Capacitor_SMD:C_0805_2012Metric | 1 |  | https://www.digikey.com/en/products/result
C12 | 22pF C0G | Capacitor_SMD:C_0603_1608Metric | 1 |  | https://www.digikey.com/en/products/result
C13 | 10uF 10V X5R | Capacitor_SMD:C_0805_2012Metric | 1 |  | https://www.digikey.com/en/products/result
C14 | 100nF 10V X7R | Capacitor_SMD:C_0603_1608Metric | 1 |  | https://www.digikey.com/en/products/result
C15 | 22uF 10V X5R | Capacitor_SMD:C_0805_2012Metric | 1 |  | https://www.digikey.com/en/products/result
C16 | 22uF 10V X5R | Capacitor_SMD:C_0805_2012Metric | 1 |  | https://www.digikey.com/en/products/result
C17 | 100nF 10V X7R | Capacitor_SMD:C_0603_1608Metric | 1 |  | https://www.digikey.com/en/products/result
C18 | 1uF 10V X5R | Capacitor_SMD:C_0603_1608Metric | 1 |  | https://www.digikey.com/en/products/result
C19 | 100nF 10V X7R | Capacitor_SMD:C_0603_1608Metric | 1 |  | https://www.digikey.com/en/products/result
C20 | 1uF 10V X5R | Capacitor_SMD:C_0603_1608Metric | 1 |  | https://www.digikey.com/en/products/result
D1 | 5V VBUS TVS | Diode_SMD:D_SOD-323 | 1 |  | https://www.digikey.com/en/products/result?keywords=5V+VBUS+TVS+SOD-323+TVS+diode
D2 | LED green | LED_SMD:LED_0603_1608Metric | 1 |  | https://www.digikey.com/en/products/result?keywords=LED+green+0603+LED
D3 | LED blue | LED_SMD:LED_0603_1608Metric | 1 |  | https://www.digikey.com/en/products/result?keywords=LED+blue+0603+LED
F1 | 2A hold polyfuse |  | 1 |  | https://www.digikey.com/en/products/result?keywords=2A+hold+polyfuse+resettable+fuse+PTC+SMD
F2 | PTC/fuse per-cell |  | 1 |  | https://www.digikey.com/en/products/result?keywords=PTC%2Ffuse+per-cell+resettable+fuse+PTC+SMD
F3 | PTC/fuse per-cell |  | 1 |  | https://www.digikey.com/en/products/result?keywords=PTC%2Ffuse+per-cell+resettable+fuse+PTC+SMD
J1 | USB-C 5V Sink | Connector_USB:USB_C_Receptacle_GCT_USB4125-xx-x_6P_TopMnt_Horizontal | 1 |  | https://www.digikey.com/en/products/result?keywords=GCT+USB4125+USB-C+receptacle+6+pin
J2 | Switched power outputs |  | 1 |  | https://www.digikey.com/en/products/result?keywords=2.54mm+pin+header+vertical+3+position
J4 | UART JST-GH 1.25mm | Connector_JST:JST_GH_SM05B-GHS-TB_1x05-1MP_P1.25mm_Horizontal | 1 |  | https://www.digikey.com/en/products/result?keywords=SM05B-GHS-TB+JST+GH+5+position
J5 | I2C male header 2.54mm | Connector_PinHeader_2.54mm:PinHeader_1x04_P2.54mm_Vertical | 1 |  | https://www.digikey.com/en/products/result?keywords=2.54mm+pin+header+vertical+4+position
J6 | Deep sleep pushbutton header | Connector_PinHeader_2.54mm:PinHeader_1x02_P2.54mm_Vertical | 1 |  | https://www.digikey.com/en/products/result?keywords=2.54mm+pin+header+vertical+2+position
J8 | Analog input header | Connector_PinHeader_2.54mm:PinHeader_1x10_P2.54mm_Vertical | 1 |  | https://www.digikey.com/en/products/result?keywords=2.54mm+pin+header+vertical+10+position
J31 | J3A Hosyond UART_TX solder pad | Connector_Wire:SolderWire-0.15sqmm_1x01_D0.5mm_OD1.5mm | 1
J32 | J3B Hosyond UART_RX solder pad | Connector_Wire:SolderWire-0.15sqmm_1x01_D0.5mm_OD1.5mm | 1
J33 | J3C Hosyond I2C_SDA solder pad | Connector_Wire:SolderWire-0.15sqmm_1x01_D0.5mm_OD1.5mm | 1
J34 | J3D Hosyond I2C_SCL solder pad | Connector_Wire:SolderWire-0.15sqmm_1x01_D0.5mm_OD1.5mm | 1
J35 | J3E Hosyond GPIO2 solder pad | Connector_Wire:SolderWire-0.15sqmm_1x01_D0.5mm_OD1.5mm | 1
J36 | J3F Hosyond GPIO3 solder pad | Connector_Wire:SolderWire-0.15sqmm_1x01_D0.5mm_OD1.5mm | 1
J37 | J3G Hosyond GPIO14 solder pad | Connector_Wire:SolderWire-0.15sqmm_1x01_D0.5mm_OD1.5mm | 1
J38 | J3H Hosyond GPIO21 solder pad | Connector_Wire:SolderWire-0.15sqmm_1x01_D0.5mm_OD1.5mm | 1
J39 | J3I Hosyond GND solder pad | Connector_Wire:SolderWire-0.15sqmm_1x01_D0.5mm_OD1.5mm | 1
L1 | 1uH >=5A sat |  | 1 |  | https://www.digikey.com/en/products/result?keywords=1uH+%3E%3D5A+sat+shielded+inductor+SMD
L2 | 2.2uH >=2.5A sat |  | 1 |  | https://www.digikey.com/en/products/result?keywords=2.2uH+%3E%3D2.5A+sat+shielded+inductor+SMD
Q1 | CSD83325L | Daughterboard:CSD83325L_YJE0006A | 1 |  | https://www.digikey.com/en/products/result?keywords=CSD83325L
R1 | 5.1k 1% | Resistor_SMD:R_0603_1608Metric | 1 |  | https://www.digikey.com/en/products/result
R2 | 5.1k 1% | Resistor_SMD:R_0603_1608Metric | 1 |  | https://www.digikey.com/en/products/result
R3 | 590R 1% | Resistor_SMD:R_0603_1608Metric | 1 |  | https://www.digikey.com/en/products/result
R4 | 1.10k 1% | Resistor_SMD:R_0603_1608Metric | 1 |  | https://www.digikey.com/en/products/result
R5 | 100k | Resistor_SMD:R_0603_1608Metric | 1 |  | https://www.digikey.com/en/products/result?keywords=100k+Resistor_SMD%3AR_0603_1608Metric+resistor
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

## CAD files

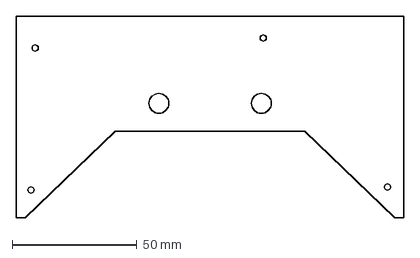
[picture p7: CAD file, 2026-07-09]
Daughterboard/fabrication/jlcpcb_2026-07-14_r16/source/daughterboard2.dxf
155.0 x 80.6 mm

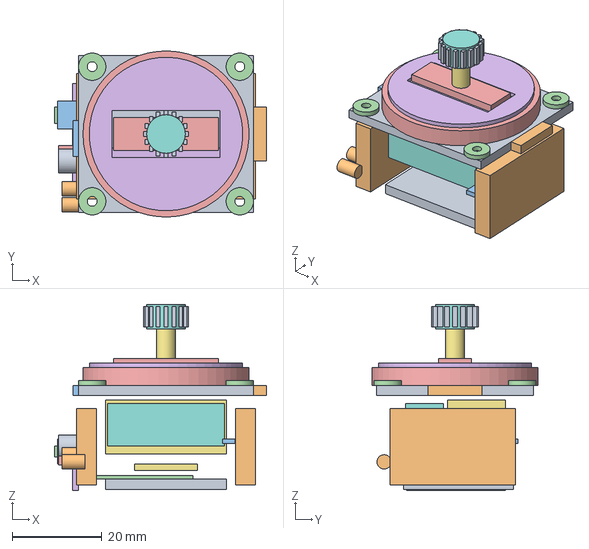
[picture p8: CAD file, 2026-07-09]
Daughterboard/radiomaster_x5_gimbal_fit_model.step
47.2 x 37.0 x 41.5 mm

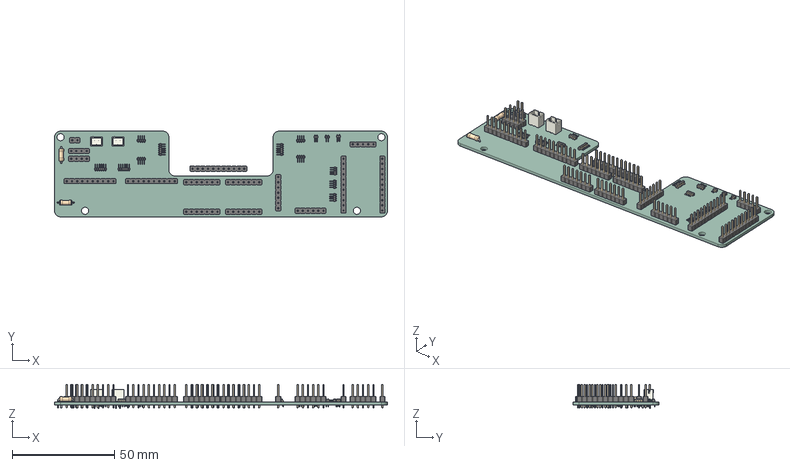
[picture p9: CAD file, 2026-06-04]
Hosyond_apr24b/Daughterboard/daughterboard/.step
163.0 x 42.0 x 11.9 mm
PinHeader_1x05_P254mm_Vertical
PinHeader_1x04_P254mm_Vertical x 2
PinHeader_1x04_P100mm_Horizontal x 7
PinHeader_1x10_P254mm_Vertical x 2
JST_B2B_PH_K x 2
PinHeader_1x06_P100mm_Horizontal x 4
R_Axial_DIN0207_L63mm_D25mm_P762mm_Horizontal x 2
PinHeader_1x07_P254mm_Vertical x 5
PinHeader_1x02_P100mm_Horizontal x 3
PinHeader_1x11_P254mm_Vertical x 3
PinHeader_1x02_P254mm_Vertical
PinHeader_1x06_P254mm_Vertical
daughterboard_PCB

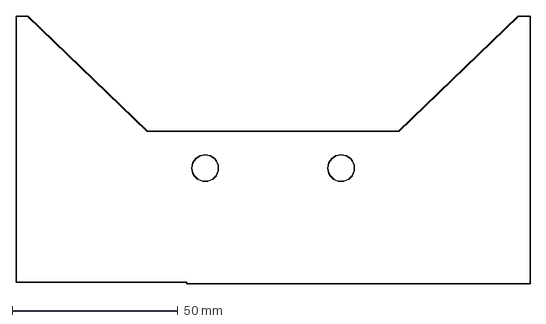
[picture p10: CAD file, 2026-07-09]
Hosyond_apr24b/Daughterboard/daughterboard2.dxf
155.0 x 80.6 mm

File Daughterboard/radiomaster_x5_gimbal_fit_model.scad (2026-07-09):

// RadioMaster Pocket X5 gimbal fit/detail model
// Units: mm
//
// Measured dimensions:
// - Mounting hole spacing: 32.9 mm x 30.0 mm center-to-center
// - Front mounting plate: 39 mm x 35 mm
// - Right-side front bump width: 41.9 mm overall
// - Raised circular front shroud: 37 mm diameter, overhangs the 35 mm plate height
// - Mounting holes: 4x 2.2 mm
// - Overall height: 43.3 mm from bottom of gimbal to top of stick
// - Side-view body depth: about 23.0 mm below the front mounting face
//
// Photo-derived details are approximate and intended for enclosure/clearance design.

$fn = 96;

plate_w = 39.0;
plate_w_at_bump = 41.9;
plate_h = 35.0;
plate_t = 2.2;
corner_r = 3.1;
right_bump_w = plate_w_at_bump - plate_w;
right_bump_h = 12.0;

mount_spacing_x = 32.9;
mount_spacing_y = 30.0;
mounting_hole_d = 2.2;
screw_boss_d = 6.1;
screw_boss_h = 1.1;

shroud_d = 37.0;
shroud_h = 4.0;
shroud_lip_d = 34.2;
shroud_lip_h = 1.0;
window_w = 24.0;
window_h = 10.5;

body_w = 34.0;
body_h = 30.0;
body_depth = 23.0;
overall_height = 43.3;

stick_shaft_d = 4.2;
stick_cap_d = 8.6;
stick_cap_h = 5.5;
stick_top_z = overall_height - body_depth;
stick_base_z = plate_t + shroud_h;
stick_shaft_h = stick_top_z - stick_base_z - stick_cap_h;

pcb_t = 1.4;

module rounded_rect_2d(w, h, r) {
    hull() {
        for (x=[-w/2+r, w/2-r])
            for (y=[-h/2+r, h/2-r])
                translate([x, y])
                    circle(r=r);
    }
}

module front_plate_2d() {
    union() {
        rounded_rect_2d(plate_w, plate_h, corner_r);
        translate([plate_w/2 + right_bump_w/2 - 0.02, 0])
            square([right_bump_w + 0.04, right_bump_h], center=true);
        // Small left-side cable latch seen in the side photos.
        translate([-plate_w/2 - 0.6, -1.0])
            square([1.2, 8.0], center=true);
    }
}

module front_plate() {
    difference() {
        linear_extrude(plate_t)
            front_plate_2d();

        for (x=[-mount_spacing_x/2, mount_spacing_x/2])
            for (y=[-mount_spacing_y/2, mount_spacing_y/2])
                translate([x, y, -0.1])
                    cylinder(h=plate_t + screw_boss_h + 0.4, d=mounting_hole_d);
    }
}

module screw_bosses() {
    difference() {
        union() {
            for (x=[-mount_spacing_x/2, mount_spacing_x/2])
                for (y=[-mount_spacing_y/2, mount_spacing_y/2])
                    translate([x, y, plate_t])
                        cylinder(h=screw_boss_h, d=screw_boss_d);
        }
        for (x=[-mount_spacing_x/2, mount_spacing_x/2])
            for (y=[-mount_spacing_y/2, mount_spacing_y/2])
                translate([x, y, plate_t - 0.1])
                    cylinder(h=screw_boss_h + 0.3, d=mounting_hole_d);
    }
}

module front_shroud() {
    difference() {
        union() {
            translate([0, 0, plate_t])
                cylinder(h=shroud_h, d=shroud_d);
            translate([0, 0, plate_t + shroud_h])
                cylinder(h=shroud_lip_h, d=shroud_lip_d);
        }

        // The front opening is visually a wide rectangular travel window inside the cup.
        translate([0, 0, plate_t + 0.45])
            cube([window_w, window_h, shroud_h + shroud_lip_h + 0.8], center=true);
    }
}

module front_yoke() {
    translate([0, 0, plate_t + 1.6])
        cube([23.5, 7.4, 4.4], center=true);
    translate([0, -4.5, plate_t + 1.0])
        cube([26.0, 2.8, 2.0], center=true);
}

module stick() {
    color("silver") {
        translate([0, 0, stick_base_z])
            cylinder(h=stick_shaft_h, d=stick_shaft_d);

        translate([0, 0, stick_base_z + stick_shaft_h])
            cylinder(h=stick_cap_h, d=stick_cap_d);

        // Coarse knurl ridges around the cap.
        for (i=[0:15]) {
            rotate([0, 0, i * 360 / 16])
                translate([stick_cap_d/2 + 0.25, 0, stick_base_z + stick_shaft_h + stick_cap_h/2])
                    cube([0.7, 1.2, stick_cap_h * 0.82], center=true);
        }
    }
}

module rear_body() {
    color("black") {
        translate([0, 0, -body_depth/2])
            cube([body_w, body_h, body_depth], center=true);

        translate([0, -8.8, -6.8])
            cube([26.0, 5.0, 8.0], center=true);

        // Bottom cylindrical posts visible from the side.
        for (x=[-14.0, 14.0])
            translate([x, -plate_h/2 - 1.0, -12.5])
                cylinder(h=8.0, d=3.2);
    }
}

module underside_details() {
    // Left connector pair and small side PCB.
    color("white") {
        translate([-22.0, 3.4, -7.5])
            cube([4.2, 6.0, 3.2], center=true);
        translate([-22.0, -4.5, -9.2])
            cube([4.0, 5.0, 3.0], center=true);
    }

    color("darkslategray") {
        translate([0, 4.0, -12.0])
            cube([14.0, 7.0, pcb_t], center=true);
        translate([18.5, 1.5, -10.5])
            cube([8.0, 13.0, pcb_t], center=true);
    }

    // Metal strap on bottom/right side.
    color("silver")
        translate([14.0, 0, -7.0])
            cube([3.0, 28.0, 1.1], center=true);

    // Approximate colored wire bundle paths.
    for (dy=[-1.8, 0, 1.8]) {
        color(dy < -1 ? "red" : dy > 1 ? "yellow" : "black")
            translate([2.0, dy, -10.8])
                rotate([0, 90, 0])
                    cylinder(h=31.0, d=0.9, center=true);
    }
}

module clearance_envelope() {
    // Transparent-ish max envelope that includes the side bump and bottom protrusions.
    // Enable manually if you want to sanity-check enclosure clearance.
    // color([0, 0.4, 1, 0.18]) cube([45, 39, 43], center=true);
}

module gimbal_fit_model() {
    color("black") front_plate();
    color("black") screw_bosses();
    color("black") front_shroud();
    color("black") front_yoke();
    rear_body();
    underside_details();
    stick();
    clearance_envelope();
}

gimbal_fit_model();

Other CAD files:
Daughterboard/radiomaster_x5_gimbal_fit_model.stl

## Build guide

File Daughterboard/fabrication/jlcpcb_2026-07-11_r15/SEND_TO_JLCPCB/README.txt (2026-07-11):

Anubis Daughterboard - JLCPCB order bundle (rev r15, 2026-07-11)

UPLOAD THESE THREE FILES
  1_Daughterboard_r15_gerber_drill.zip  -> PCB tab: "Add gerber file"
  2_Daughterboard_r15_BOM.csv           -> Assembly: BOM file
  3_Daughterboard_r15_CPL.csv           -> Assembly: CPL / placement file

BOARD SETTINGS (match these on the JLCPCB order page)
  Layers:        4
  Dimensions:    155.12 x 80.76 mm
  Surface finish: HAL lead-free (or upgrade to ENIG if preferred)

ASSEMBLY
  Assembly side: Top only
  Placements:    113 parts, all mapped to LCSC parts (R49/R50 = C7250, JLC Basic)

HAND-INSTALL (NOT on the BOM/CPL - solder yourself after delivery)
  J5, J6  - 2.54 mm through-hole pin headers
  SW1, SW2 - Pololu #2808 rail-switch modules

Passed all 6 release gates (ERC, DRC+parity, gerber freshness, package
integrity, fab metadata, BOM/CPL) with zero warnings.

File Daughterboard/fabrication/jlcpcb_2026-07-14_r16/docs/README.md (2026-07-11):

# Anubis RC Controller Daughterboard

**A compact open-hardware support board for a DIY ESP32-S3 RC transmitter.**

Anubis is an open hardware and open firmware RC controller project built around accessible DIY parts, modern radio-control features, and a design that builders can understand, repair, modify, and improve.

This repository contains the custom daughterboard for the Anubis controller. It sits under a Hosyond 2.8 inch ESP32-S3 display board and turns the early wiring-heavy prototype into a cleaner, more repeatable hardware platform.

## Mission

The goal is simple: make a capable, repairable, hackable transmitter that is not locked behind a black box.

The first Anubis prototype used off-the-shelf modules wired together by hand: display board, power switches, regulators, analog input boards, GPIO expanders, gimbal connectors, and radio wiring. That is a great way to prove an idea, but it gets messy fast. This daughterboard pulls those support circuits onto a purpose-built PCB while leaving the Hosyond ESP32-S3 board as the main brain, display, touch interface, and firmware target.

Anubis is meant for experimentation as much as use. Builders should be able to change pin mappings, adapt connectors, swap radio hardware, and tune the firmware for their own transmitter layout.

## At A Glance

| Area | Current Direction |
| --- | --- |
| Main controller | Hosyond 2.8 inch ESP32-S3 display/dev board |
| Battery system | 2S LiPo or two 18650 cells as a 2S pack |
| Charging input | USB-C 5 V input, 500 mA to 1.5 A charge target |
| Switched outputs | `+5V_SW` and `+3V3_SW` accessory rails |
| Analog inputs | Two onboard ADS1115 ADCs, up to 8 analog channels |
| GPIO expansion | MCP23017 16-bit I2C GPIO expander |
| Radio paths | ELRS/CRSF over UART and optional ESP-NOW |
| Assembly goal | As much JLCPCB assembly as practical |
| Project status | Prototype hardware, ready for assembled-board validation |

## Core Design Goals

- Use common, hobby-accessible parts where possible.
- Keep the project open enough for community modification.
- Support modern RC workflows such as ELRS and ESP-NOW.
- Reduce hand wiring compared with the early prototype.
- Make the board practical for JLCPCB assembly.
- Keep external accessory power switchable from firmware.
- Leave room for manual wiring where real-world modules and harnesses vary.

## Hardware Overview

The daughterboard adds the support electronics around the Hosyond ESP32-S3 board:

- USB-C 5 V input for charging and power input.
- Standard 2S LiPo balance connector for the battery pack.
- Support for a 2S LiPo pack or two 18650 cells configured as a 2S pack.
- 2S battery gauge/protection circuitry based around `BQ28Z610DRZR-R1`.
- R14 high-side protection path using two JLC-available `CSD18502Q5B` N-FETs, with the charger and buck regulators fed from protected `BAT_SYS`.
- Switched 5 V rail for UART/ELRS-side accessories.
- Switched 3.3 V rail for I2C, analog, and low-voltage peripherals.
- Two Pololu mini pushbutton power switch modules for rail control.
- Two onboard ADS1115 ADC circuits for up to eight analog inputs.
- One onboard MCP23017 GPIO expander for buttons and digital expansion.
- JST and pin-header breakouts for UART, I2C, GPIO, gimbals, and accessories.
- ESD protection for external signal connections.
- Ground plane and wider routing rules for higher-current power paths.

## Power Rails

| Rail | Intended Use | Approximate Max Current |
| --- | --- | --- |
| USB-C input | 5 V charge/input source | 500 mA to 1.5 A charge target |
| `+5V_SW` | ELRS/UART-side accessory power | about 1 A |
| `+3V3_SW` | I2C, ADCs, MCP23017, gimbals, sensors | about 500 mA |

The switched rails are controlled through the two Pololu #2808 mini pushbutton power switch modules. The ESP32-S3 can shut down attached devices without relying on the attached devices to behave nicely.

## Firmware Map

The main Anubis firmware runs on the Hosyond ESP32-S3 board. Current daughterboard-aware firmware support includes:

- Touchscreen UI for transmitter settings.
- Model storage and configuration.
- Stick calibration.
- Expo, rates, trims, endpoints, failsafe, and mixing.
- ELRS/CRSF support over UART.
- ESP-NOW transmitter support.
- Dual ADS1115 support for onboard analog inputs at `0x48` and `0x49`.
- MCP23017 GPIO expander support at `0x20`.
- Battery monitoring and deep-sleep behavior.

### Pin Assignments

| Function | ESP32-S3 Pin |
| --- | --- |
| I2C SDA | GPIO16 |
| I2C SCL | GPIO15 |
| ELRS/UART TX | GPIO44 |
| ELRS/UART RX | GPIO43 |
| Battery ADC | GPIO9 |
| 5 V rail switch control | GPIO2 |
| 3.3 V rail switch control | GPIO3 |
| Deep-sleep/wake button sense | GPIO14 |
| Deep-sleep/wake button reference | GPIO21 |

GPIO2 and GPIO3 control the two Pololu rail-switch modules. GPIO14 and GPIO21 route to the two-pin deep-sleep/wake pushbutton header. UART-to-ELRS wiring can still be crossed manually if a specific module harness expects the opposite order.

### I2C Devices

| Device | Address | Role |
| --- | --- | --- |
| ADS1115 primary | `0x48` | Four gimbal/stick analog axes |
| ADS1115 auxiliary | `0x49` | Spare analog inputs |
| MCP23017 | `0x20` | GPIO expansion and active-low button/switch inputs |
| BQ25887 charger | `0x6B` | 2S charger status and pack voltage reporting |

## Board Connection Reference

The following tables describe the designators and nets on the R14 PCB. Pin numbers are the KiCad footprint pin numbers and should be checked against connector orientation and pin-1 markings before making a cable.

### Electrical Test Pads

| Pad | Net | Signal source or intended measurement |
| --- | --- | --- |
| `TP1` | `USB_VBUS` | USB-C `J1` VBUS, before input fuse `F1` |
| `TP2` | `CHG_IN` | Fused USB input after `F1`; charger `U1` pin 23 |
| `TP3` | `BAT_SYS` | Protected battery/system bus feeding charger `U1` BAT pins and the 5 V/3.3 V regulators |
| `TP4` | `CELL_MID` | 2S pack midpoint from `J7` pin 2; charger `U1` pin 9 sense connection |
| `TP5` | `BAT_SYS` | Second protected battery/system-bus test point; electrically the same as `TP3` |
| `TP6` | `+5V` | Unswitched 5 V regulator output after `L1`, before Pololu switch `SW1` |
| `TP7` | `+3V3` | Unswitched 3.3 V regulator output after `L2`, before Pololu switch `SW2` |
| `TP9` | `+3V3_SW` | Switched 3.3 V output from `SW2` |
| `TP10` | `CHG_STAT` | Charger `U1` pin 2 charge-status output; also drives status LED `D2` |
| `TP11` | `PG_STAT` | Charger `U1` pin 1 power-good output; also drives status LED `D3` |
| `TP12` | `BATT_RAW_N` | Raw pack negative from `J7` pin 1, on the battery side of current-sense resistor `R46` |
| `TP13` | `BATT_RAW_P` | Raw pack positive from `J7` pin 3 |
| `TP14` | `GND` | System ground, on the system side of current-sense resistor `R46` |
| `TP15` | `AIN4` | Auxiliary ADC `U6` (`0x49`) AIN0, pin 4 |
| `TP16` | `AIN5` | Auxiliary ADC `U6` (`0x49`) AIN1, pin 5 |
| `TP17` | `AIN6` | Auxiliary ADC `U6` (`0x49`) AIN2, pin 6 |
| `TP18` | `AIN7` | Auxiliary ADC `U6` (`0x49`) AIN3, pin 7 |

`TP8` is not fitted on the R14 PCB. Use `J30` or `J4` pin 1 to access `+5V_SW`. Also note that `BATT_RAW_N` and `GND` are separated by the 2 mOhm current-sense resistor; do not treat `TP12` and `TP14` as interchangeable measurement points.

### Hosyond Manual Solder Pads

These pads replace the original `J3` connector so individual wires from the Hosyond board can be soldered directly to the daughterboard.

| Pad | Net | Hosyond/source mapping |
| --- | --- | --- |
| `J30` | `+5V_SW` | Switched 5 V output from `SW1`; also available at `J4` pin 1 |
| `J31` | `UART_TX` | Hosyond ESP32-S3 GPIO44; routed to `J4` pin 3 |
| `J32` | `UART_RX` | Hosyond ESP32-S3 GPIO43; routed to `J4` pin 4 |
| `J33` | `I2C_SDA` | Hosyond ESP32-S3 GPIO16; shared daughterboard I2C data bus |
| `J34` | `I2C_SCL` | Hosyond ESP32-S3 GPIO15; shared daughterboard I2C clock bus |
| `J35` | `GPIO2` | Hosyond ESP32-S3 GPIO2; drives `SW1` 5 V control through `R17` |
| `J36` | `GPIO3` | Hosyond ESP32-S3 GPIO3; drives `SW2` 3.3 V control through `R18` |
| `J37` | `GPIO14` | Hosyond ESP32-S3 GPIO14; routed to wake-button header `J6` pin 1 |
| `J38` | `GPIO21` | Hosyond ESP32-S3 GPIO21; routed to wake-button header `J6` pin 2 |
| `J39` | `GND` | Daughterboard system ground |

### MCP23017 Manual Solder Pads

The `EXP_*` GPIO pads are on the protected external side of a 100 ohm series resistor and an ESD array. `U7` is the MCP23017 at I2C address `0x20`.

| Pad | Net | Source |
| --- | --- | --- |
| `J91` | `EXP_GPA0` | `U7` GPA0 pin 21 through `R23`; ESD `D4` |
| `J92` | `EXP_GPA1` | `U7` GPA1 pin 22 through `R24`; ESD `D4` |
| `J93` | `EXP_GPA2` | `U7` GPA2 pin 23 through `R25`; ESD `D4` |
| `J94` | `EXP_GPA3` | `U7` GPA3 pin 24 through `R26`; ESD `D4` |
| `J95` | `EXP_GPA4` | `U7` GPA4 pin 25 through `R27`; ESD `D5` |
| `J96` | `EXP_GPA5` | `U7` GPA5 pin 26 through `R28`; ESD `D5` |
| `J97` | `EXP_GPA6` | `U7` GPA6 pin 27 through `R29`; ESD `D5` |
| `J98` | `EXP_GPA7` | `U7` GPA7 pin 28 through `R30`; ESD `D5` |
| `J99` | `EXP_GPB0` | `U7` GPB0 pin 1 through `R31`; ESD `D6` |
| `J910` | `EXP_GPB1` | `U7` GPB1 pin 2 through `R32`; ESD `D6` |
| `J911` | `EXP_GPB2` | `U7` GPB2 pin 3 through `R33`; ESD `D6` |
| `J912` | `EXP_GPB3` | `U7` GPB3 pin 4 through `R34`; ESD `D6` |
| `J913` | `EXP_GPB4` | `U7` GPB4 pin 5 through `R35`; ESD `D7` |
| `J914` | `EXP_GPB5` | `U7` GPB5 pin 6 through `R36`; ESD `D7` |
| `J915` | `EXP_GPB6` | `U7` GPB6 pin 7 through `R37`; ESD `D7` |
| `J916` | `EXP_GPB7` | `U7` GPB7 pin 8 through `R38`; ESD `D7` |
| `J925` | `MCP_INTA` | `U7` INTA pin 20 with pull-up `R43` |
| `J926` | `MCP_INTB` | `U7` INTB pin 19 with pull-up `R44` |
| `J927` | `MCP_RESET` | `U7` RESET pin 18 with pull-up `R42` and capacitor `C29` |
| `J928` | `+3V3_SW_LOGIC` | Switched 3.3 V logic rail after isolation link `R45` |
| `J929` | `GND` | Daughterboard system ground |

### Connector Pinouts

| Connector | Purpose | Pinout |
| --- | --- | --- |
| `J1` | USB-C 5 V input | A5 = `CC1`; B5 = `CC2`; A9/B9 = `USB_VBUS`; A12/B12 = `GND`; shield tabs = `GND` |
| `J4` | 5-pin UART JST-GH, top-entry, 1.25 mm | 1 = `+5V_SW`; 2 = `GND`; 3 = `UART_TX`; 4 = `UART_RX`; 5 = `GND` |
| `J5` | 4-pin I2C through-hole header, 2.54 mm | 1 = `+3V3_SW`; 2 = `GND`; 3 = `I2C_SDA`; 4 = `I2C_SCL` |
| `J6` | 2-pin deep-sleep/wake button header, 2.54 mm | 1 = `GPIO14`; 2 = `GPIO21`; a momentary button connects the two pins |
| `J7` | 2S balance input, side-entry JST-XH, 2.50 mm | 1 = `BATT_RAW_N`; 2 = `CELL_MID`; 3 = `BATT_RAW_P` |
| `J8` | Left gimbal A, 3-pin JST-GH, 1.25 mm | 1 = `GND`; 2 = `AIN0`; 3 = `+3V3_SW` |
| `J40` | Left gimbal B, 3-pin JST-GH, 1.25 mm | 1 = `GND`; 2 = `AIN1`; 3 = `+3V3_SW` |
| `J41` | Right gimbal A, 3-pin JST-GH, 1.25 mm | 1 = `GND`; 2 = `AIN2`; 3 = `+3V3_SW` |
| `J42` | Right gimbal B, 3-pin JST-GH, 1.25 mm | 1 = `GND`; 2 = `AIN3`; 3 = `+3V3_SW` |

`J2` is a schematic-only switched-power-output symbol and has no footprint on the R14 PCB. `J3` is not a physical connector; its signals are implemented as solder pads `J30` through `J39`. JST-GH mounting pads marked `MP` are mechanical and have no electrical connection.

### Pololu Power-Switch Module Headers

| Header | Pin 1 | Pin 2 | Pin 3 | Pin 4 |
| --- | --- | --- | --- | --- |
| `SW1` Pololu #2808 5 V switch | `+5V` input | `+5V_SW` output | `GND` | `CTRL_5V_SW` |
| `SW2` Pololu #2808 3.3 V switch | `+3V3` input | `+3V3_SW` output | `GND` | `CTRL_3V3_SW` |

## Control Hardware

The controller is designed around parts that are easy for hobby builders to source or substitute:

- Hosyond 2.8 inch ESP32-S3 display board as the main controller.
- RadioMaster Pocket/Zorro X5-style gimbals.
- ELRS module support through UART/CRSF.
- Optional ESP-NOW receiver support for WiFi-equipped ESP32 receivers.
- D-pad/button input through the MCP23017 GPIO expander.
- Auxiliary analog inputs through the ADS1115 circuits.

The mechanical layout fits around the Hosyond board and controller shell constraints. The Hosyond board sits above the daughterboard on standoffs, with the daughterboard occupying the surrounding and lower internal space.

## Repository Contents

| Path | Purpose |
| --- | --- |
| `Daughterboard.kicad_pro` | KiCad project file |
| `Daughterboard.kicad_sch` | Main schematic |
| `Daughterboard.kicad_pcb` | PCB layout |
| `Daughterboard.kicad_sym` | Project symbols |
| `Daughterboard.pretty/` | Custom KiCad footprints |
| `Daughterboard.net` | Exported netlist |
| `Daughterboard_pcb_bom.csv` | Human-readable PCB BOM |
| `Daughterboard_current_jlc_part_audit.csv` | JLC part audit/reference |
| `fabrication/` | Fabrication and assembly outputs |
| `daughterboard2.dxf` | Board outline reference |
| `Daughterboardv2.step` | Mechanical board reference |
| `PROJECT_CONTEXT.md` | Detailed working context for future development |

Current fabrication package:

```text
fabrication/jlcpcb_2026-07-10_r14.zip
```

Assembly files are included under:

```text
fabrication/jlcpcb_2026-07-10_r14/assembly/
```

## Manufacturing Notes

The board is being prepared for JLCPCB assembly with as many populated parts as practical. The Pololu mini pushbutton power switch modules are treated as separately installed modules. Some through-hole headers may also be hand-installed unless through-hole assembly is explicitly ordered.

Before ordering boards, always check:

- KiCad ERC and DRC reports.
- Copper clearance and board-edge clearance.
- Unrouted nets.
- Connector orientation.
- IC pin 1 orientation.
- JLCPCB part availability.
- BOM and CPL alignment in the JLCPCB preview.

Known current status from the active R14 working files:

- ERC reports no errors or warnings.
- Q1/Q2 are now JLC-available `CSD18502Q5B` FETs using project-local TI DNK/VSON-CLIP footprints.
- The R14 topology audit passes: USB-C ground, charger/system bus, high-side protection FETs, current-sense resistor, and SRP/SRN polarity all match the corrected battery-protection intent.
- The PCB has been rerouted after the Q1/Q2 footprint swap and the GND zone has been refilled.
- DRC currently reports 40 known non-connectivity items and 0 unconnected pads/items.
- JLC assembly still needs confirmed selections for `R49` and `R50`.
- Silkscreen warnings should not normally prevent fabrication.
- Copper, drill, outline, missing-net, and footprint-orientation issues should be treated as critical.

## Battery And Power Safety

This board works with lithium battery packs and charging/protection circuitry. Mistakes can damage hardware or create a safety hazard.

Do not assume a PCB revision is safe just because the schematic opens or the Gerbers generate. Review the battery path, charger configuration, protection FETs, current limits, connector polarity, and pack wiring before connecting real cells.

Use protected cells or a known-good 2S pack during testing. Current-limit the first power-up and verify rails with a meter before plugging in the Hosyond board or radio hardware.

## Project Status

This hardware is still a prototype until assembled boards are tested.

Open work includes:

- Validate the physical PCB after manufacturing.
- Confirm all connector orientations in the assembled board.
- Test the updated firmware GPIO assignments against the first assembled daughterboard.
- Verify 2S battery reporting and charger/fuel-gauge behavior on hardware.
- Confirm the auxiliary ADS1115 inputs and MCP23017 pads behave as expected with real devices attached.
- Test ELRS and ESP-NOW behavior in the finished controller.
- Document assembly steps after the first successful build.

## Contributing

Anubis is meant to be community driven. Contributions are welcome in the form of firmware changes, PCB review, mechanical improvements, documentation, testing notes, alternate part suggestions, and build reports.

If you change the hardware, include enough context for another builder to understand why the change was made. If you change the firmware, document the pin assumptions and hardware revision you tested against.

## Companion Project

The firmware and receiver-side code for the broader Anubis controller project are hosted with the main project:

```text
https://github.com/BoomBoxRobotics/Anubis
```

This daughterboard is one hardware path toward that larger goal: a capable open source RC controller that builders can actually understand, repair, and make their own.

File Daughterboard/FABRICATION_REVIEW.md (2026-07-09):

# Daughterboard Fabrication Review (v2)

Evaluated: 2026-07-09 · Project: `Daughterboard/daughterboard.kicad_pcb` (KiCad 10.0.3) · Package reviewed: `fabrication/jlcpcb_2026-07-06_r12/` (exported 2026-07-08 03:45)

**Verdict: do NOT order r12.** The package is well-constructed — complete 4-layer Gerber set with paste layers, nested JLCPCB upload zip, single-sided CPL, fully LCSC-matched BOM, and DRC/ERC reports bundled in — but it is **stale**, carries **6 real DRC clearance errors**, and the design doc's own **FET power-path release gate** is still open. A fresh r13 export after the fixes below is the path to ordering.

## Board summary

- 4-layer, 155.1 × 80.8 mm, 1.6 mm FR4, rounded-rectangle outline with a 41 mm filleted notch.
- Single-sided SMD assembly: 108 top-side placements in the CPL; bottom paste layer is empty.
- Hand-soldered exceptions (by design): 18650 holders, 2× Pololu #2808 switch modules, deep-sleep header, Hosyond wire pads.
- Drill: 231 plated holes, min 0.30 mm, plus 4× 0.6 mm slots — all within JLCPCB 4-layer capability.
- ERC: 0 errors, 0 warnings.

## Blockers (fix before ordering)

1. **r12 is stale.** The PCB was edited *after* the r12 export: package exported 2026-07-08 03:45; commit `1a8d2fb` changed `daughterboard.kicad_pcb` (+291/−178 lines) at 06:22 the same morning. The committed Gerbers do not reflect the current board. Any order must come from a fresh export (r13). *Superseded by design: run `scripts\pcb-release.ps1 -Rev r13` once items 3–4 are settled.*
2. ~~**6 DRC clearance errors around U1 (BQ25887 charger).**~~ **Resolved 2026-07-09:** the violations were the VQFN-24 footprint's intrinsic 0.20–0.225 mm pad-to-exposed-pad spacing against the project's 0.25 mm rule (JLCPCB's 4-layer capability is ~0.127 mm, so no fab risk). `daughterboard.kicad_dru` now scopes a deliberate 0.19 mm minimum to items touching U1; DRC + schematic parity passes clean.
3. **Open power-path release gate — first-pass review done 2026-07-09, rework required.** See `q1_power_path_review.md`: the BQ28Z610 is a high-side FET-drive device but the board implements Q1 low-side with the sense resistor in parallel; the charger bypasses the FETs; USB-C pin A12 is mis-netted to the FET midpoint. Protection is non-functional as wired. Net-level rework plan is in that document; PT8810 pinout/VGS verification remains open.
4. **No mounting holes.** 0 NPTH holes, largest PTH is 1.02 mm, and the Edge.Cuts outline contains only corner fillets and the notch — nothing a standoff screw can pass through. The README says the Hosyond board sits above this board on standoffs; confirm the mechanical plan (shell captive mounting?) or add mounting holes before r13.

## Secondary items (cheap to fix in the same spin)

5. ~~**Board metadata.**~~ **Resolved 2026-07-09:** title block added to the board (rev "r13", dated) and stackup copper finish set to HAL lead-free; both verified to flow into the exported `.gbrjob`.
6. **BOM open verifications** (flagged in the BOM's own AssemblyNote column): L1 body vs `L_APV_ANR4020` footprint; L3 ANR5040 dimensions; U5/U6 ADS1115IDGSR are VSSOP-10 at JLC vs the TSSOP-10-class KiCad footprint (same 3×3 mm 0.5 mm-pitch class, but verify).
7. **Silkscreen warnings** (32 of the 38 DRC findings): text heights 0.65–0.7 mm vs the 0.8 mm project rule, some overlapping reference fields, and silk clipped by solder mask. Cosmetic — JLCPCB will print them fine — but small text may be illegible.
8. ~~**Stale BOM ref C8.**~~ **Resolved 2026-07-09:** removed from the r12 JLC BOM draft (the carry-forward source); BOM/CPL gate now reconciles 108 = 108.

## Settled design intent (context for reviewers)

- ADS1115 ALERT/RDY pins (U5/U6 pin 2) are **deliberate no-connects** — firmware polls over I2C at 0x48/0x49.
- Pololu #2808 ON/OFF pads are **deliberately unused** — rail control is via CTRL nets (`CTRL_5V_SW` ← GPIO2, `CTRL_3V3_SW` ← GPIO3); each module's own pushbutton remains usable.
- GPIO14/GPIO21 form the two-pin deep-sleep/wake button header.

## Reusable tests (implemented 2026-07-09)

Both scripts exist and are verified against this project — see `scripts/README.md` for usage. KiCad 10.0.4 is installed on the dev machine (`winget install KiCad.KiCad`; found via `Resolve-KicadCli` in `scripts/_common.ps1`).

- **`scripts/pcb-check.ps1`** — six release gates: ERC; DRC + schematic parity; Gerber/drill freshness (re-export and diff, ignoring timestamp/version headers — this gate confirmed the r12 staleness: 7 layers differ from the current board, while edge cuts, drill, silks, and bottom paste are unchanged); package integrity (all layers present, upload zip matches loose files); fab metadata (revision/finish set); BOM/CPL consistency. Exits nonzero on any failure.
- **`scripts/pcb-release.ps1 -Rev r13`** — builds a complete `fabrication/jlcpcb_<date>_<rev>/` package (gerbers, drill + map, ERC/DRC reports, position file, JLC CPLs, JLC BOM carried forward with a designator reconcile report), zips it, and gates it with `pcb-check.ps1`. It refuses to bless a package that fails any gate.

Running the gates against r12 also surfaced one BOM data issue not in the list above: **C8 is in the JLC BOM (100 nF row, qty 6) but no longer exists on the board** — drop it from the BOM row (and quantity) when cutting r13.

---

*The earlier review of the superseded v1 prototype board lives at `Hosyond_apr24b/Daughterboard/FABRICATION_REVIEW.md`.*

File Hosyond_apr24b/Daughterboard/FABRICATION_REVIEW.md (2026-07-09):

# Daughterboard Fabrication Review — SUPERSEDED

**This review (2026-07-09) evaluated the v1 prototype board in `Hosyond_apr24b/Daughterboard/daughterboard/`, which has been superseded by the redesigned board at the repository top level.**

➡ **Current review: [`Daughterboard/FABRICATION_REVIEW.md`](../../Daughterboard/FABRICATION_REVIEW.md)**, covering the v2 4-layer JLCPCB-assembly design and its `fabrication/jlcpcb_2026-07-06_r12/` package.

## v1 findings (archived)

The v1 board was a 2-layer, all-through-hole carrier for off-the-shelf modules (2× ADS1115, 2× Pololu #2808, charger module). Its 2026-05-28 Gerber package was structurally sound: complete layer set, clean DRC/ERC apart from the items below, conservative geometry, mounting holes as Edge.Cuts circles.

Open items at time of review, now resolved by the v2 redesign:

- **Unrouted ALRT/ON/OFF nets** (11 DRC unconnected-pad errors). Settled intent, confirmed in the v2 netlist and `Daughterboard/power_board_design.md`: ADS1115 ALERT/RDY pins are deliberate no-connects (firmware polls I2C); Pololu ON/OFF pads are deliberately unused (rail control via CTRL from GPIO2/GPIO3). The v1 labels were leftovers of that same intent.
- Revision/finish metadata unset — still applies to v2, tracked there.
- No regeneration/staleness test — the reusable test plan moved to the v2 review.

Do not fabricate this board; it is kept for reference only.

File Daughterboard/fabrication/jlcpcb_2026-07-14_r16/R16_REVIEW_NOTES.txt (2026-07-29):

ANUBIS DAUGHTERBOARD R16 FABRICATION REVIEW
Generated: 2026-07-14

RELEASE STATUS
- PCB DRC: 0 errors and 0 unconnected items.
- Schematic ERC: 0 violations.
- Schematic-to-PCB parity: no reported mismatches.
- Remaining PCB DRC items are non-blocking silkscreen/text warnings only:
  17 silkscreen-over-copper, 13 text-height, and 8 silkscreen-overlap warnings.

R16 HARDWARE
- Four copper layers: F.Cu, In1.Cu, In2.Cu, and B.Cu.
- BATT_RAW_P J7.3-to-F4.2 route is 1.0 mm throughout with 1.0/0.5 mm power vias.
- BATT_RAW_P F3.2-to-F4.2 route is 1.0 mm throughout.
- FET_BATT_P and FET_SRC_COMMON routes are 1.0 mm throughout with 1.0/0.5 mm vias.
- The narrow BATT_RAW_P branches are limited to voltage-sense and test-point connections.
- USB-C ground pins and shield are on GND.
- Charger BAT/SNS pins connect to protected BAT_SYS.
- R46 is series-connected between BATT_RAW_N and GND.
- Q1/Q2 use the CSD18502Q5B common-source high-side protection topology.
- BQ28Z610 SRP/SRN polarity matches the intended current-sense convention.

R16 JLCPCB FOOTPRINT/PART UPDATES
- L1: CKST0402-4.7uH/M, C3002596, matched to the current R16 footprint.
- L2: MDA4020-4R7M, C2847471, matched to the current R16 footprint.
- U2: BQ28Z610DRZR-R1, C2876556, TI DRZ 12-pin SON footprint.
- Q1/Q2: CSD18502Q5B, C473915, TI DNK/VSON-CLIP footprint.
- R49/R50 remain existing 10M gate-source bleed resistors. The assembly BOM maps
  them to 0603WAF1005T5E, JLCPCB C7250. No PCB component was added or moved.
- J5 remains the existing straight 1x4 2.54mm through-hole header and maps to
  X6511WV-04H-C60D30, JLCPCB C706876.
- J6 remains the existing straight 1x2 2.54mm through-hole header and maps to
  P6E02A-002550-B1P, JLCPCB C49375797.
- C8 remains the existing optional CBSET filter footprint and is marked DNP on
  the PCB. It is intentionally excluded from both the JLC assembly BOM and CPL.

UPLOAD FILES
- Upload Daughterboard_jlcpcb_gerber_drill.zip for PCB fabrication.
- Upload assembly/Daughterboard_jlcpcb_bom_template_filled.csv as the assembly BOM.
- Upload assembly/Daughterboard_jlcpcb_cpl.csv as the component placement file.

FINAL ORDER-SCREEN CHECK
- Confirm a four-layer stackup is selected.
- Confirm JLC recognizes both plated and non-plated drill files if separate files are shown.
- Review orientation markers for U1, U2, Q1, Q2, D4-D7, and all polarized connectors.
- Confirm every intended assembly BOM line is matched before payment.

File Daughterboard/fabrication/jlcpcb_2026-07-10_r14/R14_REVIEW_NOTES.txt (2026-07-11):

R14 fabrication package - 2026-07-10
Review notes updated - 2026-07-11

Major R14 changes:
- Q1 and Q2 changed to TI CSD18502Q5B using project-local DNK/VSON-CLIP footprint.
- Q1/Q2 JLC/LCSC part number is C473915.
- PCB was rerouted after the Q1/Q2 footprint swap.
- GND copper zone was refilled before DRC and Gerber export.

Stock-availability substitutions:
- R9 and R12 use RMC0603100K1%N, 100k 1% 0603, JLC/LCSC C269699.
  This replaces TD03H1003BT / C2961368 because of the available-stock shortfall.
- R42, R43, and R44 use RCT0310KFLF, 10k 1% 0603, JLC/LCSC C177644.
  This replaces 0603WAF1002T5E / C25804 because of the available-stock shortfall.
- Both substitutions retain the original resistance, tolerance, and 0603 footprint, so no PCB placement or routing change was required.
- The replacement LCSC numbers are present in the R14 JLCPCB BOM CSV/XLSX and part-audit files.

Checks:
- ERC: 0 errors, 0 warnings.
- R14 power topology audit: PASS.
- DRC: 40 non-connectivity violations, 0 unconnected pads/items.

Known DRC items:
- 6 U1 clearance items around the BQ25887 footprint, approximately 0.200-0.225 mm vs the 0.250 mm configured rule.
- Remaining items are silkscreen/text height/overlap or silkscreen-over-copper warnings.

Assembly notes:
- Q1/Q2 are selected as CSD18502Q5B, JLC/LCSC C473915.
- R9/R12 are selected as C269699; R42/R43/R44 are selected as C177644.
- Missing-parts report still lists J5/J6 through-hole headers and R49/R50 10M gate-source bleed resistors.
- If J5/J6 are not being assembled by JLC, remove them from the assembly upload or mark them user-installed.

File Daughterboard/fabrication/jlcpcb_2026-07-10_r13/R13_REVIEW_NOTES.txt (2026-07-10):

Anubis daughterboard R13 review package
Generated: 2026-07-10

Primary change from R12:
- The BQ28Z610 protection section was rewired from the incorrect low-side FET arrangement to a high-side N-FET protection path.
- Q1 and Q2 are now CSD16412Q5A high-side protection FETs.
- Charger BAT/SNS and downstream regulators now use protected BAT_SYS.
- R46 is the series low-side current-sense resistor between BATT_RAW_N and GND.
- USB-C A12/B12/shield are on GND.

Validation summary:
- ERC: 0 violations.
- DRC: 38 violations, 0 unconnected items.
- Known copper DRC items are local U1 clearance deltas around 0.20 mm to 0.225 mm versus the configured 0.25 mm rule.
- Remaining non-copper items are silkscreen/text warnings.
- R13 power-topology audit: PASS.

Assembly notes:
- JLC BOM/CPL files are in the assembly folder.
- Gerber/drill upload zip is Daughterboard_jlcpcb_gerber_drill.zip.
- Four assembly rows still need JLC part confirmation before final assembly upload:
  - Q1, Q2: CSD16412Q5A high-side protection FETs.
  - R49, R50: 10M 0603 gate-source bleed resistors.
- See reports/Daughterboard_r13_missing_jlc_parts.csv.

Critical review focus:
- Confirm Q1/Q2 footprint and pin orientation against the selected JLC-available FET.
- Confirm U1, U2, JST connectors, USB-C, and D4-D7 orientations in the JLC assembly preview.
- Confirm JLC accepts the known U1 clearances or adjust the local routing/rules before ordering.

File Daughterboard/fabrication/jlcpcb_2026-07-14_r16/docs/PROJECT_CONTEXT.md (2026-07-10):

# Project Context - Hosyond ESP32-S3 Daughterboard

Last updated: 2026-07-10

## Project Goal

This project is a custom daughterboard/carrier PCB for a Hosyond 2.8 inch ESP32-S3 display/dev board. The daughterboard replaces loose wiring with a compact board that provides battery charging/protection, switched 5 V and 3.3 V rails, UART/I2C/GPIO breakouts, onboard analog/digital expanders, and connectors for radio-control hardware such as ELRS, gimbals, D-pad/buttons, and auxiliary inputs.

The daughterboard should be manufactured and assembled offsite by JLCPCB as completely as possible. The main exception is the Pololu mini pushbutton power switch modules, which are installed separately on raised headers. Most passive parts, ICs, and connectors should be SMD/JLC-available where practical. Through-hole/user-installed headers are acceptable where the design intentionally needs them.

## Workspaces

Current daughterboard hardware workspace:

```text
C:\Users\Avala\OneDrive\Desktop\Daughterboard
```

Previous/main controller firmware workspace:

```text
C:\Users\Avala\OneDrive\Desktop\sketch_may7a
```

The previous project is about the main Hosyond ESP32-S3 board, its firmware, UI, protocol behavior, and controller functionality. A current copy of the daughterboard folder has also been placed inside that project at:

```text
C:\Users\Avala\OneDrive\Desktop\sketch_may7a\Daughterboard
```

Older carrier-board planning docs from the previous project are under:

```text
C:\Users\Avala\OneDrive\Desktop\sketch_may7a\project_anubis\Daughterboard
```

Those older docs are useful historical context, but they describe an earlier module-carrier version using a protected 1S pack and PCF8575/ADS1115 modules. The current design has moved to a 2S battery architecture and more onboard components.

## Current Daughterboard State

Primary KiCad files:

```text
Daughterboard.kicad_pro
Daughterboard.kicad_sch
Daughterboard.kicad_pcb
Daughterboard.kicad_sym
Daughterboard.net
Daughterboard.pretty\
```

Important custom footprints:

```text
Daughterboard.pretty\BQ28Z610_DRZ0012A_12SON_2.5x4mm_P0.5mm.kicad_mod
Daughterboard.pretty\Pololu_2808_Raised_Header.kicad_mod
Daughterboard.pretty\SOIC-28W_7.5x17.9mm_P1.27mm_NoPads11_14.kicad_mod
Daughterboard.pretty\SOT-23-6_NoPad6.kicad_mod
```

Current routed fabrication package:

```text
fabrication\jlcpcb_2026-07-10_r13.zip
fabrication\jlcpcb_2026-07-10_r13\
```

R13 assembly files:

```text
fabrication\jlcpcb_2026-07-10_r13\assembly\Daughterboard_jlcpcb_bom_template_filled.csv
fabrication\jlcpcb_2026-07-10_r13\assembly\Daughterboard_jlcpcb_bom_template_filled.xlsx
fabrication\jlcpcb_2026-07-10_r13\assembly\Daughterboard_jlcpcb_cpl.csv
fabrication\jlcpcb_2026-07-10_r13\Daughterboard_jlcpcb_gerber_drill.zip
```

J5 and J6 are intentionally through-hole/user-installed headers and are excluded from the JLC SMT BOM/CPL unless JLC through-hole assembly is explicitly used.

R13 topology update:

- `Daughterboard.kicad_sch`, `Daughterboard.net`, and `Daughterboard_pcb_bom.csv` now describe the corrected high-side BQ28Z610 protection topology.
- `Daughterboard.kicad_pcb` has been updated for R13 with the old single Q1 low-side footprint replaced by Q1/Q2 `CSD16412Q5A`, and R49/R50/C32/C33/TP13 added.
- The PCB has been rerouted after the R13 topology change.
- Backup before the R13 PCB staging is `Daughterboard.pre_r13_topology_backup.kicad_pcb`.

R14 working update:

- R14 swaps Q1/Q2 from `CSD16412Q5A` to JLC-available TI `CSD18502Q5B`, JLC/LCSC `C473915`.
- The schematic now uses a real 1-8 pin `CSD18502Q5B` symbol: pins 1-3 source, pin 4 gate, pins 5-8 drain.
- The PCB now uses project-local footprint `Daughterboard:CSD18502Q5B_DNK0008A_VSON-CLIP_5x6mm` for Q1/Q2.
- Routed traces/vias were intentionally cleared for the Q1/Q2 footprint swap, then the board was rerouted for R14.
- Zones were refilled after the R14 reroute.
- R14 ERC is clean: 0 violations in `r14_post_route_erc.rpt`.
- R14 topology audit passes in `verify_r14_power_topology.py`.
- R14 DRC currently reports 40 non-connectivity violations and 0 unconnected pads/items in `r14_post_route_drc.rpt`.
- Backup before the R14 swap is `Daughterboard.pre_r14_csd18502_swap.kicad_pcb` and `Daughterboard.pre_r14_csd18502_swap.kicad_sch`.

## Power Architecture

The daughterboard is intended to run from installed batteries. The current design supports a 2S battery connection through a standard 2S LiPo balance lead, so users can use either a 2S LiPo pack or two 18650 cells configured as a 2S pack.

Original charging target:

- USB-C input: 5 V
- Charge current: 500 mA minimum target, 1.5 A maximum
- 5 V switched rail: about 1 A max
- 3.3 V switched rail: about 500 mA max

Current direction:

- 2S battery management/protection moved away from the unavailable `S-8252AAH-M6T1U`.
- `BQ28Z610DRZR-R1` was added as the major 2S battery gauge/protection/management IC.
- R13 rewired the BQ28Z610 protection topology from the old incompatible low-side FET path to a high-side N-FET path. R14 keeps that topology and uses two `CSD18502Q5B` FETs: `Q1` charge FET and `Q2` discharge FET.
- Raw cell-stack positive is now `BATT_RAW_P`; protected/system positive is `BAT_SYS`.
- `R46` is now documented as a true series current-sense resistor between raw cell negative `BATT_RAW_N` and protected/system `GND`.
- USB-C ground pins `A12`, `B12`, and shield are on `GND`; the old accidental `Q1_DRAIN_COMMON` net was removed from the generated schematic/netlist.
- USB-C VBUS and CC resistors are on the board. CC resistors were placed close to the USB-C port.
- B.Cu has a GND copper zone/ground plane.
- Power/high-current nets such as battery, charge, 5 V, switched 5 V, 3.3 V, and switched 3.3 V were assigned wider routing rules during layout.

Known firmware integration note:

- The firmware still has 1S battery voltage assumptions in places: empty/full around 3.30 V to 4.20 V and divider ratio 2.0.
- The hardware is now 2S. Firmware battery measurement, warnings, fuel-gauge integration, and any ADC divider expectations must be reviewed before relying on battery display/protection behavior.

## Switched Rails and Pololu Modules

The design incorporates two Pololu mini pushbutton power switch modules, Pololu product 2808:

- One switches the 5 V output rail.
- One switches the 3.3 V output rail.

The intent from the daughterboard design thread:

- `GPIO2` controls one Pololu switch.
- `GPIO3` controls the other Pololu switch.
- `GPIO14` and `GPIO21` route to the deep-sleep/wake pushbutton header `J6`.

Current firmware assignment:

- `GPIO2` drives the 5 V Pololu switch control path.
- `GPIO3` drives the 3.3 V Pololu switch control path.
- `GPIO14` is the deep-sleep/wake button sense pin.
- `GPIO21` is the deep-sleep/wake button reference pin.
- The old GPIO14/GPIO21 power LED behavior is disabled so it does not conflict with `J6`.

The UART-to-ELRS pinout remains similar to earlier notes: if the board pin order does not match a given ELRS module harness, it can be manually wired/crossed later.

## Signal and Connector Map

Hosyond ESP32-S3 board interface:

- I2C SDA: firmware currently uses GPIO16.
- I2C SCL: firmware currently uses GPIO15.
- ELRS/UART default pins: firmware uses TX GPIO44 and RX GPIO43, with auto/swap handling.
- Battery ADC: firmware currently uses GPIO9.

Primary daughterboard connector intent:

- UART from Hosyond TX/RX routes to a 5-pin 1.25 mm JST-GH top-entry connector with `+5V_SW` and GND.
- I2C SDA/SCL routes to a 4-pin 2.54 mm through-hole header `J5` with `+3V3_SW` and GND.
- `J6` is a 2-pin 2.54 mm through-hole header for a pushbutton/deep-sleep signal path.
- Gimbal connectors were split so each gimbal has two 3-wire JST connections: GND, analog input, and `+3V3_SW`.
- Remaining analog/GPIO breakout signals were moved to labeled test pads/solder pads where full connectors were not needed.

Connector notes:

- `J4` uses top-entry `BM05B-GHS-TBT(LF)(SN)(N)` style connector for the 5-pin JST-GH output.
- `J7` is the 2S balance connector, using a JST-XH style part such as `S3B-XH-A(LF)(SN)`.
- `J5` and `J6` were corrected to through-hole 2.54 mm headers and remain that way in the R13 fabrication outputs.

## Onboard I2C and Analog Devices

The board includes onboard components instead of relying on plug-in ADS1115/PCF modules:

- Two `ADS1115` ADC circuits for about 8 analog inputs.
- One `MCP23017` GPIO expander circuit.
- ADS1115s, MCP23017, attached analog devices, and other 3.3 V peripherals are powered from `+3V3_SW`, so powering down the switched 3.3 V rail shuts them off.
- ESD arrays D4-D7 were updated to use the JLC-selected SRV05-style SOT-23-6 part. The verified pinout is:
  - IO pins: 1, 3, 4, 6
  - GND: pin 2
  - `+3V3_SW_LOGIC`: pin 5

Firmware currently expects:

- Primary ADS1115 at I2C address `0x48` for stick axes.
- Auxiliary ADS1115 at I2C address `0x49` for spare analog inputs.
- MCP23017 fixed at I2C address `0x20`.
- MCP23017 active-low D-pad mapping on low GPIO bits:
  - select: bit 0
  - left: bit 1
  - up: bit 2
  - down: bit 3
  - right: bit 4

Firmware caution:

- If switched `+3V3_SW` removes power from the I2C devices while SDA/SCL remain connected, firmware and hardware should account for possible back-powering through I2C lines. ESD/protection and bus behavior should be checked.

## Main Firmware Context

Main sketch:

```text
C:\Users\Avala\OneDrive\Desktop\sketch_may7a\Hosyond_apr24b\Hosyond_apr24b.ino
```

The firmware is a large Hosyond ESP32-S3 transmitter/controller application. It includes:

- TFT/touch UI using `TFT_eSPI` and FT6336U touch.
- Model storage and settings.
- Stick calibration, expo/rates, trims, endpoints, failsafe, drive type, and mixing.
- Protocol selection between ELRS/CRSF and ESP-NOW.
- ELRS module support on `Serial1`, with default pins TX GPIO44 and RX GPIO43, auto/swap logic, and 5,250,000 baud CRSF handling.
- ESP-NOW transmitter support and receiver/bind handling.
- Dual ADS1115 support for the daughterboard ADCs at `0x48` and `0x49`.
- MCP23017 GPIO expander support at `0x20`.
- Battery display, warnings, and auto deep-sleep behavior.
- Display backlight and audio support.

Important current firmware defines:

```text
POWER_BUTTON_SENSE_PIN 14
POWER_BUTTON_REF_PIN   21
POWER_LED_ENABLED      false
UART_5V_ENABLE_PIN     2
I2C_3V3_ENABLE_PIN     3
BATTERY_ADC_PIN        9
I2C_SDA_PIN            16
I2C_SCL_PIN            15
ADS1115 primary/aux    0x48 / 0x49
MCP23017 address       0x20
ELRS default TX/RX     44/43
```

There is also an ESP-NOW receiver sketch in:

```text
C:\Users\Avala\OneDrive\Desktop\sketch_may7a\ESPNow_S3_Receiver
```

## Mechanical Context

The current daughterboard outline is based on:

```text
daughterboard2.dxf
Daughterboardv2.step
```

The board is a wide, notched shape that fits around/under the Hosyond board. The Hosyond board sits above the daughterboard on standoffs, roughly 20 mm above the daughterboard. The upper gap/center area receives the Hosyond board. The USB-C connector is intended to sit in the center island/strip between the two halves.

Placement intent from layout work:

- UART near the left side of the Hosyond gap.
- GPIO and I2C near the right side of the Hosyond gap.
- UART output near the lower center strip.
- Power management/protection mostly on the left side.
- I2C circuits and analog/GPIO expansion mostly on the right side.
- Gimbal connectors near the gimbal wire exits.

RadioMaster Pocket/Zorro X5 gimbal reference work:

- Center circle where the stick emerges: about 37 mm diameter.
- Mounting hole spacing: about 32.9 mm by 30 mm center-to-center.
- Mounting plate: about 39 mm wide, 41 mm at the bump, by 35 mm tall.
- Bottom of gimbal to top of stick: about 43 mm.
- Reference images and generated fit models are retained in the workspace.

## Fabrication and Checks

R13 fabrication outputs were generated after:

- Converting the PCB to 4 layers.
- Updating J5/J6 to through-hole 2.54 mm headers.
- Updating D4-D7 to the normal 6-pad SOT-23-6 ESD footprint.
- Reworking the `BQ28Z610` protection circuit into the corrected high-side FET topology.
- Rebuilding Gerbers, drill files, JLC BOM/CPL files, validation reports, and `fabrication\jlcpcb_2026-07-10_r13.zip`.

Latest known checks from R13:

- ERC: 0 errors, 0 warnings.
- DRC: 38 reported violations.
- Unconnected pads/items: 0 reported in the final checked state before packaging.
- R13 topology audit: PASS.
- The remaining DRC items are accepted/known items:
  - U1 clearance differences, roughly 0.20 mm to 0.225 mm versus a 0.25 mm rule.
  - Silkscreen/text-size/overlap warnings that should not normally block fabrication.
- In the active R14 working files, Q1/Q2 are selected as `CSD18502Q5B`, JLC/LCSC `C473915`.
- JLC assembly still needs confirmed selections for `R49` and `R50`, the 10M 0603 gate-source bleed resistors.

Manufacturing caution:

- Before ordering, re-run KiCad DRC/ERC after any manual edits, refill zones, and regenerate fabrication files.
- Silkscreen issues are usually non-critical, but copper clearance, drill, board outline, missing nets, and footprint orientation issues should be treated as critical.
- Check JLC part availability again before final ordering, because stock and part lifecycle status can change.

## BOM and Part Selection Notes

Current major JLC/assembly direction:

- Use JLC-available SMD components wherever possible.
- Keep 1.25 mm/2.54 mm JST or pin headers as chosen unless there is a specific layout/manufacturing reason to change.
- Non-component items such as test pads and solder pads should be placed at the bottom of any human-facing BOM or excluded from assembly upload.

Notable parts/substitutions from the design thread:

- `BQ28Z610DRZR-R1` replaced the unavailable/minimum-order-problem `S-8252AAH-M6T1U` direction.
- R13 replaced the old `CSD83325L`/`PT8810` low-side FET position with two high-side protection FETs. R14 changed those FETs to `CSD18502Q5B` so JLCPCB can assemble Q1/Q2 using an in-stock part.
- `C2012X5R1C226M125AC` substituted for `GRM21BR61C226ME44L`.
- `BM05B-GHS-TBT(LF)(SN)(N)` selected for the top-entry 5-pin JST-GH connector.
- `S3B-XH-A(LF)(SN)` style part used for the 2S balance connector.
- `BSMD1206-200-16V` used for F1-F4 in the JLC audit.

Useful BOM files:

```text
Daughterboard_pcb_bom.csv
Daughterboard_current_jlc_part_audit.csv
fabrication\jlcpcb_2026-07-10_r13\assembly\Daughterboard_jlcpcb_bom_template_filled.csv
fabrication\jlcpcb_2026-07-10_r13\assembly\Daughterboard_jlcpcb_cpl.csv
```

## Open Integration Items

1. Update firmware for the 2S battery system:
   - ADC divider/scaling.
   - Battery full/empty/warning thresholds.
   - Whether to read `BQ28Z610` over I2C/SMBus or keep separate analog battery sensing.

2. Confirm daughterboard I2C behavior on first hardware:
   - Primary ADS1115 at `0x48` feeds the four stick axes.
   - Auxiliary ADS1115 at `0x49` feeds spare analog inputs, with AIN4/AIN5 mapped into CH5/CH6.
   - MCP23017 at `0x20` replaces the old PCF8575-style GPIO path.

3. Confirm JLC orientation before ordering:
   - Especially U1/BQ25887, U2/BQ28Z610, Q1/Q2/CSD18502Q5B, USB-C, JST connectors, and ESD arrays.
   - KiCad pin 1 marker orientation and JLC preview orientation can look different depending on rotation convention, so use pad numbering and datasheets, not only the visual corner.

4. Re-run DRC/ERC and regenerate fabrication files after every footprint, placement, routing, or BOM-impacting change.

## Useful Reference Files

Daughterboard hardware:

```text
power_board_design.md
S8252_E.pdf
SRV05-4-TCT_C13612_actual.pdf
SRV05-4-TCT_C13612_datasheet.pdf
JLCPCB_BOM_Template.xls
update_jlc_footprint_migration.ps1
```

Mechanical/gimbal:

```text
daughterboard2.dxf
Daughterboardv2.step
radiomaster_x5_gimbal_fit_model.step
radiomaster_x5_gimbal_fit_model.stl
fusion360_x5_gimbal_model.py
x5Front.webp
x5Side1.webp
x5Side2.webp
x5Side3.jpg
x5Bottom.webp
x5dimensions.webp
```

Older previous-project context:

```text
C:\Users\Avala\OneDrive\Desktop\sketch_may7a\project_anubis\Daughterboard\Hosyond_carrier_block_diagram.md
C:\Users\Avala\OneDrive\Desktop\sketch_may7a\project_anubis\Daughterboard\Hosyond_carrier_connector_inventory.csv
C:\Users\Avala\OneDrive\Desktop\sketch_may7a\project_anubis\Daughterboard\Hosyond_carrier_net_table.csv
C:\Users\Avala\OneDrive\Desktop\sketch_may7a\project_anubis\Daughterboard\Hosyond_carrier_mechanical_constraints.md
```

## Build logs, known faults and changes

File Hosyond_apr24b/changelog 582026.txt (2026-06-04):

changelog 5/8/2026

|-|-|-|-|-|-|-|-|-|-|-|-|-|-|-|-|-|-|-|-|-|-|-|-|-|-|-|-|-|-|-|-|-|-|-|-|-|-|-|-|-|-|-|-|-|-|-|-|-|-|-|-|-|-|-|-|-|-|-|-|-|-|-|-|-|-|-|-|-|-|

I wired the Mixing button to a new mixing editor screen, and added the screen rendering/update flow. The first-pass UI gives each model 4 mix slots with Enable, Source, Destination (Dest), Rate, and Offset. You can tap M1-M4 tabs to switch mix slots, tap source/destination to cycle channels, and use +/- for rate and offset. I also made the mix settings persist per model by storing them in the existing model data structure.

I treated this as a UI-first transmitter-style mixer editor, so the data model is there now, but it does not yet drive any actual output math. I assumed a simple 5-channel, 4-mix-slot setup as a good first shape.

|-|-|-|-|-|-|-|-|-|-|-|-|-|-|-|-|-|-|-|-|-|-|-|-|-|-|-|-|-|-|-|-|-|-|-|-|-|-|-|-|-|-|-|-|-|-|-|-|-|-|-|-|-|-|-|-|-|-|-|-|-|-|-|-|-|-|-|-|-|-|

I added the Mixing numpad. Tapping the numeric Rate or Offset value box now opens a compact pad above the footer with 0-9, -, and OK, plus a text box at the top that shows the value being entered. Tapping anywhere above the pad dismisses it without committing, and OK commits the typed value to the selected mix field.

I left the existing +/- tick buttons in place, so you now have both quick nudging and direct entry. The typed value is constrained to -100 through 100

|-|-|-|-|-|-|-|-|-|-|-|-|-|-|-|-|-|-|-|-|-|-|-|-|-|-|-|-|-|-|-|-|-|-|-|-|-|-|-|-|-|-|-|-|-|-|-|-|-|-|-|-|-|-|-|-|-|-|-|-|-|-|-|-|-|-|-|-|-|-|-

I added the Aa shift key to the model-name keyboard, and it now toggles the alphabet rows between uppercase and lowercase while leaving numbers and special keys alone. I also set the startup default model name to Anubis for the primary slot if it’s blank, and changed new/reset mix defaults so Rate and Offset both start at 0.

Because the mix defaults changed, I bumped the mix storage version, so on first boot after flashing this build the saved mix slots will be reset once to pick up the new 0 / 0 defaults.

|-|-|-|-|-|-|-|-|-|-|-|-|-|-|-|-|-|-|-|-|-|-|-|-|-|-|-|-|-|-|-|-|-|-|-|-|-|-|-|-|-|-|-|-|-|-|-|-|-|-|-|-|-|-|-|-|-|-|-|-|-|-|-|-|-|-|-|-|-|-|

I added the press-and-hold rename behavior to the model list
The behavior is now:

tap a saved slot: selects that model like before
press and hold a saved slot for about 700 ms: opens the keyboard with that slot’s current name preloaded so you can edit it
tap an empty slot: still opens naming immediately

I implemented it with a small pending hold state so it doesn’t interfere with the normal release handling

|-|-|-|-|-|-|-|-|-|-|-|-|-|-|-|-|-|-|-|-|-|-|-|-|-|-|-|-|-|-|-|-|-|-|-|-|-|-|-|-|-|-|-|-|-|-|-|-|-|-|-|-|-|-|-|-|-|-|-|-|-|-|-|-|-|-|-|-|-|-|

Drive Type is now saved per model slot and restored when you switch models, just like reverse, trim, failsafe, and mixing.

One important nuance: the actual storage key is still the model slot (Model 1-Model 4), and the model name is the label attached to that slot. So when the user selects Model 1, all of that slot’s saved data now comes back together:

reverse switch states
trim values
failsafe switch states
mixing data
drive type

I also added boot-time sanitizing for old saved drive-type values so existing EEPROM data won’t leave the drive type in a bad state.

|-|-|-|-|-|-|-|-|-|-|-|-|-|-|-|-|-|-|-|-|-|-|-|-|-|-|-|-|-|-|-|-|-|-|-|-|-|-|-|-|-|-|-|-|-|-|-|-|-|-|-|-|-|-|-|-|-|-|-|-|-|-|-|-|-|-|-|-|-|-|

Symptom - top bar is not updating on any screen other than MAIN_SCREEN.

The issue was that the top bar only updates when uiNeedsRedraw is set, and the non-main screens don’t naturally trigger redraws very often. I added a small periodic redraw tick for non-main screens (250ms), so the RSSI bars and battery icon now refresh there too instead of only animating on the main screen.

|-|-|-|-|-|-|-|-|-|-|-|-|-|-|-|-|-|-|-|-|-|-|-|-|-|-|-|-|-|-|-|-|-|-|-|-|-|-|-|-|-|-|-|-|-|-|-|-|-|-|-|-|-|-|-|-|-|-|-|-|-|-|-|-|-|-|-|-|-|-|

The trim trail fix was redrawing the graph area but not the trim buttons afterward, so the + / - controls were getting painted over. I split the trim rendering into:

a graph-base redraw helper
a trim-button redraw helper
Now the dynamic trim update restores both before drawing the moving dot, so the trail stays gone and the buttons remain visible.

|-|-|-|-|-|-|-|-|-|-|-|-|-|-|-|-|-|-|-|-|-|-|-|-|-|-|-|-|-|-|-|-|-|-|-|-|-|-|-|-|-|-|-|-|-|-|-|-|-|-|-|-|-|-|-|-|-|-|-|-|-|-|-|-|-|-|-|-|-|-|

I added D-pad navigation across the UI using only Left, Right, Down, and Select, with Down wrapping everywhere.
What’s covered now:

main menu and settings menus
controller settings
model settings
drive type
reverse
trim
failsafe
model name screen
mixing screen
mixing numpad
the existing keyboard still works with wrap-around Down

I also added focus highlighting on the D-pad path so you can see what’s selected on most of those screens, and I made sure the mixing numpad has a D-pad path to OK as well. The sketch compiles cleanly for esp32s3.

A couple of behavior notes:

on list/button screens, Down cycles through items and wraps
on value screens, Select activates the focused control
on some screens, Left acts as a quick back/jump-back control to make up for having no Up

|-|-|-|-|-|-|-|-|-|-|-|-|-|-|-|-|-|-|-|-|-|-|-|-|-|-|-|-|-|-|-|-|-|-|-|-|-|-|-|-|-|-|-|-|-|-|-|-|-|-|-|-|-|-|-|-|-|-|-|-|-|-|-|-|-|-|-|-|-|-|

D-pad focus highlights now stay hidden until you actually use the D-pad on that screen, and they hide again as soon as you interact by touch or change screens. So the UI won’t open with a highlighted control unless navigation came from the D-pad.

I also added a Tank Control sub-screen under the Tank option in Drive Type. It gives you:

2 Stick: each stick Y axis controls one side
1 Stick: the right stick controls both sides with throttle on Y and turning on X

That setting is saved per model using the same per-model storage path as your other model settings, and the main-screen tank bars now follow that selected tank mode.

|-|-|-|-|-|-|-|-|-|-|-|-|-|-|-|-|-|-|-|-|-|-|-|-|-|-|-|-|-|-|-|-|-|-|-|-|-|-|-|-|-|-|-|-|-|-|-|-|-|-|-|-|-|-|-|-|-|-|-|-|-|-|-|-|-|-|-|-|-|-|

I updated the Reverse screen so enabled mixes now link reverse behavior between channels.
What it does now:

if an enabled mix connects channels, reversing one of those channels reverses the linked channel too
the Reverse screen visually flags linked channels with accent coloring and a *
linked channels also get an extra outline around their toggle, so the relationship is easier to spot

I implemented it as a general linked-channel resolver over the enabled mix graph, so it isn’t limited to only one specific pair.

|-|-|-|-|-|-|-|-|-|-|-|-|-|-|-|-|-|-|-|-|-|-|-|-|-|-|-|-|-|-|-|-|-|-|-|-|-|-|-|-|-|-|-|-|-|-|-|-|-|-|-|-|-|-|-|-|-|-|-|-|-|-|-|-|-|-|-|-|-|-|

I shrank the bottom navigation area in Hosyond_apr24b.ino to about 60% of its old height.
What changed:

footer height went from 60 to 36
bottom nav buttons now use their own smaller height (30) instead of sharing the larger general-purpose button size
touch targets for the footer buttons were updated to match
the trim screen’s BACK/NEXT footer buttons were updated too

That gives you more usable vertical space on the content area without shrinking the larger main menu/settings buttons in the body of the screens.

|-|-|-|-|-|-|-|-|-|-|-|-|-|-|-|-|-|-|-|-|-|-|-|-|-|-|-|-|-|-|-|-|-|-|-|-|-|-|-|-|-|-|-|-|-|-|-|-|-|-|-|-|-|-|-|-|-|-|-|-|-|-|-|-|-|-|-|-|-|-|

I added a per-mix reverse-link switch to the Mixing screen. Each M1-M4 mix now has a Rev Link row with SEP and LINK, and that setting now directly controls the Reverse screen behavior. If a mix is LINK, reversing either channel in that mix will still flip the linked partner(s). If it’s SEP, that mix no longer participates in reverse linking or reverse-menu highlighting.

I kept the saved mix data layout compatible, so existing mixes should keep their current linked behavior by default instead of getting reset. I also shifted the Mixing layout a bit to make room for the new row and updated both touch and D-pad navigation to cover it cleanly.

|-|-|-|-|-|-|-|-|-|-|-|-|-|-|-|-|-|-|-|-|-|-|-|-|-|-|-|-|-|-|-|-|-|-|-|-|-|-|-|-|-|-|-|-|-|-|-|-|-|-|-|-|-|-|-|-|-|-|-|-|-|-|-|-|-|-|-|-|-|-|

I shifted the Mixing screen’s right-side controls left and a bit lower, and I also made the OFF/ON and SEP/LINK labels position themselves relative to the toggle box instead of using fixed screen coordinates. That should stop the text from crowding or overlapping the switches.

|-|-|-|-|-|-|-|-|-|-|-|-|-|-|-|-|-|-|-|-|-|-|-|-|-|-|-|-|-|-|-|-|-|-|-|-|-|-|-|-|-|-|-|-|-|-|-|-|-|-|-|-|-|-|-|-|-|-|-|-|-|-|-|-|-|-|-|-|-|-|

I added audible clicks for button presses and DPAD selections as well as adding a volume icon with touch functions.
What changed:

added a speaker/volume icon in the bottom-right of the main screen
tap the icon: opens/closes a small + / level / - volume popup
press and hold the icon: toggles mute
volume up automatically unmutes
added UI click sounds for touch button presses and D-pad navigation/select actions
I also wired in the ESP32-S3 I2S audio output so the clicks should come out through the board’s speaker path.

The MENU button is shifted left so the volume button has more space, the speaker icon is redrawn as a proper right-facing speaker with sound waves, and the popup slider is much taller now. I also changed the main-screen update path so the volume popup only redraws when its own state changes, like mute, show/hide, or a volume step, instead of repainting on every main-screen frame. Tapping anywhere away from the popup now closes it.

|-|-|-|-|-|-|-|-|-|-|-|-|-|-|-|-|-|-|-|-|-|-|-|-|-|-|-|-|-|-|-|-|-|-|-|-|-|-|-|-|-|-|-|-|-|-|-|-|-|-|-|-|-|-|-|-|-|-|-|-|-|-|-|-|-|-|-|-|-|-|

I wired the battery meter to the board’s real battery ADC on IO9.
What changed:

battery voltage now comes from analogReadMilliVolts(IO9) instead of the old simulated value
I applied the board’s 200k/200k divider from the schematic, so the code converts the ADC reading back to actual battery voltage
if no battery is detected, the top-bar battery icon now shows an X and does not blink
the right panel now shows No Batt instead of a fake voltage
charging state is shown as an overlay on the battery icon and a + next to the voltage readout

One important limitation: this board does not appear to route a dedicated charge-status signal to the ESP32, so “charging” is inferred from the battery voltage rising over time, not from a true charger-status pin. That means the voltage reading is real, but charging detection is best-effort.

|-|-|-|-|-|-|-|-|-|-|-|-|-|-|-|-|-|-|-|-|-|-|-|-|-|-|-|-|-|-|-|-|-|-|-|-|-|-|-|-|-|-|-|-|-|-|-|-|-|-|-|-|-|-|-|-|-|-|-|-|-|-|-|-|-|-|-|-|-|-|

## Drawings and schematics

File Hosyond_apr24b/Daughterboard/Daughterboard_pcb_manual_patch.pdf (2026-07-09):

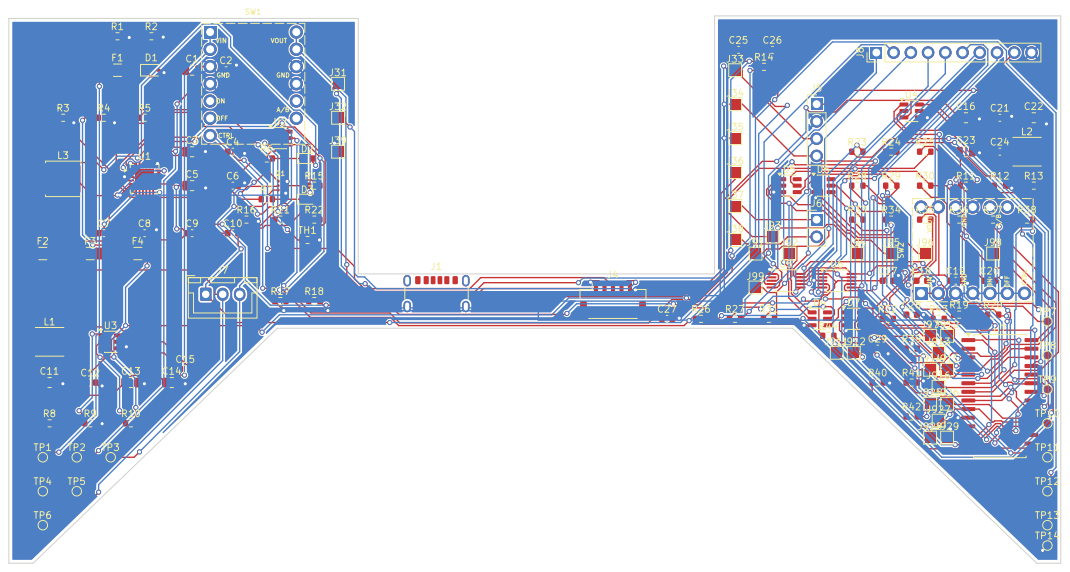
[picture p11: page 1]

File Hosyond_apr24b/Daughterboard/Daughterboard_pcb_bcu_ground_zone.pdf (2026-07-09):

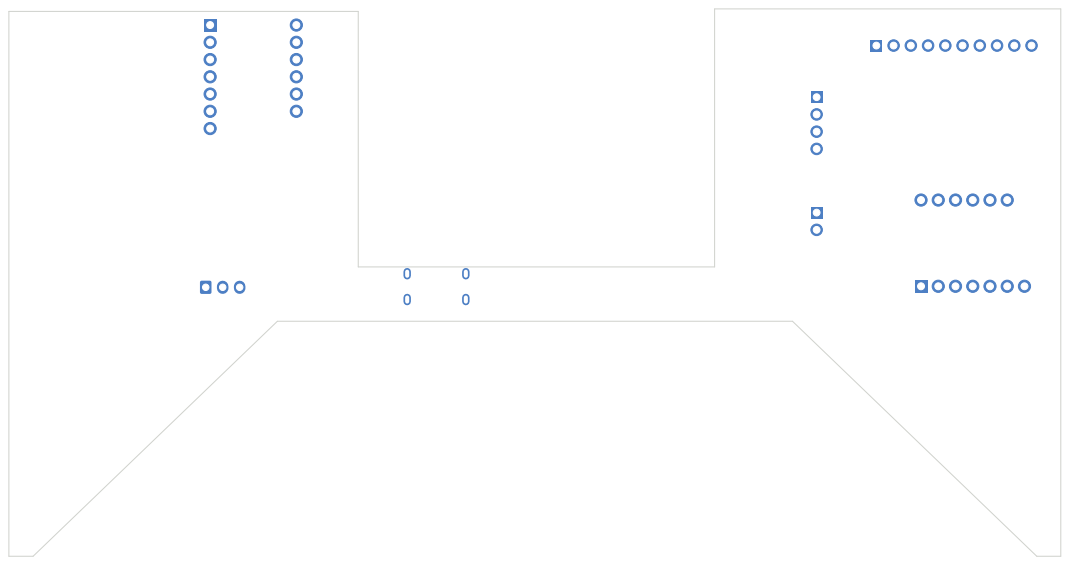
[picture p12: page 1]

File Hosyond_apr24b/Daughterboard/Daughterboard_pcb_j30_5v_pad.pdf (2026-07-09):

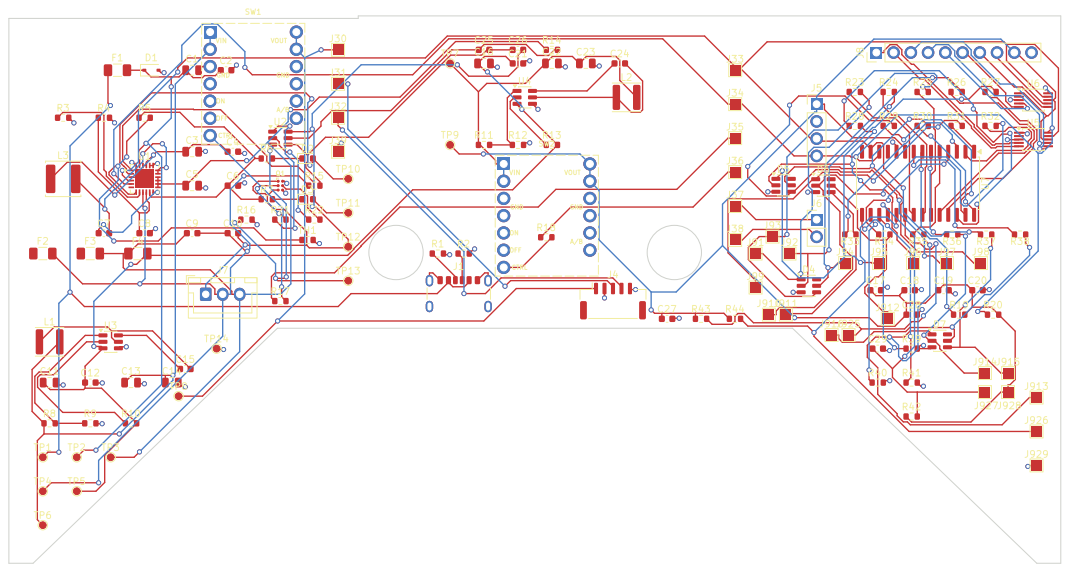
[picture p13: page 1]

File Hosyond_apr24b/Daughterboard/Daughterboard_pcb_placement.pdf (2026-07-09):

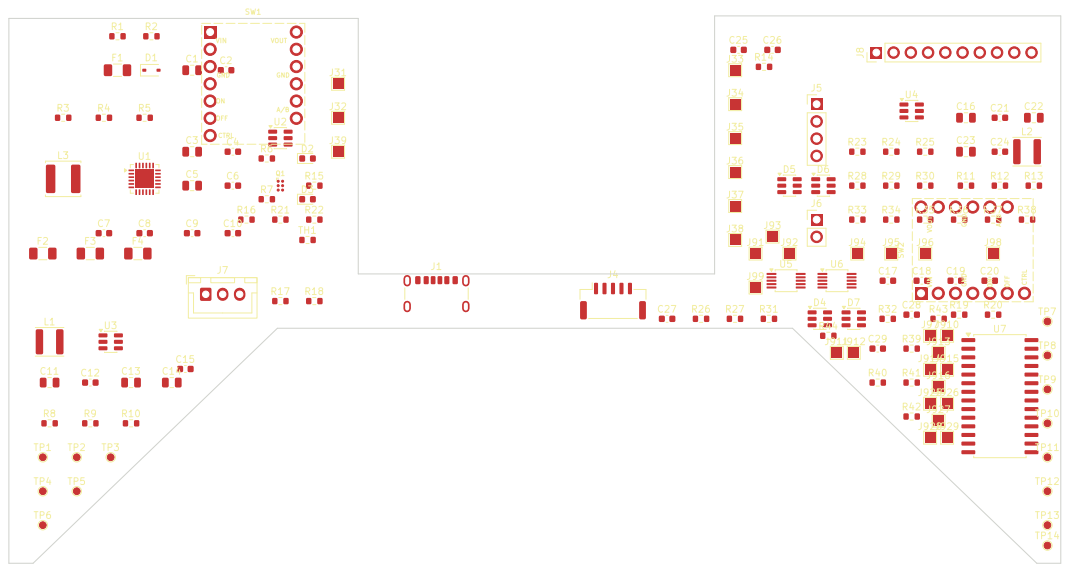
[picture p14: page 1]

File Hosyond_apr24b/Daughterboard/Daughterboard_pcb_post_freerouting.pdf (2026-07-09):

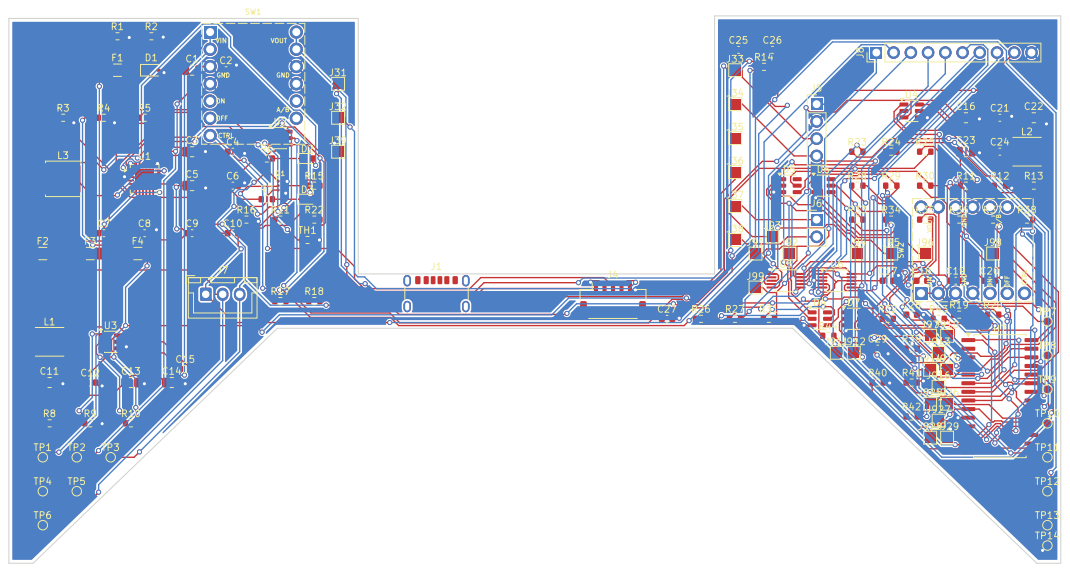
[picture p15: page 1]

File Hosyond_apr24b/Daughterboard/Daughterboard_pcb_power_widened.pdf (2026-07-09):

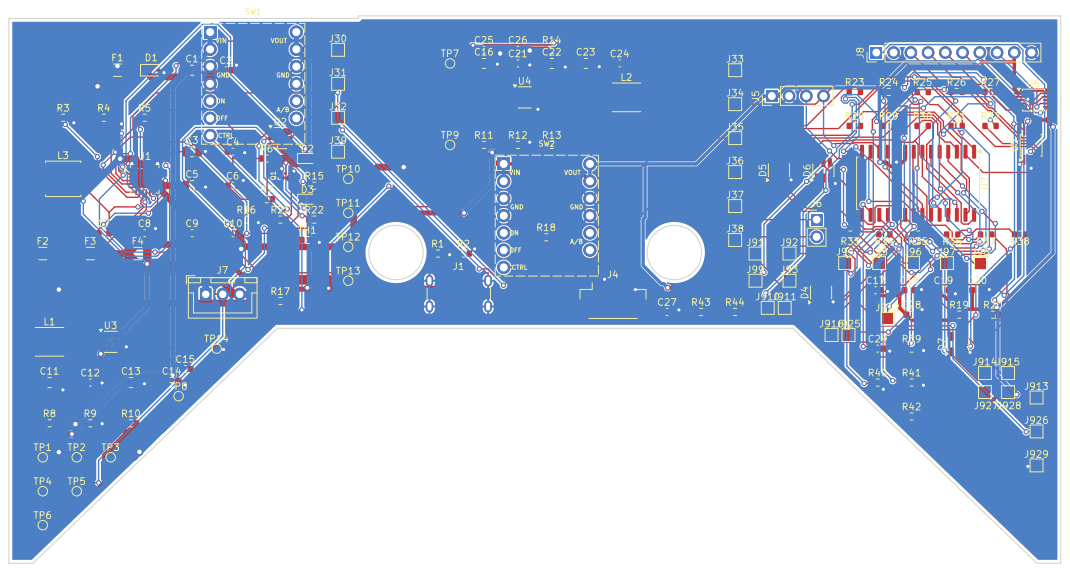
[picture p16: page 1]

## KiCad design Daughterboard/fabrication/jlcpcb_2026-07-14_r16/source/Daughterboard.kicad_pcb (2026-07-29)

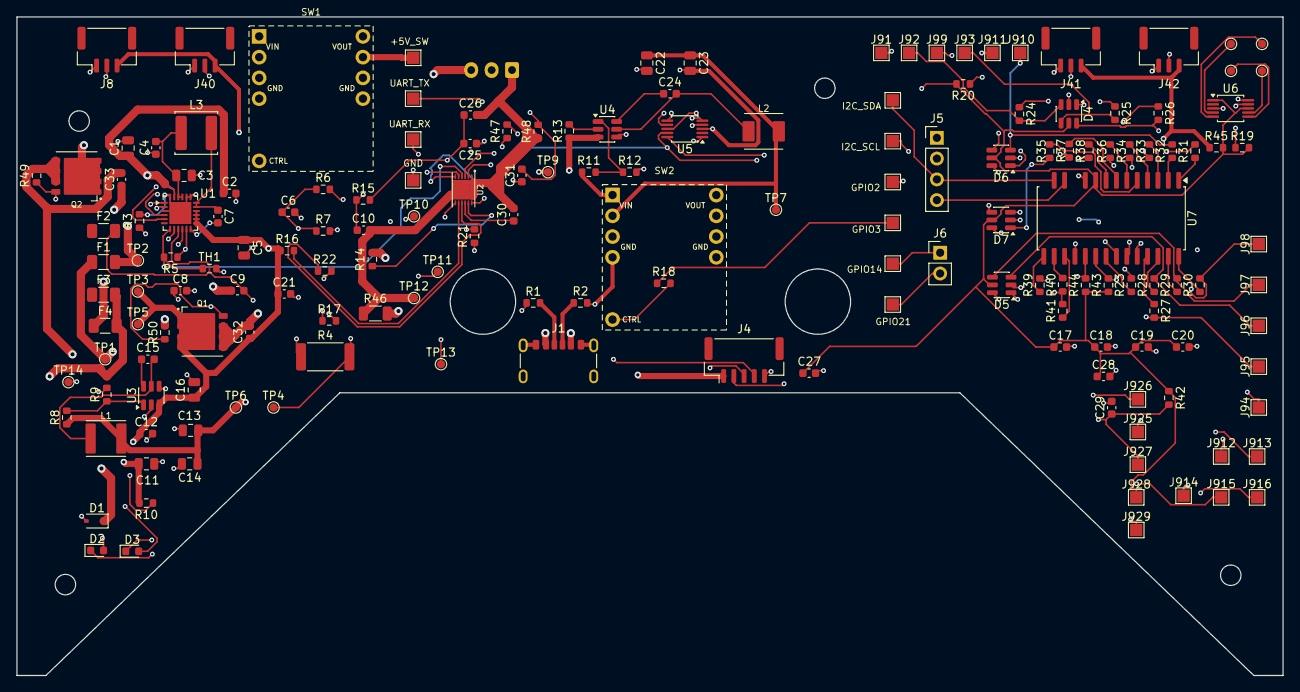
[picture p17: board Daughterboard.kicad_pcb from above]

Board: 4 copper layers, 155.0 x 80.6 mm, 166 parts (0 on the bottom side), 101 nets.

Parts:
C1: 10uF 10V X5R; C_0805_2012Metric
C2, C17, C19, C27, C29: 100nF 10V X7R; C_0603_1608Metric
C3, C5, C13, C14, C22, C23: 22uF 16V X5R; C_0805_2012Metric
C4, C7, C9, C10, C12, C15, C21, C24, C25, C26, C31: 100nF 16V X7R; C_0603_1608Metric
C6: 4.7uF 6.3V X5R; C_0603_1608Metric
C8: 100nF 10V X7R DNP; C_0603_1608Metric
C11, C16: 10uF 16V X5R; C_0805_2012Metric
C18, C20, C28: 1uF 10V X5R; C_0603_1608Metric
C30: 2.2uF 10V X5R; C_0603_1608Metric
C32, C33: 100nF 25V X7R; C_0603_1608Metric
D1: PESD5V0S1BA 5V VBUS TVS; D_SOD-323
D2: LED green; LED_0603_1608Metric
D3: LED blue; LED_0603_1608Metric
D4, D5, D6, D7: SRV05-4.TCT / C13612 4ch ESD; SOT-23-6
F1: BSMD1206-200-16V 2A hold polyfuse; Fuse_1206_3216Metric
F2: BSMD1206-200-16V cell1 PTC; Fuse_1206_3216Metric
F3: BSMD1206-200-16V cell2 PTC; Fuse_1206_3216Metric
F4: BSMD1206-200-16V system fuse; Fuse_1206_3216Metric
J1: USB-C 5V Sink; USB_C_Receptacle_GCT_USB4125-xx-x_6P_TopMnt_Horizontal
J4: BM05B-GHS-TBT UART JST-GH top-entry 1.25mm; JST_GH_BM05B-GHS-TBT_1x05-1MP_P1.25mm_Vertical
J5: I2C 2.54mm through-hole male header; PinHeader_1x04_P2.54mm_Vertical
J6: Deep sleep 2.54mm through-hole header; PinHeader_1x02_P2.54mm_Vertical
J7: 2S balance input JST-XH side-entry; JST_XH_S3B-XH-A_1x03_P2.50mm_Horizontal
J8: Left gimbal A JST-GH 1.25mm; JST_GH_BM03B-GHS-TBT_1x03-1MP_P1.25mm_Vertical
J30: J3P Hosyond +5V_SW solder pad; TestPoint_Pad_1.5x1.5mm
J31: J3A Hosyond UART_TX solder pad; TestPoint_Pad_1.5x1.5mm
J32: J3B Hosyond UART_RX solder pad; TestPoint_Pad_1.5x1.5mm
J33: J3C Hosyond I2C_SDA solder pad; TestPoint_Pad_1.5x1.5mm
J34: J3D Hosyond I2C_SCL solder pad; TestPoint_Pad_1.5x1.5mm
J35: J3E Hosyond GPIO2 solder pad; TestPoint_Pad_1.5x1.5mm
J36: J3F Hosyond GPIO3 solder pad; TestPoint_Pad_1.5x1.5mm
J37: J3G Hosyond GPIO14 solder pad; TestPoint_Pad_1.5x1.5mm
J38: J3H Hosyond GPIO21 solder pad; TestPoint_Pad_1.5x1.5mm
J39: J3I Hosyond GND solder pad; TestPoint_Pad_1.5x1.5mm
J40: Left gimbal B JST-GH 1.25mm; JST_GH_BM03B-GHS-TBT_1x03-1MP_P1.25mm_Vertical
J41: Right gimbal A JST-GH 1.25mm; JST_GH_BM03B-GHS-TBT_1x03-1MP_P1.25mm_Vertical
J42: Right gimbal B JST-GH 1.25mm; JST_GH_BM03B-GHS-TBT_1x03-1MP_P1.25mm_Vertical
J91: MCP23017 GPA0 solder pad; TestPoint_Pad_1.5x1.5mm
J92: MCP23017 GPA1 solder pad; TestPoint_Pad_1.5x1.5mm
J93: MCP23017 GPA2 solder pad; TestPoint_Pad_1.5x1.5mm
J94: MCP23017 GPA3 solder pad; TestPoint_Pad_1.5x1.5mm
J95: MCP23017 GPA4 solder pad; TestPoint_Pad_1.5x1.5mm
J96: MCP23017 GPA5 solder pad; TestPoint_Pad_1.5x1.5mm
J97: MCP23017 GPA6 solder pad; TestPoint_Pad_1.5x1.5mm
J98: MCP23017 GPA7 solder pad; TestPoint_Pad_1.5x1.5mm
J99: MCP23017 GPB0 solder pad; TestPoint_Pad_1.5x1.5mm
J910: MCP23017 GPB1 solder pad; TestPoint_Pad_1.5x1.5mm
J911: MCP23017 GPB2 solder pad; TestPoint_Pad_1.5x1.5mm
J912: MCP23017 GPB3 solder pad; TestPoint_Pad_1.5x1.5mm
J913: MCP23017 GPB4 solder pad; TestPoint_Pad_1.5x1.5mm
J914: MCP23017 GPB5 solder pad; TestPoint_Pad_1.5x1.5mm
J915: MCP23017 GPB6 solder pad; TestPoint_Pad_1.5x1.5mm
J916: MCP23017 GPB7 solder pad; TestPoint_Pad_1.5x1.5mm
J925: MCP23017 INTA solder pad; TestPoint_Pad_1.5x1.5mm
J926: MCP23017 INTB solder pad; TestPoint_Pad_1.5x1.5mm
J927: MCP23017 RESET solder pad; TestPoint_Pad_1.5x1.5mm
J928: MCP23017 +3V3_SW solder pad; TestPoint_Pad_1.5x1.5mm
J929: MCP23017 GND solder pad; TestPoint_Pad_1.5x1.5mm
L1: 4.7uH >=3A sat; CENKER_CKST0402_4.6x4.1mm
L2: 4.7uH >=2A sat; KOHERelec_MDA4020_4.45x4.1mm
L3: ANR5040T1R0M 1uH; L_APV_ANR5040
Q1: CSD18502Q5B charge FET; CSD18502Q5B_DNK0008A_VSON-CLIP_5x6mm
Q2: CSD18502Q5B discharge FET; CSD18502Q5B_DNK0008A_VSON-CLIP_5x6mm
R1, R2: 5.1k 1%; R_0603_1608Metric
R3: 806R 1% ILIM; R_0603_1608Metric
R4: 43R 1W CBSET; R_2512_6332Metric
R5: 10k 1%; R_0603_1608Metric
R6, R7: 2.2k; R_0603_1608Metric
R8: 523k 1%; R_0603_1608Metric
R9, R12: 100k 1%; R_0603_1608Metric
R10, R13: 100k; R_0603_1608Metric
R11: 316k 1%; R_0603_1608Metric
R14, R15: 470R 1%; R_0603_1608Metric
R16, R21, R22, R23, R24, R25, R26, R27, R28, R29, R30, R31, R32, R33, R34, R35, R36, R37, R38, R47, R48: 100R; R_0603_1608Metric
R17, R18: 330R; R_0603_1608Metric
R19, R20: 4.7k; R_0603_1608Metric
R39, R40, R41, R45: 0R; R_0603_1608Metric
R42, R43, R44: 10k; R_0603_1608Metric
R46: 2mR 1% 50ppm; R_1206_3216Metric
R49, R50: 10M; R_0603_1608Metric
SW1: Pololu #2808 5V switch; Pololu_2808_Raised_Header
SW2: Pololu #2808 3V3 switch; Pololu_2808_Raised_Header
TH1: NCP18XH103F03RB 10k NTC; R_0603_1608Metric
TP1: USB_VBUS test pad; TestPoint_Pad_D1.0mm
TP2: CHG_IN test pad; TestPoint_Pad_D1.0mm
TP3, TP5: BAT_SYS test pad; TestPoint_Pad_D1.0mm
TP4: CELL_MID test pad; TestPoint_Pad_D1.0mm
TP6: +5V test pad; TestPoint_Pad_D1.0mm
TP7: +3V3 test pad; TestPoint_Pad_D1.0mm
TP9: +3V3_SW test pad; TestPoint_Pad_D1.0mm
TP10: CHG_STAT test pad; TestPoint_Pad_D1.0mm
TP11: PG_STAT test pad; TestPoint_Pad_D1.0mm
TP12: BATT_RAW_N test pad; TestPoint_Pad_D1.0mm
TP13: BATT_RAW_P test pad; TestPoint_Pad_D1.0mm
TP14: GND test pad; TestPoint_Pad_D1.0mm
TP15: AIN4 test pad; TestPoint_Pad_D1.0mm
TP16: AIN5 test pad; TestPoint_Pad_D1.0mm
TP17: AIN6 test pad; TestPoint_Pad_D1.0mm
TP18: AIN7 test pad; TestPoint_Pad_D1.0mm
U1: BQ25887RGER 2S charger; Texas_RGE0024H_VQFN-24-1EP_4x4mm_P0.5mm_EP2.7x2.7mm
U2: BQ28Z610DRZR-R1; TI_DRZ0012A_VSON-12_4x2.5mm_P0.4mm
U3: AP63200WU-7 5V Buck; TSOT-23-6
U4: AP63200WU-7 3V3 Buck; TSOT-23-6
U5: ADS1115IDGSR 0x48; TSSOP-10_3x3mm_P0.5mm
U6: ADS1115IDGSR 0x49; TSSOP-10_3x3mm_P0.5mm
U7: MCP23017-E/SO; SOIC-28W_7.5x17.9mm_P1.27mm_NoPads11_14

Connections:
+3V3: C22.1, C23.1, L2.2, R11.1, SW2.1, TP7.1
+3V3_SW: J5.1, J8.3, J40.3, J41.3, J42.3, R45.1, SW2.2, TP9.1
+3V3_SW_LOGIC: C17.1, C18.1, C19.1, C20.1, C27.1, C28.1, D4.5, D5.5, D6.5, D7.5, J928.1, R19.2, R20.2, R42.1, R43.1, R44.1, R45.2, U5.8, U6.1, U6.8, U7.9
+5V: C13.1, C14.1, L1.2, R8.1, SW1.1, TP6.1
+5V_SW: J4.1, J30.1, SW1.2
AIN0: J8.2, U5.4
AIN1: J40.2, U5.5
AIN2: J41.2, U5.6
AIN3: J42.2, U5.7
AIN4: TP15.1, U6.4
AIN5: TP16.1, U6.5
AIN6: TP17.1, U6.6
AIN7: TP18.1, U6.7
BATT_RAW_N: C10.2, C26.2, C30.2, J7.1, R46.1, R48.1, TP12.1, U2.1, U2.13
BATT_RAW_P: C9.1, F3.2, F4.2, J7.3, R14.1, TP13.1
BAT_SYS: C5.1, C11.1, C12.1, C16.1, C21.1, C32.1, Q1.5, Q1.6, Q1.7, Q1.8, R10.2, R13.2, R16.1, TP3.1, TP5.1, U1.13, U1.14, U1.15, U1.16, U3.3, U4.3
BQ_CHG: R22.1, U2.9
BQ_DSG: R21.1, U2.7
BQ_PACK: R16.2, U2.8
BQ_PBI: C30.1, U2.10
BQ_SRN: C31.1, R47.2, U2.2
BQ_SRP: C31.2, R48.2, U2.3
BST_3V3: C24.1, U4.6
BST_5V: C15.1, U3.6
BTST: C7.1, U1.12
CBSET: C8.1, R4.1, U1.10
CC1: J1.A5, R1.1
CC2: J1.B5, R2.1
CELL_MID: C9.2, C10.1, F2.2, J7.2, R4.2, R15.1, TP4.1, U1.9
CHG_IN: C1.1, C2.1, D1.1, F1.2, TP2.1, U1.23
CHG_STAT: D2.2, TP10.1, U1.2
CHG_SW: C7.2, L3.2, U1.17, U1.18
CO_GATE: Q1.4, R22.2, R50.1
CTRL_3V3_SW: R18.2, SW2.4
CTRL_5V_SW: R17.2, SW1.4
DO_GATE: Q2.4, R21.2, R49.1
EN_3V3: R13.1, U4.2
EN_5V: R10.1, U3.2
EXP_GPA0: D4.1, J91.1, R23.2
EXP_GPA1: D4.3, J92.1, R24.2
EXP_GPA2: D4.4, J93.1, R25.2
EXP_GPA3: D4.6, J94.1, R26.2
EXP_GPA4: D5.1, J95.1, R27.2
EXP_GPA5: D5.3, J96.1, R28.2
EXP_GPA6: D5.4, J97.1, R29.2
EXP_GPA7: D5.6, J98.1, R30.2
EXP_GPB0: D6.1, J99.1, R31.2
EXP_GPB1: D6.3, J910.1, R32.2
EXP_GPB2: D6.4, J911.1, R33.2
EXP_GPB3: D6.6, J912.1, R34.2
EXP_GPB4: D7.1, J913.1, R35.2
EXP_GPB5: D7.3, J914.1, R36.2
EXP_GPB6: D7.4, J915.1, R37.2
EXP_GPB7: D7.6, J916.1, R38.2
FB_3V3: R11.2, R12.1, U4.1
FB_5V: R8.2, R9.1, U3.1
FET_BATT_P: C33.1, F4.1, Q2.5, Q2.6, Q2.7, Q2.8
FET_SRC_COMMON: C32.2, C33.2, Q1.1, Q1.2, Q1.3, Q2.1, Q2.2, Q2.3, R49.2, R50.2
GND: C1.2, C2.2, C3.2, C4.2, C5.2, C6.2, C8.2, C11.2, C12.2, C13.2, C14.2, C16.2, C17.2, C18.2, C19.2, C20.2, C21.2, C22.2, C23.2, C27.2, C28.2, C29.2, D1.2, D4.2, D5.2, D6.2, D7.2, J1.A12, J1.B12, J1.SH, J4.2, J4.5, J5.2, J8.1, J39.1, J40.1, J41.1, J42.1, J929.1, R1.2, R2.2, R3.2, R9.2, R12.2, R39.2, R40.2, R41.2, R46.2, R47.1, SW1.3, SW2.3, TH1.2, TP14.1, U1.3, U1.19, U1.20, U1.24, U1.25, U3.4, U4.4, U5.1, U5.3, U6.3, U7.10
GPIO2: J35.1, R17.1
GPIO3: J36.1, R18.1
GPIO14: J6.1, J37.1
GPIO21: J6.2, J38.1
I2C_SCL: J5.4, J34.1, R20.1, U1.5, U2.5, U5.10, U6.10, U7.12
I2C_SDA: J5.3, J33.1, R19.1, U1.4, U2.6, U5.9, U6.9, U7.13
ILIM: R3.1, U1.8
LED_CHG_A: D2.1, R6.2
LED_PGOOD_A: D3.1, R7.2
MCP_A0: R39.1, U7.15
MCP_A1: R40.1, U7.16
MCP_A2: R41.1, U7.17
MCP_GPA0: R23.1, U7.21
MCP_GPA1: R24.1, U7.22
MCP_GPA2: R25.1, U7.23
MCP_GPA3: R26.1, U7.24
MCP_GPA4: R27.1, U7.25
MCP_GPA5: R28.1, U7.26
MCP_GPA6: R29.1, U7.27
MCP_GPA7: R30.1, U7.28
MCP_GPB0: R31.1, U7.1
MCP_GPB1: R32.1, U7.2
MCP_GPB2: R33.1, U7.3
MCP_GPB3: R34.1, U7.4
MCP_GPB4: R35.1, U7.5
MCP_GPB5: R36.1, U7.6
MCP_GPB6: R37.1, U7.7
MCP_GPB7: R38.1, U7.8
MCP_INTA: J925.1, R43.2, U7.20
MCP_INTB: J926.1, R44.2, U7.19
MCP_RESET: C29.1, J927.1, R42.2, U7.18
PG_STAT: D3.2, TP11.1, U1.1
PMID: C3.1, C4.1, L3.1, U1.21, U1.22
PROT_VC: C25.2, C26.1, R15.2, U2.12
PROT_VDD: C25.1, R14.2, U2.11
REGN: C6.1, R5.1, R6.1, R7.1, U1.11
SW_3V3: C24.2, L2.1, U4.5
SW_5V: C15.2, L1.1, U3.5
TS: R5.2, TH1.1, U1.7, U2.4
UART_RX: J4.4, J32.1
UART_TX: J4.3, J31.1
USB_VBUS: F1.1, J1.A9, J1.B9, TP1.1

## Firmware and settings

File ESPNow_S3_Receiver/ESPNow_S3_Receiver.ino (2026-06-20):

#include <WiFi.h>
#include <esp_now.h>
#include <esp_wifi.h>
#include <Preferences.h>
#include <Wire.h>
#include <pgmspace.h>

// Board profile:
// 1 = Seeed Studio XIAO ESP32-S3 receiver, no onboard OLED/Vext/battery divider.
// 0 = legacy Heltec WiFi LoRa 32 V3 receiver behavior.
#define RECEIVER_BOARD_XIAO_ESP32S3 1

#if RECEIVER_BOARD_XIAO_ESP32S3
  #define RECEIVER_ENABLE_DISPLAY 0
  #define RECEIVER_ENABLE_BATTERY_SENSE 0
#else
  #define RECEIVER_ENABLE_DISPLAY 1
  #define RECEIVER_ENABLE_BATTERY_SENSE 1
#endif

// Receiver-side maximum accepted channel metadata. The receiver still only
// drives RC_OUTPUT_COUNT physical PWM outputs, but packets may carry fewer
// channels from older/smaller transmitters.
#define CHANNEL_COUNT 12
#define RC_OUTPUT_COUNT 4
#define ESPNOW_LINK_MAGIC 0xA614
#define ESPNOW_LINK_VERSION 2
#define ESPNOW_WIFI_CHANNEL 6
#if RECEIVER_ENABLE_DISPLAY
#define HELTEC_OLED_ADDRESS 0x3C
#define HELTEC_OLED_SDA 17
#define HELTEC_OLED_SCL 18
#define HELTEC_OLED_RST 21
#define HELTEC_VEXT_PIN 36
#define OLED_WIDTH 128
#define OLED_HEIGHT 64
#define OLED_PAGES (OLED_HEIGHT / 8)
#define OLED_FLIP_HORIZONTAL true
#define OLED_FLIP_VERTICAL false
#endif
#define DISPLAY_REFRESH_INTERVAL_MS 150
#define FAILSAFE_TIMEOUT_MS 300
#define TELEMETRY_INTERVAL_MS 100
#define TELEMETRY_KEEPALIVE_INTERVAL_MS 1000
#define BIND_BEACON_INTERVAL_MS 500
#define REBIND_BUTTON_PIN 0
#define REBIND_HOLD_MS 3000
#define RC_PWM_FREQUENCY_HZ 50
// ESP32-S3 LEDC supports up to 14-bit resolution.
#define RC_PWM_RESOLUTION_BITS 14
#define RC_PWM_MIN_US 1000
#define RC_PWM_NEUTRAL_US 1500
#define RC_PWM_MAX_US 2000
#define ESC_ARM_HOLD_MS 3000
#define IBUS_OUTPUT_PIN D5
#define IBUS_BAUD 115200
#define IBUS_CHANNEL_COUNT 14
#define IBUS_FRAME_INTERVAL_MS 7
// Set true for typical one-direction brushless ESC arming behavior (idle at minimum throttle).
// Set false for bidirectional ESC behavior (idle at neutral/center).
#define ESC_IDLE_AT_MIN_THROTTLE false

enum DriveType {
  DRIVE_TANK,
  DRIVE_CAR,
  DRIVE_OMNI,
  DRIVE_X_DRONE,
  DRIVE_QUAD_X = DRIVE_X_DRONE
};

enum TankControlMode {
  TANK_MODE_DUAL_STICK,
  TANK_MODE_RIGHT_STICK
};

enum EspNowMessageType : uint8_t {
  ESPNOW_MSG_CONTROL = 0x43,
  ESPNOW_MSG_TELEMETRY = 0x54,
  ESPNOW_MSG_PING = 0x50,
  ESPNOW_MSG_PING_ACK = 0x51,
  ESPNOW_MSG_BIND_BEACON = 0x42,
  ESPNOW_MSG_BIND_COMMIT = 0x62,
  ESPNOW_MSG_BIND_ACK = 0x41,
  ESPNOW_MSG_UNBIND = 0x55
};

enum EspNowLinkFlags : uint8_t {
  ESPNOW_FLAG_BATTERY_PRESENT = 0x01,
  ESPNOW_FLAG_BATTERY_CHARGING = 0x02,
  ESPNOW_FLAG_OUTPUT_IBUS = 0x80
};

enum ReceiverOutputMode : uint8_t {
  RECEIVER_OUTPUT_PWM = 0,
  RECEIVER_OUTPUT_IBUS = 1
};

struct __attribute__((packed)) EspNowControlPacket {
  uint16_t magic;
  uint8_t version;
  uint8_t messageType;
  uint32_t sequence;
  uint32_t txMillis;
  uint8_t modelIndex;
  uint8_t driveType;
  uint8_t tankMode;
  uint8_t flags;
  int16_t channels[CHANNEL_COUNT];
  uint16_t txBatteryMillivolts;
  uint16_t linkLatencyMs;
  char modelName[20];
};

const size_t ESPNOW_CONTROL_PREFIX_BYTES = offsetof(EspNowControlPacket, channels);
const size_t ESPNOW_CONTROL_TRAILER_BYTES =
  sizeof(((EspNowControlPacket *)0)->txBatteryMillivolts) +
  sizeof(((EspNowControlPacket *)0)->linkLatencyMs) +
  sizeof(((EspNowControlPacket *)0)->modelName);

struct __attribute__((packed)) EspNowTelemetryPacket {
  uint16_t magic;
  uint8_t version;
  uint8_t messageType;
  uint32_t sequence;
  uint32_t echoedTxMillis;
  uint16_t receiverBatteryMillivolts;
  uint16_t receiverPacketAgeMs;
  uint8_t flags;
};

struct __attribute__((packed)) EspNowBindPacket {
  uint16_t magic;
  uint8_t version;
  uint8_t messageType;
  uint32_t token;
  uint8_t flags;
};

struct __attribute__((packed)) EspNowPingPacket {
  uint16_t magic;
  uint8_t version;
  uint8_t messageType;
  uint32_t sequence;
  uint32_t txMillis;
};

struct __attribute__((packed)) EspNowPingAckPacket {
  uint16_t magic;
  uint8_t version;
  uint8_t messageType;
  uint32_t sequence;
  uint32_t echoedTxMillis;
};

#if RECEIVER_ENABLE_DISPLAY
static const uint8_t GLYPH_SPACE[5] PROGMEM = {0x00, 0x00, 0x00, 0x00, 0x00};
static const uint8_t GLYPH_DASH[5] PROGMEM = {0x08, 0x08, 0x08, 0x08, 0x08};
static const uint8_t GLYPH_DOT[5] PROGMEM = {0x00, 0x00, 0x00, 0x18, 0x18};
static const uint8_t GLYPH_COLON[5] PROGMEM = {0x00, 0x18, 0x00, 0x18, 0x00};
static const uint8_t GLYPH_SLASH[5] PROGMEM = {0x02, 0x04, 0x08, 0x10, 0x20};
static const uint8_t GLYPH_EXCL[5] PROGMEM = {0x08, 0x08, 0x08, 0x00, 0x08};
static const uint8_t GLYPH_0[5] PROGMEM = {0x3E, 0x45, 0x49, 0x51, 0x3E};
static const uint8_t GLYPH_1[5] PROGMEM = {0x00, 0x21, 0x7F, 0x01, 0x00};
static const uint8_t GLYPH_2[5] PROGMEM = {0x23, 0x45, 0x49, 0x51, 0x21};
static const uint8_t GLYPH_3[5] PROGMEM = {0x22, 0x41, 0x49, 0x49, 0x36};
static const uint8_t GLYPH_4[5] PROGMEM = {0x0C, 0x14, 0x24, 0x7F, 0x04};
static const uint8_t GLYPH_5[5] PROGMEM = {0x72, 0x51, 0x51, 0x51, 0x4E};
static const uint8_t GLYPH_6[5] PROGMEM = {0x1E, 0x29, 0x49, 0x49, 0x06};
static const uint8_t GLYPH_7[5] PROGMEM = {0x40, 0x47, 0x48, 0x50, 0x60};
static const uint8_t GLYPH_8[5] PROGMEM = {0x36, 0x49, 0x49, 0x49, 0x36};
static const uint8_t GLYPH_9[5] PROGMEM = {0x30, 0x49, 0x49, 0x4A, 0x3C};
static const uint8_t GLYPH_A[5] PROGMEM = {0x1F, 0x24, 0x44, 0x24, 0x1F};
static const uint8_t GLYPH_B[5] PROGMEM = {0x7F, 0x49, 0x49, 0x49, 0x36};
static const uint8_t GLYPH_C[5] PROGMEM = {0x3E, 0x41, 0x41, 0x41, 0x22};
static const uint8_t GLYPH_D[5] PROGMEM = {0x7F, 0x41, 0x41, 0x22, 0x1C};
static const uint8_t GLYPH_E[5] PROGMEM = {0x7F, 0x49, 0x49, 0x49, 0x41};
static const uint8_t GLYPH_F[5] PROGMEM = {0x7F, 0x48, 0x48, 0x48, 0x40};
static const uint8_t GLYPH_G[5] PROGMEM = {0x3E, 0x41, 0x49, 0x49, 0x2E};
static const uint8_t GLYPH_H[5] PROGMEM = {0x7F, 0x08, 0x08, 0x08, 0x7F};
static const uint8_t GLYPH_I[5] PROGMEM = {0x00, 0x41, 0x7F, 0x41, 0x00};
static const uint8_t GLYPH_J[5] PROGMEM = {0x02, 0x01, 0x01, 0x7E, 0x00};
static const uint8_t GLYPH_K[5] PROGMEM = {0x7F, 0x08, 0x14, 0x22, 0x41};
static const uint8_t GLYPH_L[5] PROGMEM = {0x7F, 0x01, 0x01, 0x01, 0x01};
static const uint8_t GLYPH_M[5] PROGMEM = {0x7F, 0x20, 0x18, 0x20, 0x7F};
static const uint8_t GLYPH_N[5] PROGMEM = {0x7F, 0x10, 0x08, 0x04, 0x7F};
static const uint8_t GLYPH_O[5] PROGMEM = {0x3E, 0x41, 0x41, 0x41, 0x3E};
static const uint8_t GLYPH_P[5] PROGMEM = {0x7F, 0x48, 0x48, 0x48, 0x30};
static const uint8_t GLYPH_Q[5] PROGMEM = {0x3E, 0x41, 0x45, 0x42, 0x3D};
static const uint8_t GLYPH_R[5] PROGMEM = {0x7F, 0x48, 0x4C, 0x4A, 0x31};
static const uint8_t GLYPH_S[5] PROGMEM = {0x31, 0x49, 0x49, 0x49, 0x46};
static const uint8_t GLYPH_T[5] PROGMEM = {0x40, 0x40, 0x7F, 0x40, 0x40};
static const uint8_t GLYPH_U[5] PROGMEM = {0x7E, 0x01, 0x01, 0x01, 0x7E};
static const uint8_t GLYPH_V[5] PROGMEM = {0x7C, 0x02, 0x01, 0x02, 0x7C};
static const uint8_t GLYPH_W[5] PROGMEM = {0x7E, 0x01, 0x0E, 0x01, 0x7E};
static const uint8_t GLYPH_X[5] PROGMEM = {0x63, 0x14, 0x08, 0x14, 0x63};
static const uint8_t GLYPH_Y[5] PROGMEM = {0x70, 0x08, 0x07, 0x08, 0x70};
static const uint8_t GLYPH_Z[5] PROGMEM = {0x43, 0x45, 0x49, 0x51, 0x61};

const uint8_t* glyphForChar(char c) {
  if (c >= 'a' && c <= 'z') c = (char)(c - 32);
  switch (c) {
    case 'A': return GLYPH_A; case 'B': return GLYPH_B; case 'C': return GLYPH_C;
    case 'D': return GLYPH_D; case 'E': return GLYPH_E; case 'F': return GLYPH_F;
    case 'G': return GLYPH_G; case 'H': return GLYPH_H; case 'I': return GLYPH_I;
    case 'J': return GLYPH_J; case 'K': return GLYPH_K; case 'L': return GLYPH_L;
    case 'M': return GLYPH_M; case 'N': return GLYPH_N; case 'O': return GLYPH_O;
    case 'P': return GLYPH_P; case 'Q': return GLYPH_Q; case 'R': return GLYPH_R;
    case 'S': return GLYPH_S; case 'T': return GLYPH_T; case 'U': return GLYPH_U;
    case 'V': return GLYPH_V; case 'W': return GLYPH_W; case 'X': return GLYPH_X;
    case 'Y': return GLYPH_Y; case 'Z': return GLYPH_Z;
    case '0': return GLYPH_0; case '1': return GLYPH_1; case '2': return GLYPH_2;
    case '3': return GLYPH_3; case '4': return GLYPH_4; case '5': return GLYPH_5;
    case '6': return GLYPH_6; case '7': return GLYPH_7; case '8': return GLYPH_8;
    case '9': return GLYPH_9; case '-': return GLYPH_DASH; case '.': return GLYPH_DOT;
    case ':': return GLYPH_COLON; case '/': return GLYPH_SLASH; case '!': return GLYPH_EXCL;
    default: return GLYPH_SPACE;
  }
}

struct TinyOLED {
  uint8_t buffer[OLED_WIDTH * OLED_PAGES];

  void command(uint8_t value) {
    Wire.beginTransmission(HELTEC_OLED_ADDRESS);
    Wire.write(0x00);
    Wire.write(value);
    Wire.endTransmission();
  }

  void begin() {
    pinMode(HELTEC_VEXT_PIN, OUTPUT);
    digitalWrite(HELTEC_VEXT_PIN, LOW);
    delay(20);

    pinMode(HELTEC_OLED_RST, OUTPUT);
    digitalWrite(HELTEC_OLED_RST, LOW);
    delay(20);
    digitalWrite(HELTEC_OLED_RST, HIGH);

    Wire.begin(HELTEC_OLED_SDA, HELTEC_OLED_SCL);
    Wire.setClock(400000);

    command(0xAE);
    command(0xD5); command(0x80);
    command(0xA8); command(0x3F);
    command(0xD3); command(0x00);
    command(0x40);
    command(0x8D); command(0x14);
    command(0x20); command(0x00);
    command(0xA0);
    command(0xC0);
    command(0xDA); command(0x12);
    command(0x81); command(0xCF);
    command(0xD9); command(0xF1);
    command(0xDB); command(0x40);
    command(0xA4);
    command(0xA6);
    command(0x2E);
    command(0xAF);
    clear();
    display();
  }

  void clear() {
    memset(buffer, 0, sizeof(buffer));
  }

  void setPixel(int x, int y, bool on = true) {
    if (x < 0 || x >= OLED_WIDTH || y < 0 || y >= OLED_HEIGHT) return;
    const int tx = OLED_FLIP_HORIZONTAL ? (OLED_WIDTH - 1 - x) : x;
    const int ty = OLED_FLIP_VERTICAL ? (OLED_HEIGHT - 1 - y) : y;
    const uint16_t index = tx + (ty / 8) * OLED_WIDTH;
    const uint8_t mask = 1 << (ty & 7);
    if (on) buffer[index] |= mask;
    else buffer[index] &= ~mask;
  }

  void drawChar(int x, int y, char c, uint8_t scale = 1) {
    const uint8_t* glyph = glyphForChar(c);
    for (uint8_t col = 0; col < 5; col++) {
      uint8_t bits = pgm_read_byte(glyph + col);
      for (uint8_t row = 0; row < 7; row++) {
        if (bits & (1 << row)) {
          for (uint8_t sx = 0; sx < scale; sx++) {
            for (uint8_t sy = 0; sy < scale; sy++) {
              setPixel(x + (col * scale) + sx, y + (row * scale) + sy);
            }
          }
        }
      }
    }
  }

  void drawText(int x, int y, const char* text, uint8_t scale = 1) {
    while (*text) {
      drawChar(x, y, *text, scale);
      x += 6 * scale;
      text++;
    }
  }

  int textWidth(const char* text, uint8_t scale = 1) {
    return (int)strlen(text) * 6 * scale;
  }

  void drawCenteredText(int y, const char* text, uint8_t scale = 1) {
    drawText((OLED_WIDTH - textWidth(text, scale)) / 2, y, text, scale);
  }

  void display() {
    for (uint8_t page = 0; page < OLED_PAGES; page++) {
      command(0xB0 + page);
      command(0x00);
      command(0x10);
      for (uint8_t x = 0; x < OLED_WIDTH; x += 16) {
        Wire.beginTransmission(HELTEC_OLED_ADDRESS);
        Wire.write(0x40);
        for (uint8_t i = 0; i < 16; i++) {
          Wire.write(buffer[(page * OLED_WIDTH) + x + i]);
        }
        Wire.endTransmission();
      }
    }
  }
};
#endif

const uint8_t OUTPUT_PINS[RC_OUTPUT_COUNT] = {4, 5, 6, 7};
const uint8_t OUTPUT_LEDC_CHANNEL[RC_OUTPUT_COUNT] = {0, 1, 2, 3};
// Output-to-channel map. The transmitter sends final post-mix/post-reverse
// channel values, so the receiver should only route CH1..CH4 to PWM outputs.
const uint8_t OUTPUT_SOURCE_CHANNEL[RC_OUTPUT_COUNT] = {0, 1, 2, 3};
// Per-output mode:
// true  -> unidirectional ESC mapping (idle/min at 1000us)
// false -> bidirectional servo/ESC mapping (center at 1500us)
const bool OUTPUT_UNIDIRECTIONAL_ESC[RC_OUTPUT_COUNT] = {false, false, true, false};
// Per-output failsafe/boot idle level:
// true  -> hold at minimum pulse (1000us)
// false -> hold at neutral pulse (1500us)
const bool OUTPUT_IDLE_AT_MIN_THROTTLE[RC_OUTPUT_COUNT] = {false, false, true, false};
// Per-output direction for unidirectional mapping:
// true  -> positive control value increases throttle
// false -> negative control value increases throttle
const bool OUTPUT_ESC_POSITIVE_IS_FORWARD[RC_OUTPUT_COUNT] = {true, true, true, true};
// Per-output throttle interpretation for unidirectional ESC mode:
// true  -> use only the active half of the stick for throttle (idle at 1000us at center)
// false -> map full -1..+1 range to 1000..2000
const bool OUTPUT_ESC_USE_ACTIVE_HALF_ONLY[RC_OUTPUT_COUNT] = {false, false, true, false};
// Heltec WiFi LoRa 32 V3 battery sense: GPIO37 controls the divider feeding
// GPIO1 / ADC1_CH0. Different board revisions/examples disagree on polarity,
// so the code auto-detects the state that produces a plausible LiPo voltage.
#if RECEIVER_ENABLE_BATTERY_SENSE
const int RECEIVER_BATTERY_ADC_PIN = 1;
const int RECEIVER_BATTERY_ADC_CTRL_PIN = 37;
const float RECEIVER_BATTERY_DIVIDER_RATIO = 4.9f;
#else
const int RECEIVER_BATTERY_ADC_PIN = -1;
const int RECEIVER_BATTERY_ADC_CTRL_PIN = -1;
const float RECEIVER_BATTERY_DIVIDER_RATIO = 1.0f;
#endif
const float RECEIVER_BATTERY_EMPTY_V = 3.30f;
const float RECEIVER_BATTERY_FULL_V = 4.20f;
const uint16_t RECEIVER_BATTERY_PRESENT_MIN_MV = 2500;
const uint16_t RECEIVER_BATTERY_PRESENT_MAX_MV = 5200;
const uint8_t ESPNOW_BROADCAST_ADDRESS[ESP_NOW_ETH_ALEN] = {
  0xFF, 0xFF, 0xFF, 0xFF, 0xFF, 0xFF
};

#if RECEIVER_ENABLE_DISPLAY
TinyOLED display;
#endif

Preferences receiverPrefs;
HardwareSerial ibusSerial(1);
portMUX_TYPE controlPacketMux = portMUX_INITIALIZER_UNLOCKED;
EspNowControlPacket latestControlPacket = {};
uint8_t latestControlChannelCount = 0;
bool hasControlPacket = false;
bool telemetryPending = false;
bool senderPeerReady = false;
bool receiverBound = false;
bool rebindTriggered = false;
unsigned long lastBindBeaconTime = 0;
unsigned long lastPacketMillis = 0;
unsigned long lastTelemetrySendTime = 0;
unsigned long rebindButtonPressStart = 0;
unsigned long escArmHoldStart = 0;
bool escArmHoldActive = true;
uint8_t lastSenderMac[6] = { 0, 0, 0, 0, 0, 0 };
uint8_t boundTransmitterMac[6] = { 0, 0, 0, 0, 0, 0 };
uint16_t lastOutputPulseUs[RC_OUTPUT_COUNT] = { RC_PWM_NEUTRAL_US, RC_PWM_NEUTRAL_US, RC_PWM_NEUTRAL_US, RC_PWM_NEUTRAL_US };
bool outputPwmAttached[RC_OUTPUT_COUNT] = { false, false, false, false };
bool outputUseChannelWrite[RC_OUTPUT_COUNT] = { false, false, false, false };
ReceiverOutputMode receiverOutputMode = RECEIVER_OUTPUT_PWM;
bool ibusStarted = false;
uint16_t ibusChannels[IBUS_CHANNEL_COUNT] = {};
unsigned long lastIbusFrameTime = 0;
uint32_t ibusFrameCount = 0;
uint32_t pwmWriteFailureCount = 0;
bool displayReady = false;
unsigned long lastDisplayRefreshTime = 0;

bool initEspNowReceiver();
bool setEspNowWifiChannel(uint8_t channel);
bool ensureSenderPeer(const uint8_t *macAddress);
bool ensureBroadcastPeer();
void loadReceiverBinding();
void saveReceiverBinding();
void clearReceiverBinding();
void loadReceiverOutputMode();
void saveReceiverOutputMode();
void setReceiverOutputMode(ReceiverOutputMode mode, bool persist);
bool parseEspNowControlPacket(const uint8_t *data, int len, EspNowControlPacket &packet, uint8_t &channelCount);
void applyControlPacket(const EspNowControlPacket &packet);
void applyFailsafeOutputs();
void writeRcPulseUs(int channelIndex, uint16_t pulseUs);
void stopRcPwmOutputs();
void initIbusOutput();
void stopIbusOutput();
void applyIbusFailsafe();
void updateIbusOutputFromPacket(const EspNowControlPacket &packet);
void sendIbusFrameIfDue(unsigned long now);
uint16_t normalizedToPulseUs(float value);
uint16_t normalizedToPulseUsForOutput(float value, int outputIndex);
uint32_t pulseUsToDuty(uint16_t pulseUs);
float packetValueToNormalized(int16_t value);
uint16_t readReceiverBatteryMillivoltsWithCtrl(int ctrlLevel);
uint16_t readReceiverBatteryMillivolts();
int receiverBatteryPercentFromMillivolts(uint16_t millivolts);
void sendTelemetryPacket(unsigned long now);
void sendBindBeacon(unsigned long now);
void sendBindAck(const uint8_t *macAddress, uint32_t token);
void sendPingAck(const uint8_t *macAddress, uint32_t sequence, uint32_t echoedTxMillis);
void updateRebindButton(unsigned long now);
void onEspNowReceive(const esp_now_recv_info_t *info, const uint8_t *data, int len);
void initRcPwmOutputs();
void initReceiverDisplay();
void updateReceiverDisplay(unsigned long now, bool packetFresh);
const char* driveTypeLabel(uint8_t driveType);
void copyPacketModelName(const EspNowControlPacket &packet, char *buffer, size_t bufferSize);

#if ESP_IDF_VERSION >= ESP_IDF_VERSION_VAL(5, 5, 0)
void onEspNowSend(const esp_now_send_info_t *tx_info, esp_now_send_status_t status) {
  (void)tx_info;
  (void)status;
}
#else
void onEspNowSend(const uint8_t *macAddress, esp_now_send_status_t status) {
  (void)macAddress;
  (void)status;
}
#endif

bool setEspNowWifiChannel(uint8_t channel) {
  if (WiFi.setChannel(channel)) {
    return true;
  }

  esp_err_t promiscOn = esp_wifi_set_promiscuous(true);
  esp_err_t setChan = esp_wifi_set_channel(channel, WIFI_SECOND_CHAN_NONE);
  esp_err_t promiscOff = esp_wifi_set_promiscuous(false);

  if (promiscOn == ESP_OK && setChan == ESP_OK && promiscOff == ESP_OK) {
    return true;
  }

  Serial.printf("Failed to set ESP-NOW channel (set=%d on=%d off=%d)\n",
                (int)setChan, (int)promiscOn, (int)promiscOff);
  return false;
}
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
void loop() {
  unsigned long now = millis();

  updateRebindButton(now);

  bool packetFresh = hasControlPacket && (now - lastPacketMillis <= FAILSAFE_TIMEOUT_MS);

  if (escArmHoldActive && (now - escArmHoldStart >= ESC_ARM_HOLD_MS)) {
    escArmHoldActive = false;
  }

  if (escArmHoldActive) {
    applyFailsafeOutputs();
  } else if (packetFresh) {
    EspNowControlPacket packetCopy = {};
    portENTER_CRITICAL(&controlPacketMux);
    packetCopy = latestControlPacket;
    portEXIT_CRITICAL(&controlPacketMux);
    applyControlPacket(packetCopy);
  } else {
    applyFailsafeOutputs();
  }
  sendIbusFrameIfDue(now);

  sendBindBeacon(now);
  sendTelemetryPacket(now);
  updateReceiverDisplay(now, packetFresh);

  static unsigned long lastDebugTime = 0;
  if (now - lastDebugTime >= 1000) {
    lastDebugTime = now;
    Serial.print("Link ");
    Serial.print(packetFresh ? "OK" : "FAILSAFE");
    Serial.print(" | age ");
    Serial.print(packetFresh ? (now - lastPacketMillis) : FAILSAFE_TIMEOUT_MS);
    Serial.print(" ms | bind ");
    Serial.print(receiverBound ? "BOUND" : "WAITING");
    Serial.print(" | battery ");
    uint16_t batteryMv = readReceiverBatteryMillivolts();
    if (batteryMv > 0) {
      Serial.print(batteryMv / 1000.0f, 2);
      Serial.println(" V");
    } else {
      Serial.println("n/a");
    }

    if (receiverOutputMode == RECEIVER_OUTPUT_IBUS) {
      Serial.print("iBUS out D5/GPIO");
      Serial.print(IBUS_OUTPUT_PIN);
      Serial.print(" frames=");
      Serial.print(ibusFrameCount);
      Serial.print(" ch [");
      for (int i = 0; i < min(6, IBUS_CHANNEL_COUNT); i++) {
        if (i > 0) Serial.print(", ");
        Serial.print(ibusChannels[i]);
      }
      Serial.println("]");
    } else {
      Serial.print("PWM us [");
      for (int i = 0; i < RC_OUTPUT_COUNT; i++) {
        if (i > 0) Serial.print(", ");
        Serial.print("GPIO");
        Serial.print(OUTPUT_PINS[i]);
        Serial.print(":");
        Serial.print(lastOutputPulseUs[i]);
      }
      Serial.println("]");
    }

    if (hasControlPacket) {
      EspNowControlPacket debugPacket = {};
      uint8_t debugChannelCount = 0;
      portENTER_CRITICAL(&controlPacketMux);
      debugPacket = latestControlPacket;
      debugChannelCount = latestControlChannelCount;
      portEXIT_CRITICAL(&controlPacketMux);

      Serial.print("RX ch raw [");
      for (int i = 0; i < debugChannelCount; i++) {
        if (i > 0) Serial.print(", ");
        Serial.print(debugPacket.channels[i]);
      }
      Serial.print("] count=");
      Serial.print(debugChannelCount);
      Serial.print(" drive=");
      Serial.print(driveTypeLabel(debugPacket.driveType));
      Serial.print(" tankMode=");
      Serial.print(debugPacket.tankMode);
      Serial.print(" model=");
      char debugModelName[24];
      copyPacketModelName(debugPacket, debugModelName, sizeof(debugModelName));
      Serial.print(debugModelName);
      Serial.print(" latency=");
      Serial.println(debugPacket.linkLatencyMs);
    }

    if (receiverOutputMode == RECEIVER_OUTPUT_PWM) {
      Serial.print("PWM attach [");
      for (int i = 0; i < RC_OUTPUT_COUNT; i++) {
        if (i > 0) Serial.print(", ");
        Serial.print("GPIO");
        Serial.print(OUTPUT_PINS[i]);
        Serial.print(":");
        Serial.print(outputPwmAttached[i] ? "OK" : "FAIL");
        Serial.print("/");
        Serial.print(outputUseChannelWrite[i] ? "ch" : "pin");
      }
      Serial.println("]");
    }

    if (receiverOutputMode == RECEIVER_OUTPUT_PWM && pwmWriteFailureCount > 0) {
      Serial.print("PWM write failures: ");
      Serial.println(pwmWriteFailureCount);
    }
  }

  delay(5);
}

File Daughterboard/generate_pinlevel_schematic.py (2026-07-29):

from __future__ import annotations

import csv
from urllib.parse import quote_plus
import uuid
from dataclasses import dataclass
from pathlib import Path


ROOT_UUID = "d4b0641a-9c05-4a64-9f99-e24c4b75c101"
PROJECT = "Daughterboard"
LAYOUT_SCALE_X = 1.3
LAYOUT_SCALE_Y = 1.2


def uid() -> str:
    return str(uuid.uuid4())


@dataclass(frozen=True)
class Pin:
    number: str
    name: str
    side: str
    offset: float
    kind: str = "passive"


@dataclass(frozen=True)
class SymbolDef:
    name: str
    ref_prefix: str
    value: str
    footprint: str
    datasheet: str
    description: str
    width: float
    height: float
    pins: tuple[Pin, ...]
    in_bom: bool = True
    on_board: bool = True


@dataclass(frozen=True)
class Part:
    symbol: str
    ref: str
    value: str
    footprint: str
    x: float
    y: float
    nets: dict[str, str | None]
    datasheet: str = ""
    description: str = ""
    section: str = ""
    notes: str = ""
    in_bom: bool = True
    on_board: bool = True


def q(text: str) -> str:
    return text.replace("\\", "\\\\").replace('"', '\\"')


def snap(num: float) -> float:
    return round(num / 1.27) * 1.27


def fmt(num: float) -> str:
    num = snap(num)
    return f"{num:.3f}".rstrip("0").rstrip(".")


def prop(name: str, value: str, x: float, y: float, hide: bool = False) -> str:
    hide_s = " (hide yes)" if hide else ""
    return (
        f'\t\t(property "{q(name)}" "{q(value)}"\n'
        f"\t\t\t(at {fmt(x)} {fmt(y)} 0)\n"
        f"\t\t\t(effects (font (size 1.016 1.016)){hide_s} (justify left))\n"
        "\t\t)\n"
    )


def pin_xy(sym: SymbolDef, pin: Pin) -> tuple[float, float, int]:
    hw = sym.width / 2
    hh = sym.height / 2
    if pin.side == "L":
        return snap(-hw - 5.08), snap(pin.offset), 0
    if pin.side == "R":
        return snap(hw + 5.08), snap(pin.offset), 180
    if pin.side == "T":
        return snap(pin.offset), snap(-hh - 5.08), 90
    if pin.side == "B":
        return snap(pin.offset), snap(hh + 5.08), 270
    raise ValueError(pin.side)


def stub_xy(sym: SymbolDef, pin: Pin, x: float, y: float) -> tuple[float, float]:
    px, py, _ = pin_xy(sym, pin)
    sx = x + px
    sy = y - py
    if pin.side == "L":
        return sx - 5.08, sy
    if pin.side == "R":
        return sx + 5.08, sy
    if pin.side == "T":
        return sx, sy - 5.08
    if pin.side == "B":
        return sx, sy + 5.08
    raise ValueError(pin.side)


def draw_pin(pin: Pin, sym: SymbolDef) -> str:
    x, y, angle = pin_xy(sym, pin)
    return (
        f"\t\t\t(pin {pin.kind} line\n"
        f"\t\t\t\t(at {fmt(x)} {fmt(y)} {angle})\n"
        "\t\t\t\t(length 5.08)\n"
        f'\t\t\t\t(name "{q(pin.name)}" (effects (font (size 1.016 1.016))))\n'
        f'\t\t\t\t(number "{q(pin.number)}" (effects (font (size 1.016 1.016))))\n'
        "\t\t\t)\n"
    )


def symbol_def(sym: SymbolDef, embedded: bool = True) -> str:
    name = f"Daughterboard:{sym.name}" if embedded else sym.name
    out = [
        f'\t\t(symbol "{name}"\n',
        "\t\t\t(exclude_from_sim no)\n",
        f"\t\t\t(in_bom {'yes' if sym.in_bom else 'no'})\n",
        f"\t\t\t(on_board {'yes' if sym.on_board else 'no'})\n",
        "\t\t\t(duplicate_pin_numbers_are_jumpers no)\n",
        f'\t\t\t(property "Reference" "{q(sym.ref_prefix)}"\n',
        f"\t\t\t\t(at {fmt(-sym.width / 2)} {fmt(-sym.height / 2 - 7.62)} 0)\n",
        "\t\t\t\t(effects (font (size 1.27 1.27)))\n",
        "\t\t\t)\n",
        f'\t\t\t(property "Value" "{q(sym.value)}"\n',
        f"\t\t\t\t(at {fmt(-sym.width / 2)} {fmt(sym.height / 2 + 7.62)} 0)\n",
        "\t\t\t\t(effects (font (size 1.27 1.27)))\n",
        "\t\t\t)\n",
        f'\t\t\t(property "Footprint" "{q(sym.footprint)}"\n',
        "\t\t\t\t(at 0 0 0)\n",
        "\t\t\t\t(effects (font (size 1.27 1.27)) (hide yes))\n",
        "\t\t\t)\n",
        f'\t\t\t(property "Datasheet" "{q(sym.datasheet)}"\n',
        "\t\t\t\t(at 0 0 0)\n",
        "\t\t\t\t(effects (font (size 1.27 1.27)) (hide yes))\n",
        "\t\t\t)\n",
        f'\t\t\t(property "Description" "{q(sym.description)}"\n',
        "\t\t\t\t(at 0 0 0)\n",
        "\t\t\t\t(effects (font (size 1.27 1.27)) (hide yes))\n",
        "\t\t\t)\n",
        f'\t\t\t(symbol "{sym.name}_0_1"\n',
        f"\t\t\t\t(rectangle (start {fmt(-sym.width / 2)} {fmt(-sym.height / 2)}) "
        f"(end {fmt(sym.width / 2)} {fmt(sym.height / 2)}) "
        "(stroke (width 0.254) (type default)) (fill (type background)))\n",
    ]
    if sym.width >= 20 and sym.height >= 15:
        out.extend(
            [
                f'\t\t\t\t(text "{q(sym.value)}"\n',
                "\t\t\t\t\t(at 0 0 0)\n",
                "\t\t\t\t\t(effects (font (size 1.27 1.27) (bold yes)))\n",
                "\t\t\t\t)\n",
            ]
        )
    out.extend(
        [
            "\t\t\t)\n",
            f'\t\t\t(symbol "{sym.name}_1_1"\n',
        ]
    )
    for pin in sym.pins:
        out.append(draw_pin(pin, sym))
    out.append("\t\t\t)\n")
    out.append("\t\t)\n")
    return "".join(out)


def part_instance(part: Part, sym: SymbolDef) -> str:
    x, y = part.x, part.y
    field_x = x - sym.width / 2
    field_y = y - sym.height / 2 - 8.89
    out = [
        "\t(symbol\n",
        f'\t\t(lib_id "Daughterboard:{part.symbol}")\n',
        f"\t\t(at {fmt(x)} {fmt(y)} 0)\n",
        "\t\t(unit 1)\n",
        "\t\t(exclude_from_sim no)\n",
        f"\t\t(in_bom {'yes' if part.in_bom else 'no'})\n",
        f"\t\t(on_board {'yes' if part.on_board else 'no'})\n",
        "\t\t(dnp no)\n",
        f'\t\t(uuid "{uid()}")\n',
        prop("Reference", part.ref, field_x, field_y),
        prop("Value", part.value, field_x, field_y + 2.54),
        prop("Footprint", part.footprint, x, y, True),
        prop("Datasheet", part.datasheet, x, y, True),
        prop("Purchase Link", purchase_link_for(part), x, y, True),
        "\t\t(instances\n",
        f'\t\t\t(project "{PROJECT}"\n',
        f'\t\t\t\t(path "/{ROOT_UUID}" (reference "{part.ref}") (unit 1))\n',
        "\t\t\t)\n",
        "\t\t)\n",
        "\t)\n",
    ]
    return "".join(out)
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

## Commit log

2026-05-15 ota build
    [partitions.csv]
2026-06-04 heltec v3 update
    [.step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]
2026-06-20 project update
    [.step, Hosyond_carrier_connector_inventory.csv, Hosyond_carrier_kicad_label_checklist.csv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]
2026-07-09 pcb review
    [Daughterboard_jlcpcb_bom_jlc_ready_draft.csv, daughterboard.kicad_pcb]
2026-07-11 r15 cut
    [Daughterboard_jlcpcb_bom_jlc_ready.csv, Daughterboard_jlcpcb_bom_jlc_ready_draft.csv, Daughterboard_kicad_bom.csv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]
2026-07-11 r15 revised
    [Daughterboard_jlcpcb_bom_jlc_ready.csv, Daughterboard_jlcpcb_bom_jlc_ready_draft.csv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]
2026-07-11 Add JLCPCB send bundle for Daughterboard r15
    Upload-ready gerber/drill zip, BOM, and CPL plus README with order
    settings and hand-install parts (J5/J6, SW1/SW2).
    [2_Daughterboard_r15_BOM.csv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]
